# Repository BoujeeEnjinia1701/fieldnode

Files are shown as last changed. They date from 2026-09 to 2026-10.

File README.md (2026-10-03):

# FieldNode

     

**Area:** Shared Components · **TRL:** 3 of 9 (proof of concept on paper) · **Value-engineering target:** about $150 USD · **Difficulty:** 3 of 5

A solar-powered, weatherproof sensor node with a common mounting, power and radio core, so any lab project that needs to measure something outdoors starts from the same tested base instead of a new enclosure and charger each time.

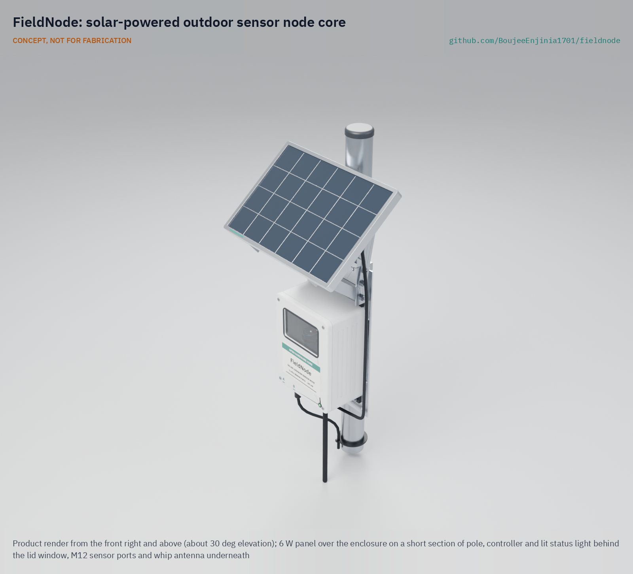
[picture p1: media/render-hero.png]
FieldNode: solar-powered outdoor sensor node core, product render


[Exploded render](media/render-exploded.png) · [Detail render](media/render-detail.png) · [Interactive 3D model](media/viewer.html) · [Concept blueprint (PDF)](media/concept-blueprint.pdf) · [General arrangement (PDF)](cad/drawings/FND-DWG-001.pdf) · [Calculations](docs/04-calcs/01-sizing.md) · [Prototype build plan](docs/05-build-plan.md) · [Review note](docs/REVIEW.md)

## Concept rationale

Outdoor sensing projects in the lab fail for the same few reasons: water gets in, the battery runs flat in a cloudy week, the charger overheats or will not charge in the cold, or the radio link drops. FieldNode solves these once. It pairs a stock IP65 enclosure with a 6 W panel that also hoods the box, a single LiFePO4 cell, an MPPT charger with a cold-charge lockout, and an STM32WL-class LoRaWAN module, with two sealed sensor ports. Each project then designs only its sensor and firmware, and a fix found in one deployment reaches all of them.

Keeping it open and garage-buildable matters because the users who most need monitoring are the least able to buy closed commercial nodes or pay for their clouds. Every part is off the shelf or cut from aluminium bar, angle and sheet with hand tools, the design files are under CERN-OHL-S-2.0, and the node talks to any LoRaWAN server, including the lab's TwinKit gateway and The Things Network.

## Burning platform

Monitoring is thinnest where hazards are greatest. Germany has more stations meeting the WMO Global Basic Observing Network standard than the whole of Africa ([WMO](https://wmo.int/media/news/closing-gaps-observing-network)). Only 108 countries, 55 % of the total, reported multi-hazard early warning systems in 2024, and fewer than half of the least developed countries did ([UNDRR and WMO, 2024](https://www.undrr.org/reports/global-status-MHEWS-2024)). The same report found that countries with limited early warning coverage have disaster mortality nearly six times higher than those with substantial coverage.

For air quality, 37 % of countries do not legally require monitoring at all ([UNEP, 2021](https://www.unep.org/news-and-stories/press-release/one-three-countries-world-lack-any-legally-mandated-standards)). Low-cost nodes can help close these gaps only if they survive in the field; long-running deployments report water ingress, cold-weather charging failures and radio problems as the main causes of lost data ([Barrenetxea et al., SenSys 2008](https://gsfr.github.io/pdf/sensys2008.pdf)).

## Where it could be used

### By industry

| Industry | Use |
| --- | --- |
| Water utilities and water resources | River, drain and well level logging (FloodGauge, WellSense, WaterWatch) |
| Disaster risk and civil protection | Slope movement, flood and heat sensing that feeds local early warning (SlopeWatch, HeatMap Node) |
| Municipal services and smart cities | Air, noise, parking and curb sensing on street poles, counts or levels only (AirStreet, NoiseMap, CurbCount, LoadZone) |
| Civil infrastructure and mining | Bridge vibration, tailings dam and pit wall tilt monitoring (BridgePulse, SlopeWatch) |
| Agriculture | Soil moisture, microclimate and grain store conditions at farms without power |
| Research and education | A documented, repeatable field platform for university and school projects |

### By country or region

| Country or region | Why it matters there |
| --- | --- |
| Sub-Saharan Africa | Weather observation is sparse: Germany alone has more GBON-standard stations than the whole continent ([WMO](https://wmo.int/media/news/closing-gaps-observing-network)). |
| India | Only about 12 % of 4,041 census cities and towns have air quality monitoring stations ([CSE, 2023](https://www.cseindia.org/only-12-per-cent-of-india-s-census-cities-and-towns-have-air-quality-monitoring-stations-11779)). |
| Least developed countries and small island states | Fewer than half of least developed countries report multi-hazard early warning systems; about two thirds of small island developing states do ([UNDRR and WMO, 2024](https://www.undrr.org/reports/global-status-MHEWS-2024)). |
| United States | The USGS runs about 12,165 streamgages ([USGS](https://www.usgs.gov/mission-areas/water-resources/science/usgs-national-streamgaging-network)), yet small streams, farm drains and urban culverts are mostly ungauged; low-cost nodes can fill local gaps. |
| European Union and United Kingdom | Dense official networks exist, but LoRa nodes must respect 1 % duty-cycle sub-bands in EU868 ([TTN, citing ETSI EN 300 220](https://www.thethingsnetwork.org/docs/lorawan/duty-cycle/)), so an open reference that stays within the rules is useful to community sensing groups. |

## What sparked the idea

The idea traces back to one of the first long outdoor wireless sensor deployments, on Great Duck Island, Maine, in 2003. Its 150 battery-powered nodes in sealed enclosures showed where field nodes fail: when the enclosures were opened, 22 % of the weather nodes had visible water droplets inside, and the multi-hop burrow nodes reached a median life of 34 days, under 45 % of their estimate ([Szewczyk et al., SenSys 2004](https://patpannuto.com/papers/szewczyk2004greatduckisland.pdf)). None of those failures came from the sensors; they came from the box, the seal and the power budget. FieldNode starts from that lesson: solve the enclosure, the energy budget and the radio once, check them on paper, and let every outdoor sensing project reuse the answer.

## Problem

Every outdoor sensing project rebuilds the same things: an enclosure that survives sun and rain, a small solar charger, a battery that lasts the night, and a low-power radio. Commercial nodes are closed or costly, and one-off builds fail in the field for the same few reasons.

## Concept

A solar-powered, weatherproof sensor node with a common mounting, power and radio core, so any lab project that needs to measure something outdoors starts from the same tested base instead of a new enclosure and charger each time.

Full design precis: [docs/02-concept.md](docs/02-concept.md)

## Key components

- IP65 polycarbonate enclosure, 150 x 90 x 200 mm, with membrane vent and two cable glands
- 6 W, 9 V class solar panel on a tilt bracket, doubling as a rain hood
- Ventilated white sun shield, fitted at hot-climate sites only
- LiFePO4 cell, 3.2 V 6 Ah, fused, with a 0 to 45 °C charge lockout
- MPPT charge and power board with switched 3.3, 5 and 12 V sensor rails and a serial programming header, reached with the lid open
- STM32WL-class microcontroller with LoRaWAN radio (US915 first variant, 915 MHz whip) and SPI flash for store and forward
- Two sealed M12 sensor ports with a proposed standard pinout (pin 1 switched rail, 2 data A, 3 ground, 4 data B, 5 analog), awaiting sign-off by the adopting projects
- Pole and wall mounting kit for 40 to 60 mm poles

TRL 3 calculations ([FND-CAL-001](docs/04-calcs/01-sizing.md)): in the worst month (2 peak sun hours) the cell stores 7.75 Wh a day against 2.67 Wh drawn at the published 100 mW sensor allowance, and a full cell lasts 5.75 days without sun. The base node costs $139.50 in parts and weighs 2.45 kg. At sites whose design maximum exceeds 30 °C a ventilated white sun shield is fitted ($148.50 and 2.61 kg in all), which keeps the inside at or below about 52 °C in 45 °C sun so the cell can still charge. The panel is 9 V class so the charger keeps its input voltage when hot, and firmware lengthens the reporting interval at slow spreading factors to stay within The Things Network's fair use. Two requirements remain at risk: charging on very cold days and autonomy with a cold or aged cell. See the [requirements](docs/03-requirements.md).

The working bill of materials is in [bom/bom.csv](bom/bom.csv).

## Building the prototype

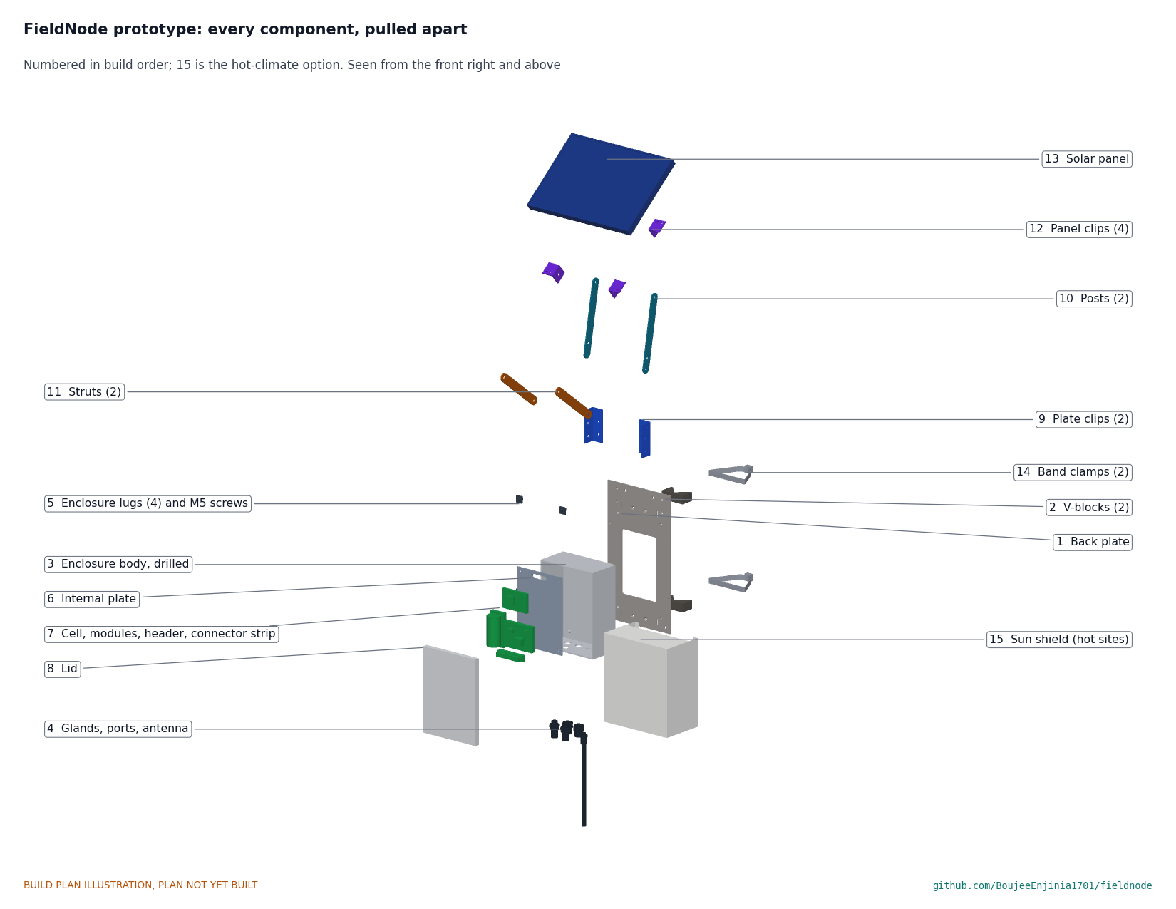
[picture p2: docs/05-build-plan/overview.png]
FieldNode prototype: every component pulled apart and numbered in build order


The [prototype build plan](docs/05-build-plan.md) (FND-BLD-001) shows, in pictures, how to make each of the fifteen components and put them together in twelve steps; nothing has been built yet. The made parts are an aluminium back plate and V-blocks, a bracket of angle clips and flat bars, a printed internal plate and a folded white sun shield; the bought box is drilled, and the electronics are bought modules wired at block level. Writing the plan made the design buildable: the V-blocks, the holes in the bottom of the box, the bracket joints and the shield fixing were redesigned, and fixings, a connector strip and sensor-supply fuses were added (FND-DDR-003, open for Amish's review). Every picture is drawn from the model, and the model checks that each part touches what it should and clears what it should not.

## Safety

> Lithium cells can overheat, vent and burn. Use protected cells or LiFePO4, fuse every pack, charge only within the cell maker's limits (for LiFePO4, typically 0 to 45 °C) and never leave a first build charging unattended.
>
> Mounting is work at height: use a stable ladder with a second person present, keep clear of overhead power lines, and check the pole or wall can carry the wind load on the panel.

## Repository layout

| Folder | Contents |
| --- | --- |
| `docs/` | Problem, concept, requirements, calculations and design decisions |
| `cad/src/` | build123d Python source, the source of truth for all geometry |
| `cad/step/`, `cad/stl/` | Exported models for FreeCAD, other CAD tools and printing |
| `cad/drawings/` | 2D sketches and dimensioned drawings |
| `bom/` | Bill of materials |
| `electronics/` | KiCad schematics and PCB layouts |
| `firmware/` | Microcontroller code |
| `media/` | Renders, perspectives and photos |
| `build-log/` | Dated prototyping notes |

## Documentation

Controlled documents follow the portfolio [documentation standard](.kit/STANDARDS.md). Each carries a document ID (FND-PRC-001 for the precis), a version and a revision history. Branded PDFs are built with `python .kit/render.py` and attached to GitHub Releases when a document is tagged, for example `FND-PRC-001/v1.0`.

## Credits

Designed by Amish Chadha. See [CONTRIBUTORS.md](CONTRIBUTORS.md) for roles. To cite this design, use [CITATION.cff](CITATION.cff) (GitHub shows it as "Cite this repository").

AI assistance (Claude) was used to accelerate concept renders, prototype documentation and first-pass sizing calculations. Design direction and all decisions are Amish Chadha's, recorded in this repository's decision records (`docs/decisions/`).

## Licenses

- **Hardware** (CAD, drawings, BOM, electronics): [CERN-OHL-S v2](LICENSE)
- **Software** (firmware, scripts, notebooks): [MIT](LICENSE-SOFTWARE)

A project of the [Design Molecule](https://designmolecule.com) lab.

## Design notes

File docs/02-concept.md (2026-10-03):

---
doc_id: FND-PRC-001
title: FieldNode design precis
project: FieldNode
doc_type: Design precis
version: "0.8"
status: Draft
date: '2026-10-02'
author: Amish Chadha
license: CERN-OHL-S-2.0
revisions:
- version: "0.1"
  date: '2026-09-25'
  author: Amish Chadha
  change: Initial scaffold
- version: "0.2"
  date: '2026-09-25'
  author: Amish Chadha
  change: Populate to TRL 2 (architecture, components, first-order numbers, safety, open questions)
- version: "0.3"
  date: '2026-09-25'
  author: Amish Chadha
  change: TRL 3 update; design choices adopted per FND-DDR-001 pending Amish's review; numbers checked against FND-CAL-001; parametric model and drawing FND-DWG-001; second gland fitted, ASA internal plate
- version: "0.4"
  date: '2026-09-25'
  author: Amish Chadha
  change: Recommendations accepted by Amish (DDR-002)
- version: "0.5"
  date: '2026-09-30'
  author: Amish Chadha
  change: "Design for construction (FND-DDR-003) applied; mass, cost, bracket, mounting and service figures updated; open for Amish's review"
- version: "0.6"
  date: '2026-10-01'
  author: Amish Chadha
  change: Budget treated as a value-engineering target
- version: "0.7"
  date: '2026-10-02'
  author: Amish Chadha
  change: "Pilot band, pinout and firmware update decisions of 2026-10-02 (FND-DEC-001)"
- version: "0.8"
  date: '2026-10-02'
  author: Amish Chadha
  change: "Approved follow-ups carried out: serial programming header on the power board, 915 MHz whip, US915 airtime and link, cost USD 139.50 (USD 148.50 with the shield)"
---

# FieldNode design precis

## Summary

FieldNode is a pole- or wall-mounted outdoor node built from a stock IP65 enclosure, a 6 W, 9 V class solar panel that doubles as a rain hood, a single 6 Ah LiFePO4 cell, an MPPT charge and power board, and an STM32WL-class LoRaWAN module. Two sealed M12 sensor ports carry power and data to whatever the host project measures, within a published sensor allowance of 100 mW. The TRL 3 calculations (FND-CAL-001 v0.2) confirm the worst-month energy budget: at 2 peak sun hours the cell stores 7.75 Wh a day against 2.67 Wh drawn at 100 mW, which lasts 5.75 days without sun. They also found the design's weak point: in full sun at 45 °C ambient the bare enclosure runs at 59 to 73 °C, above the 60 °C target, and the cell's 45 °C charge lockout then blocks charging for most of a hot, clear day. Amish decided on 2026-09-25 (FND-DDR-002) to fit a ventilated white sun shield, BOM line 14, at sites whose design maximum exceeds 30 °C; with it the inside stays at or below about 52 °C. The base node costs $139.50 in parts and weighs 2.45 kg; the hot-climate node costs $148.50 and weighs 2.61 kg. All design choices below are decided by Amish (FND-DDR-001 and FND-DDR-002); the changes made on 2026-09-30 so that every part can be made and fixed (FND-DDR-003, "Design for construction") are open for his review.

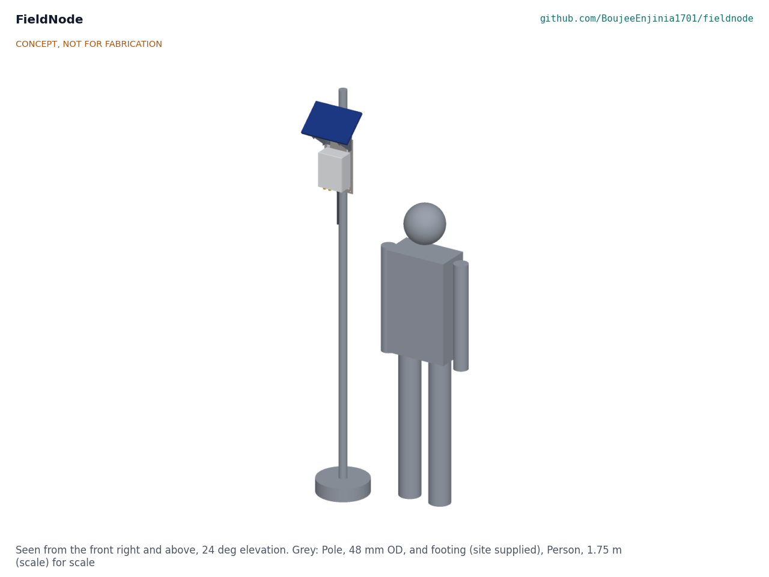
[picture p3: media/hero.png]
FieldNode concept


Figure 1. Node on a 48 mm pole, from the parametric model, with a 1.75 m person for scale. CONCEPT, NOT FOR FABRICATION.

## How it works

1. **Harvest.** The 6 W panel sits above the enclosure at a site-dependent tilt (40° shown), facing the equator. It sheds rain from the lid seam and shades most of the enclosure top, but not its front or sides (FND-CAL-001, section C).
2. **Charge and protect.** An MPPT-style charger on the power board holds the panel near its maximum power point and charges one LiFePO4 cell to 3.6 V. An NTC on the cell blocks charging below 0 °C and above 45 °C, since LiFePO4 cells are typically rated to charge only between 0 and 45 °C ([example cell specification](https://www.batteryspace.com/prod-specs/9055.pdf)). A protection IC and an inline fuse guard against over-discharge and short circuit.
3. **Power the sensors.** The board provides switched 3.3 V, 5 V and 12 V rails; each sensor port takes one of them, selected at build, so sensors draw nothing while the node sleeps.
4. **Measure and send.** The controller wakes on a timer, powers the sensor, reads it, stores the reading in SPI flash and sends a short LoRaWAN uplink to a TwinKit gateway, The Things Network or any LoRaWAN server. Readings are kept and resent when the link returns.
5. **Mount.** A 3 mm aluminium back plate with two V-blocks and two stainless band clamps fits 40 to 60 mm poles; the same plate screws to a wall. The enclosure hangs on the plate by four external lugs, and the panel bracket bolts to angle clips on the plate and on the panel frame.
6. **Shade, at hot sites.** Where the site's design maximum ambient exceeds 30 °C, a white aluminium shield is held to the back plate by four thumb screws and stands 15 mm off the enclosure's front, sides and top. Air enters at the open bottom and leaves through a slot at the back of the top sheet, so the box sits in moving shade.

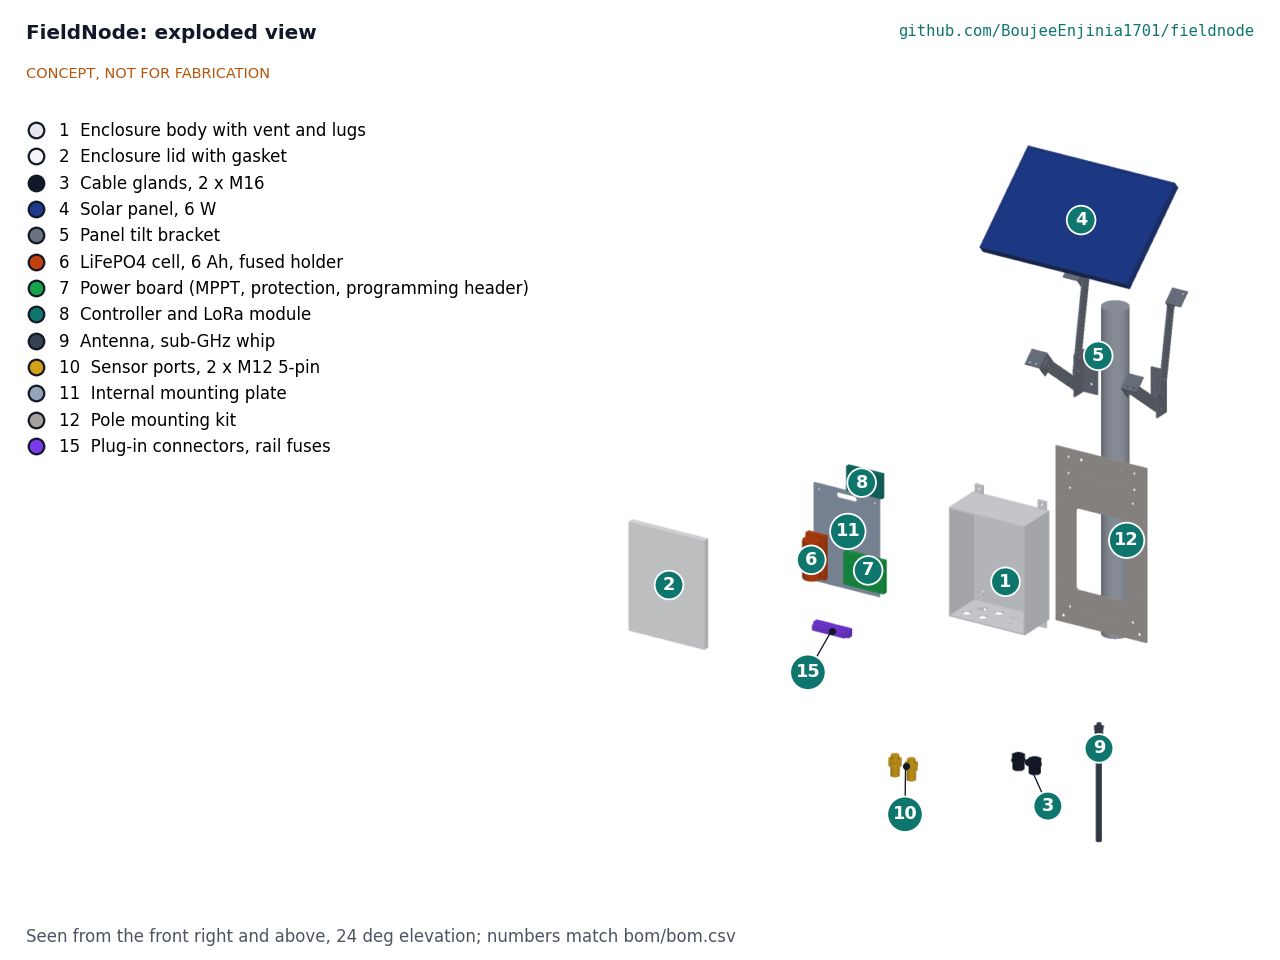
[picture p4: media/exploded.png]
Exploded view


Figure 2. Exploded view of the base node; callout numbers match `bom/bom.csv`. Line 13 (hardware) has no callout and line 14 (the shield option) is not shown.

## Main components

Table 1. Components (numbers match the BOM and Figure 2)

| No. | Component | Choice |
| --- | --- | --- |
| 1 | Enclosure body | Light grey polycarbonate, 150 x 90 x 200 mm (W x D x H), IP65 or better, with an ePTFE membrane vent on the bottom face to stop pumping of moist air |
| 2 | Lid | Supplied with the enclosure; gasketed, captive screws |
| 3 | Cable glands | Two M16: one for the panel lead, one for a sensor with its own cable (blanked when unused) |
| 4 | Solar panel | 6 W monocrystalline, 9 V class (Vmp about 9 V at 25 °C), about 290 x 200 mm |
| 5 | Panel tilt bracket | Two rear posts and two front struts in 20 x 3 mm aluminium flat bar, bolted flat to 30 x 30 x 3 mm angle clips on the back plate and on the panel frame's back lip; tilt set by hole position |
| 6 | Cell | LiFePO4 32700, 3.2 V, 6 Ah, in a holder with inline fuse and NTC |
| 7 | Power board | MPPT charger for 1S LiFePO4, protection, fuel gauge, switched 3.3, 5 and 12 V rails; a six-pin serial programming header facing the lid, wired to the controller, for firmware updates by cable with the lid open |
| 8 | Controller and radio | STM32WL-class module (for example RAK3172 or Wio-E5) on a carrier with SPI flash and status LED |
| 9 | Antenna | 915 MHz whip for the US915 first variant, about 190 mm, on a bottom bulkhead, pointing down |
| 10 | Sensor ports | Two M12 5-pin panel connectors with caps |
| 11 | Internal mounting plate | 3 mm printed ASA; carries cell and boards and lifts out as one unit |
| 12 | Pole mounting kit | Back plate 180 x 320 x 3 mm with a window behind the enclosure, two 60 x 33 x 20 mm V-blocks with a true 90° V, two stainless band clamps 250 mm apart; wall screws |
| 15 | Plug-in connectors and rail fuses | Pluggable terminal strip on the internal plate, so it lifts out as one unit; a resettable fuse on each sensor rail |
| 14 | Sun shield (hot-climate option) | White powder-coated aluminium sheet 0.5 mm, 181 x 106 x 206 mm, 15 mm off the enclosure, open bottom, 30 mm vent slot at the back of the top, lifts off after four thumb screws; fitted only where the design maximum exceeds 30 °C; not shown in the figures |

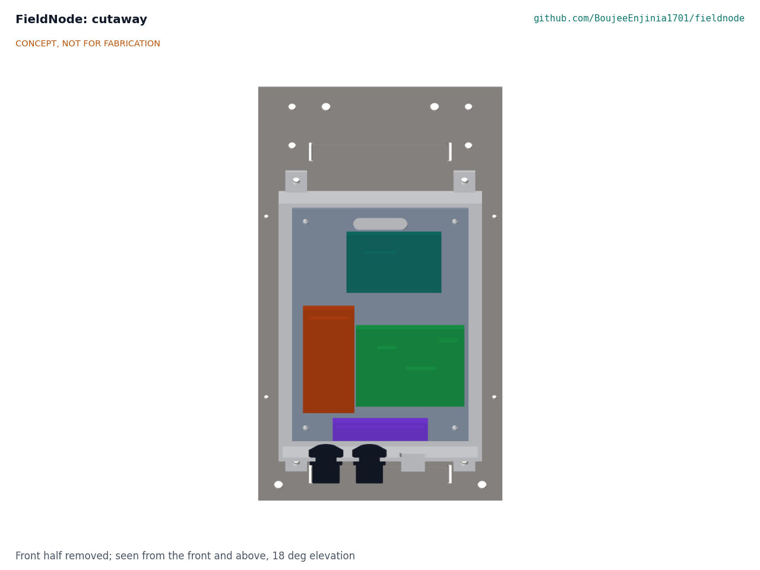
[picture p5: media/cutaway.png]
Cutaway


Figure 3. Cutaway from the front: cell (orange), power board (green) and controller (teal) on the internal plate.

The general arrangement, with the main dimensions and interfaces, is drawing FND-DWG-001 Rev P2 (`cad/drawings/FND-DWG-001.pdf`), generated from the parametric model `cad/src/model.py`. The model also exports the shield option as `cad/step/fieldnode-shield.step`.

## Numbers from the TRL 3 calculations

All values come from FND-CAL-001 v0.2, where the assumptions are stated. They are paper estimates, not measurements.

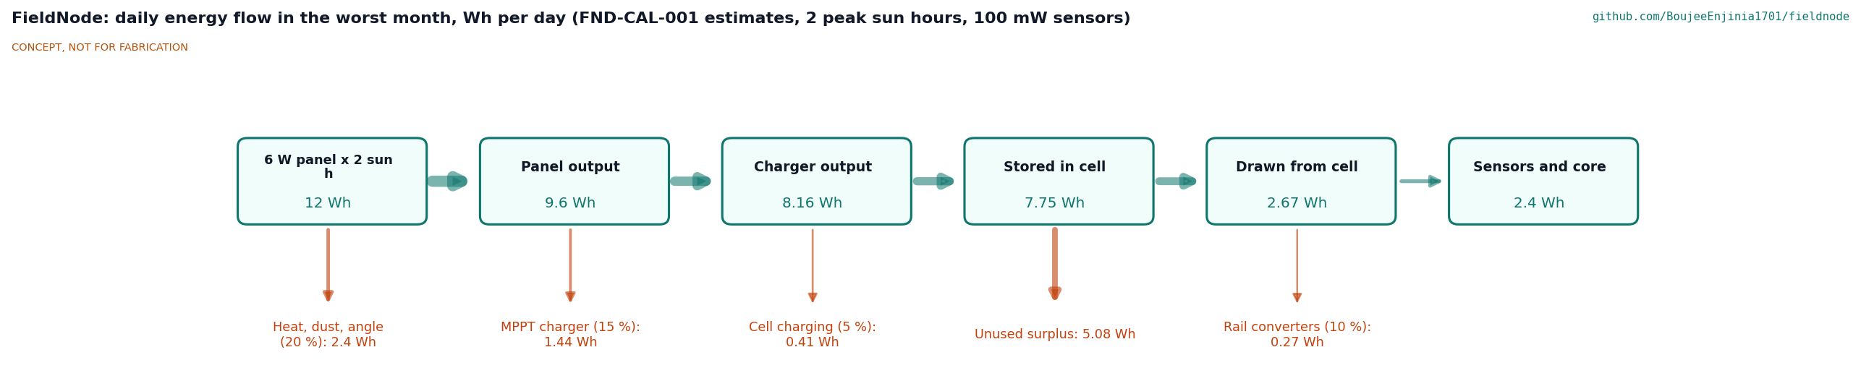
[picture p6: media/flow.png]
Energy flow


Figure 4. Daily energy flow in the worst month at the 100 mW design allowance (FND-CAL-001).

Table 2. Energy budget, worst month (2 peak sun hours)

| Quantity | Value | Assumption |
| --- | --- | --- |
| Panel rating times sun | 12.0 Wh/day | 6 W at 2 peak sun hours on the tilted panel |
| Panel output | 9.60 Wh/day | 20 % loss to heat, dust and angle |
| Charger output | 8.16 Wh/day | 85 % MPPT efficiency at 1S voltages |
| Stored in cell | 7.75 Wh/day | 95 % charge efficiency |
| Core consumption | 4.0 mWh/day | 96 SF9 uplinks and 33 µA sleep |
| Drawn from cell at 100 mW | 2.67 Wh/day | Rails 90 % efficient |
| Drawn from cell at 115 mW | 3.07 Wh/day | As above |
| Usable cell energy | 15.36 Wh | 3.2 V x 6 Ah x 80 % |
| Autonomy with no sun | 5.75 days at 100 mW; 5.00 days at 115 mW | 4.03 days at -20 °C and 4.60 days at end of life, at 100 mW |

**Sensor allowance.** The published allowance is 100 mW (FND-DDR-002), which gives 5.75 days without sun, a 15 % margin on R6. 115.0 mW would give exactly 5 days with no margin. Every sibling load quoted so far fits 100 mW except CurbCount, at about 300 mW.

**Heat and charging.** At 45 °C ambient the enclosure reaches 58.7 °C clean and 66.2 °C dusty on a hot design day, and up to 73.3 °C with the sun in its worst position. The cell is then above its 45 °C charge limit for most of the sunny day, and the node stores only 0.8 Wh on a hot clear day. The ventilated white shield holds the inside to 48.5 to 50.4 °C on the same day (52.2 °C with the sun in its worst position) and lets the node store 10.8 to 13.1 Wh. Without the shield the box stays at 60 °C or less up to about 31.7 °C ambient, so the shield is fitted where the site's design maximum exceeds 30 °C. In the cold, sun on the box lets the cell charge on clear days warmer than about -13 °C.

**Panel voltage.** In full sun on a hot day the 9 V class panel's maximum power voltage falls to about 7.42 V, 2.42 V above the 5 V minimum input of typical charger ICs. A 6 V class panel would fall to about 4.95 V, which is why the 9 V class was chosen. The charger part, chosen at TRL 4, must confirm both its minimum and maximum input.

**Airtime.** Table 3 gives airtime for a 20-byte payload (33 bytes on air) at 125 kHz. The Things Network allows 30 s of uplink airtime per node per day ([TTN fair use](https://www.thethingsnetwork.org/docs/lorawan/duty-cycle/)).

**Firmware airtime rule (FND-DDR-002).** On The Things Network the firmware keeps the 15 min default at SF7 to SF9 and, when adaptive data rate moves the node to SF10 or slower, lengthens the interval to 22 min at SF10, 48 min at SF11 and 87 min at SF12. Airtime then stays at 30 s a day or less at every spreading factor. On a private gateway only the regional duty cycle applies. In the US915 default first variant (FND-DEC-001) the 20-byte uplink cannot use SF10 (11-byte limit and the 400 ms dwell time), so the node stays at SF7 to SF9 and the 15 min default already fits; the rule matters on EU868 and similar bands. The SF9 link margin at 2 km is 18.2 dB at 915 MHz (18.6 dB at 868 MHz). This is a rule for the firmware; setting the region and writing the firmware are TRL 4 work.

Table 3. Airtime per day at a 15 min interval (96 uplinks)

| Spreading factor | Time on air per uplink | Per day | Within 30 s? |
| --- | --- | --- | --- |
| SF7 | 71.9 ms | 6.9 s | Yes |
| SF8 | 133.6 ms | 12.8 s | Yes |
| SF9 | 246.8 ms | 23.7 s | Yes |
| SF10 | 452.6 ms | 43.5 s | No; firmware rule sets 22 min |
| SF11 | 987.1 ms | 94.8 s | No; firmware rule sets 48 min |
| SF12 | 1,810 ms | 173.8 s | No; firmware rule sets 87 min |

**Link.** At +14 dBm with 2 dBi antennas and about -129.5 dBm sensitivity at SF9, the link budget is 145.0 dB. The Hata suburban model gives 126.4 dB of path loss to a 30 m gateway 2 km away, an 18.6 dB margin, and about 3.5 km of range with a 10 dB fade margin. Range depends on gateway height and clutter and needs a field survey.

**Store and forward.** Thirty days of readings take 90 kB of the 16 MB flash. Under The Things Network's fair use a 30-day backlog at SF9 would take about 68 days to resend, so backlogs are best sent through a private gateway.

**Wind.** At 35 m/s the dynamic pressure is 750 Pa: 52.2 N on the panel and 29.3 N on the enclosure (36.3 N on the shield where fitted). Wind from behind gives 14.8 N·m about the lower clamp and pulls the upper clamp with 59 N (63 N with the shield), against about 2,000 N of assumed clamp preload. The bracket's flat bars carry at most about 39 N.

**Mass.** 2.45 kg for the base node: enclosure with lugs 0.43 kg, back plate and V-blocks 0.48 kg, bracket 0.22 kg, internal plate 0.07 kg and bought parts 1.24 kg (panel 0.55 kg). The TRL 2 estimate of 1.7 kg under-counted the back plate. The shield adds 0.16 kg (2.61 kg); R14 applies to the base node.

**Cost.** Value-engineering target: USD 150. Estimated cost of the constructable design: USD 139.50 in parts at quantity 1 for the base node (USD 10.50 under the target; see `bom/bom.csv`); USD 148.50 with the shield (USD 1.50 under the target). The gateway is not included.

## Key design choices

These choices are decided by Amish, 2026-09-25: go with recommendation (FND-DDR-001, D1 to D12, and FND-DDR-002).

1. **LoRaWAN rather than Wi-Fi, cellular or LoRa point-to-point.** Kilometer range at milliwatt average power, open network servers, and a match with the TwinKit gateway's LoRa concentrator. Cellular stays a later variant.
2. **STM32WL-class single-chip module.** Radio and controller in one low-sleep-current part, with LoRaWAN stacks that are open source.
3. **One LiFePO4 cell rather than Li-ion.** LiFePO4 is less prone to thermal runaway and tolerates heat better, at the cost of lower energy density. A single cell keeps the charger simple and avoids balancing. CellGuard covers 4 to 16 cell packs, so FieldNode uses a 1S protection IC on its own power board.
4. **6 W panel as standard, 9 V class**, with 3 W and 10 W variants kept as later options. The 9 V class keeps voltage headroom for the charger when hot.
5. **Panel as rain hood and partial sun shade** over the enclosure. FND-CAL-001 shows it does not shade enough for hot climates on its own, so a ventilated white shield is added at sites whose design maximum exceeds 30 °C (choice 12).
6. **Antenna pointing down** below the enclosure, out of the panel's shadow and away from hands at the lid.
7. **M12 5-pin sensor ports** rather than bare glands, so sensors can be swapped without opening the box; a gland remains for sensors with fixed cables. Pinout: pin 1 switched rail, pin 2 data A, pin 3 ground, pin 4 data B, pin 5 analog, the proposed standard decided by Amish on 2026-10-02 and awaiting sign-off by the adopting projects (FND-DEC-001).
8. **Mounting above head height** (1.75 m to the enclosure base) to reduce tampering while staying reachable from a short ladder.
9. **Default 15 min reporting interval**, adjustable from 1 min to 24 h within airtime limits, with the firmware airtime rule above on The Things Network.
10. **TwinKit gateway as the default network**, with The Things Network as the public fallback.
11. **Stock polycarbonate IP65 enclosure** rather than a printed one.
12. **Sun shield only at hot-climate sites** (design maximum above 30 °C), so the base node stays light and cheap; R14 applies to the base node.
13. **Published sensor allowance 100 mW** rather than 115 mW, for a 15 % autonomy margin.

## Relationship to other lab projects

- **TwinKit** is the default gateway and data platform; FieldNode sends standard LoRaWAN uplinks, so any LoRaWAN server also works. TwinKit's recommended 8-channel LoRaWAN concentrator matches choice 1.
- **CalRig** is where sensors should be checked before and after deployment; SensorScope found offsets over 2 °C in pre-deployment checks ([Barrenetxea et al., 2008](https://gsfr.github.io/pdf/sensys2008.pdf)).
- **CellGuard** is not used, because it targets 4 to 16 cell packs; see choice 3.
- Adopting projects named in their READMEs include AirStreet, BridgePulse, CurbCount, FloodGauge, HeatMap Node, LoadZone, NoiseMap, SlopeWatch and WellSense. Several of them cost the FieldNode core at about $126 and plan against a 115 mW allowance; the published allowance is now 100 mW, and updating those notes is listed as a cross-repo action in `docs/REVIEW.md`.

## Safety

> **Safety:** The node contains a lithium iron phosphate cell of about 19 Wh. Fuse the cell at the holder, use a protection circuit, and never charge below 0 °C or above 45 °C. Do not install or charge a cell that is swollen, damaged or wet. Store and transport spare cells at partial charge. In hot climates the bare enclosure can exceed 60 °C in sun; fit the sun shield wherever the design maximum exceeds 30 °C, and never defeat the charge lockout to gain energy.

> **Safety:** Work at height. Mount from a stable ladder or platform with a second person present, and never on a pole carrying power lines unless the utility authorizes it. Check that the pole and wall anchors can carry the wind load, about 80 N at 2 m, before fitting the panel, and tighten both band clamps to the maker's torque.

> **Safety:** Glass-fronted panels and cut aluminium bar have sharp edges; deburr all cut parts and wear gloves. Keep the antenna and node clear of overhead conductors.

## Open questions

- [ ] Which two lab projects adopt FieldNode first. The band is decided (Amish, 2026-10-02, FND-DEC-001): US915 with a 915 MHz whip is the default first variant, switching to EU868, AS923 or IN865 if the first adopting project's site is outside North America.
- [ ] Sign-off of the proposed standard pinout (pin 1 switched rail, pin 2 data A, pin 3 ground, pin 4 data B, pin 5 analog) by HeatMap Node and the next adopting project (decided by Amish as the proposal, 2026-10-02, FND-DEC-001).
- [x] Firmware update method in the field: by cable inside the box with the lid open, through a six-pin serial header on the power board, facing the lid (the STM32WL-class module has no USB port), with no extra hole in the enclosure; over the air is left for a later private-gateway variant (Amish, 2026-10-02, FND-DEC-001).

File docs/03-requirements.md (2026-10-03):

---
doc_id: FND-REQ-001
title: FieldNode requirements
project: FieldNode
doc_type: Requirements
version: "0.8"
status: Draft
date: '2026-10-02'
author: Amish Chadha
license: CERN-OHL-S-2.0
revisions:
- version: "0.1"
  date: '2026-09-25'
  author: Amish Chadha
  change: Initial scaffold
- version: "0.2"
  date: '2026-09-25'
  author: Amish Chadha
  change: First measurable requirements for TRL 2, with concept status against each
- version: "0.3"
  date: '2026-09-25'
  author: Amish Chadha
  change: TRL 3 status from FND-CAL-001; R11 and R16 restated to match FND-DDR-001 (D5 and the FieldNode core costing)
- version: "0.4"
  date: '2026-09-25'
  author: Amish Chadha
  change: Recommendations accepted by Amish (DDR-002)
- version: "0.5"
  date: '2026-09-30'
  author: Amish Chadha
  change: "Design for construction (FND-DDR-003) applied; mass, cost, bracket, mounting and service figures updated; open for Amish's review"
- version: "0.6"
  date: '2026-10-01'
  author: Amish Chadha
  change: Budget treated as a value-engineering target
- version: "0.7"
  date: '2026-10-02'
  author: Amish Chadha
  change: "R11 status: pinout decided as the proposed standard (FND-DEC-001, 2026-10-02)"
- version: "0.8"
  date: '2026-10-02'
  author: Amish Chadha
  change: "Approved follow-ups carried out (FND-CAL-001 v0.6): R8 and R9 values for US915, R16 cost with the programming header; no status changed"
---

# FieldNode requirements

Fifteen of the eighteen requirements are met on paper or by design, two are at risk, none is missed and one can only be verified by a timed installation (FND-CAL-001 v0.6, Table 4). Amish accepted the TRL 3 recommendations on 2026-09-25 (FND-DDR-002), and three targets are restated to match: R3 now requires the sun shield where the site's design maximum ambient exceeds 30 °C, R9 applies on The Things Network with a firmware rule that lengthens the interval at slow spreading factors, and R14 applies to the base node without the hot-climate shield. R7 is unchanged at 100 mW, which is now the published allowance. R11 and R16 stay as restated in v0.3 to match FND-DDR-001. The status column gives the standing from FND-CAL-001; "Met on paper" means shown by calculation, not by test.

Table 1. Requirements and status at TRL 3

| ID | Requirement | Target | Verification (TRL 3 or later) | Status (FND-CAL-001) |
| --- | --- | --- | --- | --- |
| R1 | Weather protection | Enclosure IP65 or better with membrane vent; all penetrations sealed glands or rated connectors | Enclosure rating; later spray test | Met by design: IP65 box, ePTFE vent, two IP68 glands, capped IP67 ports and bulkhead |
| R2 | Operating temperature | -20 to +45 °C ambient; electronics rated -20 to +70 °C inside the enclosure | Datasheets; thermal calculation | **At risk (cold):** warm end covered (52.2 °C dusty worst case with the shield at 45 °C; 58.3 °C unshielded at 30 °C); no charging on clear days colder than about -13 °C |
| R3 | Interior temperature in sun | 60 °C or less inside the enclosure in full sun, still air, at the site's design maximum ambient up to 45 °C; the ventilated sun shield (BOM line 14) is fitted wherever that maximum exceeds 30 °C | Thermal calculation; later test in sun | Met on paper: with the shield at 45 °C, 48.5 °C clean, 50.4 °C dusty, 52.2 °C worst sun position; unshielded at 30 °C, 58.3 °C worst sun position; shield factor assumed |
| R4 | Safe charging window | Cell charging blocked below 0 °C and above 45 °C by an NTC on the cell | Charger design review | Met by design |
| R5 | Energy neutral in the worst month | Daily harvest exceeds full-load demand at 2 peak sun hours | Energy budget | Met on paper: 7.75 Wh stored against 2.67 Wh drawn in the worst month; 10.8 to 13.1 Wh stored on a hot clear day with the shield; 9 V class panel keeps 2.42 V above the charger minimum input when hot |
| R6 | Autonomy without sun | 5 days or more at full sensor allowance, starting from 80 % charge usable | Energy budget | **At risk (cold or aged cell):** 5.75 days at the published 100 mW, a 15 % margin; 4.03 days at -20 °C and 4.60 days at end of life |
| R7 | Sensor power allowance | 100 mW average or more available to the sensor ports; 100 mW is the published allowance | Energy budget | Met on paper: 100 mW published; 115.0 mW is the ceiling for exactly 5 days |
| R8 | Radio link | LoRaWAN uplink to a gateway 2 km away in suburban terrain at SF9 or faster | Link budget; later field test | Met on paper: 18.2 dB margin at 2 km to a 30 m gateway at 915 MHz, the US915 default first variant (18.6 dB at 868 MHz) |
| R9 | Airtime within fair use | 30 s uplink airtime per day or less on The Things Network; firmware keeps the 15 min default at SF7 to SF9 and lengthens the interval at SF10 and slower (22 min at SF10, 48 min at SF11, 87 min at SF12) | Airtime calculation; later firmware review | Met on paper: 23.7 s at SF9; 30.0 s or less at every spreading factor under the rule; in the US915 default first variant the node uses SF7 to SF9 only (23.7 s at most) |
| R10 | Store and forward | 30 days or more of readings kept on the node when the link is down | Memory calculation | Met on paper: 30 days in 90 kB of 16 MB |
| R11 | Standard sensor interface | Two sealed M12 5-pin ports, each carrying I2C, UART or RS-485, one analog input and one switched rail selectable at 3.3, 5 or 12 V; a gland for fixed-cable sensors | Pinout review with adopting projects | Met on paper; pinout decided as the proposed standard (pin 1 switched rail, 2 data A, 3 ground, 4 data B, 5 analog), awaiting sign-off by the adopting projects (FND-DEC-001, 2026-10-02) |
| R12 | Mounting and install | Fits 40 to 60 mm poles and flat walls; one person installs in 15 min or less with hand tools | Design review; later timed install | Fit met by design (seats 40 to 71 mm); time estimated at 15 min, not verifiable at TRL 3 |
| R13 | Wind | Survives 35 m/s (126 km/h) gusts on the panel without loosening | Load calculation | Met on paper: clamp pull 59 N against 2,000 N; band preload assumed |
| R14 | Mass | 2.5 kg or less for the base node, including panel and mounts; the hot-climate sun shield is excluded | Massing model, then weighing | Met on paper: 2.45 kg, a thin 0.05 kg margin on catalogue masses after the design for construction (FND-DDR-003); 2.61 kg with the shield |
| R15 | Serviceable | Cell replaced in 10 min or less with a screwdriver; no soldering in the field | Design review | Met by design: about 7 min; about 9 min where the shield is fitted, since it lifts off after four thumb screws |
| R16 | Cost | FieldNode core (enclosure, power, radio, panel and mounting) at the $150 value-engineering target or under at quantity 1 (a hypothetical control target); sensors and gateway excluded | Priced BOM | Met on paper, within the value-engineering target: $139.50 base node ($10.50 under); $148.50 with the shield ($1.50 under) |
| R17 | Open and independent | All design files under CERN-OHL-S-2.0 and MIT; works with any LoRaWAN network server, no closed cloud | Design review | Met by design |
| R18 | Privacy pass-through | The core sends only what the sensor firmware passes to it; no images or audio leave the node | Firmware design review | Met by design; each project states its own rule |

## Requirements at risk

- **R2 (cold charging) at risk.** In the cold the cell charges only on clear days warmer than about -13 °C, so an overcast freeze longer than the cold autonomy will stop the node. The warm end is now covered by the shield at hot sites.
- **R6 (autonomy) at risk for a cold or aged cell.** At the published 100 mW a new cell lasts 5.75 days, but 4.03 days at -20 °C and 4.60 days at end of life.

Resolved by FND-DDR-002 on paper: R3 (shield at sites above 30 °C), R5 (shield and 9 V class panel), R9 (firmware interval rule) and R14 (base node). R3 and R5 rest on an assumed shield factor that only a test can confirm; testing is TRL 4 work and on hold.

## Assumptions

- Assumptions for every status above are stated in FND-CAL-001, Table 1. The main ones: worst month 2 peak sun hours on the tilted panel; panel, dust and angle losses 20 %; MPPT charger 85 %; cell charge 95 %; rail converters 90 %; LiFePO4 cell 3.2 V, 6 Ah (about 19 Wh), 80 % usable.
- Uplink payload 20 bytes plus 13 bytes of LoRaWAN overhead, 125 kHz bandwidth, coding rate 4/5, 8-symbol preamble.
- Core consumption from SX1262 datasheet figures ([Semtech SX1261/2 datasheet](https://cdn.sparkfun.com/assets/6/b/5/1/4/SX1262_datasheet.pdf)): 4.0 mWh a day.

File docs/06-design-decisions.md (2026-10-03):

---
doc_id: FND-DEC-001
title: FieldNode design decisions register
project: FieldNode
doc_type: Design decisions register
version: "0.4"
status: Draft
date: '2026-10-02'
author: Amish Chadha
license: CERN-OHL-S-2.0
revisions:
- version: "0.1"
  date: '2026-09-30'
  author: Amish Chadha
  change: Register opened; open decisions moved out of the build plan
- version: "0.2"
  date: '2026-10-01'
  author: Amish Chadha
  change: Budget treated as a value-engineering target
- version: "0.3"
  date: '2026-10-02'
  author: Amish Chadha
  change: "Amish approved the recommendations for open decisions 1 to 3 (FND-DDR-001, O1 to O3); moved to decisions made"
- version: "0.4"
  date: '2026-10-02'
  author: Amish Chadha
  change: "Value engineering updated after the approved follow-ups: USD 139.50 base node, USD 148.50 with the shield (programming header on line 7)"
---

# FieldNode design decisions register

Every design decision still to be made, and every decision made, in one place. Each decision is argued in full in its decision record under `docs/decisions/`; this register is the index Amish works from. The build plan (`docs/05-build-plan.md`) describes the design as it stands and does not list open decisions.

## Open decisions

None. All open decisions were decided on 2026-10-02.

## To confirm when parts are bought

| # | What to confirm | Why it matters | Source |
| --- | --- | --- | --- |
| 1 | The solar panel frame has a flat back lip at least 12 mm wide | The panel clips bolt through it; without it the clip position changes | FND-DDR-003 |
| 2 | The enclosure model, its boss spacing and its lug kit | They set the internal plate holes and the lug positions | FND-DDR-003 |
| 3 | The band clamp torque that gives 1,000 N of preload | The calculation note assumes that preload | FND-CAL-001 |

## Value engineering

Value-engineering target: USD 150 (a hypothetical control target, not a limit). Estimated cost of the constructable design: USD 139.50 (USD 10.50 under the target) for the base node; USD 148.50 with the sun shield (USD 1.50 under the target). Main cost drivers and savings worth trying:

- The largest lines are the power board (USD 22.50, a prototype carrier price including the USD 0.50 serial programming header added for the 2026-10-02 firmware update decision; the board design is TRL 4 work), the enclosure with vent and lug kit (USD 20), the solar panel (USD 14), the controller and LoRa module (USD 14) and the antenna (USD 10).
- Making the design constructable repriced lines 1, 5, 13 and 14 and added line 15, the plug-in connectors and rail fuses (USD 5); the base node rose from USD 126 to USD 139. The programming header (2026-10-02) adds USD 0.50; the 915 MHz whip costs the same as the band-specific whip it names.
- Savings worth trying: the sun shield (USD 9) is an option for hot-climate sites only, so the base node carries none; the power board price should fall once its design is done.

## Decisions made

| Date | Decision | Decided by | Record |
| --- | --- | --- | --- |
| 2026-09-25 | TRL 2 review items D1 to D12 (LoRaWAN, STM32WL-class module, one 6 Ah LiFePO4 cell, 6 W panel, two M12 ports, 15 min interval and others) | Amish: "i accept all your recommendations, go with them across all repos." | FND-DDR-001, FND-DDR-002 |
| 2026-09-25 | Sun shield for hot-climate sites only; base node mass limit 2.5 kg; 9 V class panel; 100 mW sensor allowance; airtime rule at slow spreading factors | Amish: go with recommendation | FND-DDR-002 |
| 2026-09-30 | Design for construction: V-blocks, bottom-face layout, bracket, shield fixing, connector strip, enclosure lugs and other changes that make the node buildable | Amish: "i accept your recommended changes on design that are currently being sent across for my approval" | FND-DDR-003 |
| 2026-09-30 | Thumb screws on the shield for the prototype; 5 mm spacers for wall mounting; accept the 0.05 kg mass margin and weigh at TRL 4; fit the shield on the first prototype | Amish, same instruction | FND-DDR-003, A1 to A4 |
| 2026-10-02 | Pilot region and radio band: US915 (North America) is the default first variant with a 915 MHz whip; the band switches to that of the first adopting project's site if it is outside North America (EU868, AS923 or IN865) | Amish: "i approve your recommendations for all 555 open decisions." | FND-DDR-001, O1 |
| 2026-10-02 | Sensor port pin assignment: the candidate pinout of FND-CAL-001 is the proposed standard (pin 1 switched rail, pin 2 data A, pin 3 ground, pin 4 data B, pin 5 analog), sent to HeatMap Node and the next adopting project for sign-off | Amish: "i approve your recommendations for all 555 open decisions." | FND-DDR-001, O2 |
| 2026-10-02 | Firmware update method in the field: by cable inside the box with the lid open (a USB or serial header on the board, no extra hole in the enclosure); over-the-air updates left for a later private-gateway variant | Amish: "i approve your recommendations for all 555 open decisions." | FND-DDR-001, O3 |

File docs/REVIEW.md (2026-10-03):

# Review note: FieldNode

## Session 2026-09-25: /populate to a strong TRL 2

### What was done

- `docs/01-problem.md` (FND-PRB-001 v0.2): problem with cited evidence, users, operating environment, constraints, out of scope, co-design checklist, open questions.
- `docs/03-requirements.md` (FND-REQ-001 v0.2): 18 measurable requirements (R1 to R18) with targets and a concept status column, plus assumptions.
- `docs/02-concept.md` (FND-PRC-001 v0.2): how it works, 12 numbered components, energy budget, core consumption, airtime table, link budget, wind load, mass, cost, proposed design choices, links to sibling projects, safety, open questions.
- `cad/src/concept_media.py`: massing model of the node on a 48 mm pole (enclosure body and lid, internal plate with cell, power board and controller, gland, M12 ports, antenna, panel, bracket, mounting kit). Pole and a 1.75 m person are context parts in the hero, since the kit's automatic scale figure stands on the lowest part and would float at node height. The scene is shifted so the enclosure is near Z = 0, because the kit's cutaway cutter is centered on Z = 0.
- `media/`: hero, blueprint sheet (PNG, PDF, SVG), exploded view with callouts 1 to 12, cutaway, worst-month energy flow, `model.glb` and `viewer.html`. Temporary `_views` folders removed.
- `bom/bom.csv` (13 lines, indicative prices) and `bom/bom-notes.md`.
- `README.md`: hero and links line; concept rationale, burning platform, industry and region tables and trigger expanded with cited sources; key components and safety updated.
- `docs/pdf/`: branded PDFs of the three controlled documents.

### Key results (estimates, to be checked at TRL 3)

| Quantity | Estimate | Requirement |
| --- | --- | --- |
| Stored energy, worst month (6 W, 2 sun h) | about 7.8 Wh/day | R5 met |
| Full-load draw from cell | about 3.1 Wh/day | |
| Sensor allowance | about 115 mW average (2.75 Wh/day) | R7 met |
| Autonomy with no sun | about 5.0 days | R6 met, no margin |
| Core consumption | about 4 mWh/day | |
| Airtime, 20-byte uplink every 15 min | about 24 s/day at SF9, 43 s/day at SF10 | **R9 not met at SF10 or slower** |
| Link budget at SF9 | about 145 dB | R8 unverified |
| Wind load on panel at 35 m/s | about 52 N, about 16 N·m | R13 unverified |
| Mass | about 1.7 kg | R14 met |
| Parts cost | about $126 | R16 met (budget $150) |

Requirements not met or at risk:

- **R3 (interior 60 °C or less at 45 °C ambient, full sun) not shown.** The panel hood helps, but there is no estimate with margin.
- **R9 (30 s/day airtime) not met at SF10 or slower** at the 15 min default; distant nodes need 30 min or longer intervals.
- **R6 (5 days autonomy)** has no margin.
- **R2, R8 and R13** depend on unverified estimates.

### Proposed, awaiting Amish (status updated 2026-09-25, FND-DDR-002)

1. **Radio.** Options: LoRaWAN (recommended), LoRa point-to-point, or cellular LTE-M/NB-IoT. Recommendation: LoRaWAN now; cellular as a later variant. **Decided by Amish, 2026-09-25: go with recommendation.**
2. **Controller module.** Options: STM32WL-class module such as RAK3172 or Wio-E5 (recommended), ESP32 plus SX1262, or nRF52840 plus SX1262. **Decided by Amish, 2026-09-25: go with recommendation.**
3. **Energy storage.** Options: one 6 Ah LiFePO4 cell with a 1S protection IC on the power board (recommended), 2 to 3 Li-ion 18650 cells, or a small CellGuard pack. CellGuard covers 4 to 16 cells, so it does not fit a 1S node; a note to the CellGuard project may be worth adding. **Decided by Amish, 2026-09-25: go with recommendation.**
4. **Panel size.** 6 W standard (recommended), with 3 W and 10 W variants for low- and high-power payloads as a later option. **Decided by Amish, 2026-09-25: go with recommendation.**
5. **Sensor port standard.** Two M12 5-pin ports carrying I2C, UART or RS-485, one analog input and switched rails (recommended), versus glands only. Pinout to be agreed with the first two adopting projects. **Decided by Amish, 2026-09-25: go with recommendation.**
6. **Default reporting interval** of 15 min. **Decided by Amish, 2026-09-25: go with recommendation.**
7. **Default network.** TwinKit gateway first, with The Things Network as the public fallback (recommended). **Decided by Amish, 2026-09-25: go with recommendation.**
8. **First adopting projects and region** (which set the radio band). No recommendation; still Proposed, awaiting Amish.
9. **Enclosure.** Stock polycarbonate IP65 box (recommended) versus a printed ASA enclosure. **Decided by Amish, 2026-09-25: go with recommendation.**
10. No change is proposed to `budget_usd`, the pitch or the problem in `project.yaml`. **Decided by Amish, 2026-09-25: go with recommendation.**

### Safety concerns

- About 19 Wh LiFePO4 cell left unattended outdoors: fuse, protection IC and NTC-gated charging between 0 and 45 °C; interior heat (R3) directly affects cell life and safety.
- Work at height during installation, and proximity to overhead power lines on street poles.
- Wind load on the panel; a loosened clamp could drop the node.
- Sharp edges on cut aluminium and glass-fronted panels.

### Problems and notes

- The cutaway is a front section. The sensor ports and gland fall in the removed half, so they appear only in the exploded view.
- The kit's `render_all` places the automatic scale figure at the lowest part's Z, and its cutaway cutter is centered at Z = 0. Both were worked around in `concept_media.py`; a kit fix may help other pole-mounted repos.
- The legacy `cad/src/model.py` placeholder is untouched (TRL 3 work).
- Sibling READMEs (AirStreet, BridgePulse, CurbCount, FloodGauge, HeatMap Node, LoadZone, NoiseMap, SlopeWatch, TwinKit, WellSense) all describe FieldNode as a power and radio core with LoRa; this concept matches them.

### Recommended next step

Review this note and the media, then decide items 1 to 5 and 8. If approved, run `/advance-trl3` to check the energy budget, interior temperature, link budget and wind load by calculation and to produce the parametric model and drawing sheet.

## Session 2026-09-25: TRL 3

On 2026-09-25 Amish asked for this batch of repos to go through the usual process with the instruction "you know the drill, nothing gets past TRL 3". He has not reviewed this repo's TRL 2 items one by one, so every item that carried a recommendation is adopted as recommended for TRL 3 under Amish's 2026-09-25 instruction, open for his review. This session ran `/advance-trl3` on that basis and stopped at TRL 3.

### What was done

- `docs/decisions/0001-trl2-review-decisions.md` (FND-DDR-001 v0.1, status proposed): twelve items adopted as recommended for TRL 3, open for Amish's review (D1 to D12), and three left open (O1 to O3).
- `docs/04-calcs/01-sizing.md` (FND-CAL-001 v0.1) and `docs/04-calcs/sizing.py`: core consumption, energy budget and autonomy, airtime, link budget, store and forward, enclosure temperature and charging window on hot and cold design days, panel voltage, wind and mounting, installation and service times, mass and cost, with a status for every requirement. The script imports the model, reads the BOM and `project.yaml`, prints every number the note quotes and writes `docs/04-calcs/results.csv`.
- `cad/src/model.py`: parametric build123d model (enclosure, lid, two glands, two M12 ports, antenna, internal plate, cell, power board, controller, panel, flat-bar bracket, back plate, V-blocks and band clamps on a 48.3 mm pole). Exports `cad/step/` and `cad/stl/` for `fieldnode-assembly`, `fieldnode-core` and `fieldnode-mount`.
- `cad/src/sheets.py` and `cad/drawings/FND-DWG-001.svg`, `.pdf`, `.png`: general arrangement at Rev P1, 1:10, marked "CONCEPT, NOT FOR FABRICATION" and "PRELIMINARY, NOT FOR FABRICATION". FND-DWG-001 was free because the concept blueprint is FND-DWG-010.
- `bom/bom.csv` (13 lines, all priced with a supplier or supplier type, $126.00 against the $150 budget) and `bom/bom-notes.md`. Two changes, total unchanged: both glands are now fitted, because the panel lead needs one; the internal plate is printed ASA.
- `cad/src/concept_media.py` now builds from the model; all of `media/` was re-rendered and every image checked; temporary `_views` folders deleted.
- FND-PRB-001, FND-PRC-001 and FND-REQ-001 revised to v0.3; `README.md` (TRL line, links, key figures) and `project.yaml` (`trl: 3`, `trl_target: 3`, evidence list) updated. PDFs rebuilt in `docs/pdf/`.

### Requirement status (FND-CAL-001, Table 4)

1 not met, 5 at risk, 6 met on paper, 5 met by design, 1 not verifiable at TRL 3.

| ID | Status | Key number |
| --- | --- | --- |
| R3 Interior temperature | **Not met** | 58.7 °C clean, 66.2 °C dusty on a 45 °C design day; 63.3 to 73.3 °C with the sun in its worst position (target 60 °C); 48.5 °C with a shield |
| R2 Operating temperature | At risk | Dusty worst case 73.3 °C against the 70 °C electronics rating; no charging on clear days below about -13 °C |
| R5 Energy neutral | At risk | Worst month 7.75 Wh stored against 2.67 Wh drawn, but a hot clear day stores 0.8 Wh because the cell is above 45 °C; 6 V class panel Vmp 4.95 V when hot |
| R6 Autonomy | At risk | 5.75 days at 100 mW; exactly 5.00 days at 115 mW; 4.03 days at -20 °C; 4.60 days at end of life |
| R9 Airtime | At risk | 23.7 s/day at SF9; not met at SF10 (43.5 s) to SF12 at 15 min |
| R14 Mass | At risk | 2.41 kg against 2.5 kg (TRL 2 said 1.7 kg); 2.56 kg with a shield |
| R12 Install | Not verifiable at TRL 3 | Fit met by design (40 to 71 mm poles); 15 min estimate, at the limit |
| R7, R8, R10, R11, R13, R16 | Met on paper | 115.0 mW ceiling; 18.6 dB link margin at 2 km; 30 days in 90 kB; pin count; clamp pull 59 N against 2,000 N; $126.00 |
| R1, R4, R15, R17, R18 | Met by design | |

Key numbers: core 4.0 mWh/day; 145.0 dB link budget at SF9; 52.2 N on the panel at 35 m/s; bracket buckling factor 32.

### Decisions recorded (FND-DDR-001)

Decided by Amish, 2026-09-25: go with recommendation (FND-DDR-002; recorded at the time of this session as adopted for TRL 3, open for his review): D1 LoRaWAN, cellular later; D2 STM32WL-class module; D3 one 6 Ah LiFePO4 cell with its own 1S protection, CellGuard not used; D4 6 W panel standard; D5 two M12 5-pin ports plus a gland; D6 15 min default interval; D7 TwinKit first, The Things Network as fallback; D8 stock polycarbonate IP65 enclosure; D9 to D11 panel as hood, antenna down, 1.75 m mounting height (precis choices); D12 no change to budget, pitch or problem. As consequences, R11 is restated to one switched rail per port (a 5-pin connector cannot carry three rails, a bus and an analog input) and R16 is restated as the FieldNode core cost, the figure sibling repos cite.

### Still awaiting Amish (status updated 2026-09-25, FND-DDR-002)

1. **O1, first adopting projects and pilot region** (sets the band and antenna). No preference stated.
2. **O2, sensor port pinout**, with the adopting teams. FND-CAL-001 offers a candidate only.
3. **O3, firmware update method in the field.** No recommendation was made.
4. **New, sun shield (R3, R5, R2).** Options: (a) a ventilated white aluminium shield as standard (+$8, +0.15 kg; $134.00 and 2.56 kg, which breaks R14); (b) shield only for hot-climate sites, with R14 applying to the base node; (c) no shield and accept that R3 is not met and hot sites lose charge. Recommendation: (b). **Decided by Amish, 2026-09-25: go with recommendation.** Applied (see below).
5. **New, R14 mass.** If (a) is chosen, relax R14 to 2.75 kg or thin the back plate. Recommendation: keep 2.5 kg for the base node. **Decided by Amish, 2026-09-25: go with recommendation.** Applied.
6. **New, panel voltage class.** Options: 6 V class (current) or 9 V class of the same power, which keeps about 7.4 V when hot. Recommendation: 9 V class, subject to the charger chosen at TRL 4. **Decided by Amish, 2026-09-25: go with recommendation.** Applied.
7. **New, published sensor allowance.** Options: 115 mW (exactly 5 days, no margin) or 100 mW (5.75 days). Recommendation: 100 mW. Sibling notes cite 115 mW; all their quoted loads except CurbCount (about 300 mW) fit 100 mW. Not applied to any other repo. **Decided by Amish, 2026-09-25: go with recommendation.** Applied here; siblings listed as a cross-repo action.
8. **New, firmware airtime rule (R9).** Recommendation: lengthen the interval automatically at SF10 and slower (22 min at SF10, 87 min at SF12) when on The Things Network. **Decided by Amish, 2026-09-25: go with recommendation.** Applied as a requirement; firmware is TRL 4.

Suggestion only, not in the repo: a panel-powered cell heater for sites with long sub-zero spells.

### Cross-repo consistency

- TwinKit recommends an 8-channel LoRaWAN concentrator and FieldNode as its first example twin; consistent with D1 and D7. Its twin example refers to the cell as FieldNode BOM part 4; in this repo the cell is line 6 (the panel is 4). Noted here, TwinKit not edited.
- CellGuard's note that FieldNode needs its own one-cell protector agrees with D3.
- The FieldNode core cost stays $126.00, the figure AirStreet, BridgePulse, FloodGauge, LoadZone, SlopeWatch and WellSense use; NoiseMap ($119) and CurbCount (about $95) quote other figures. The allowance change (item 7) would affect sibling notes that cite 115 mW. No other repo was edited.

### Safety concerns

- Heat: without a shield the enclosure reaches 66 to 73 °C when dusty in 45 °C sun, near or above the electronics rating and well above LiFePO4 comfort. The 45 °C charge lockout must never be defeated to recover energy.
- Cold: the cell must not charge below 0 °C; a node on a long overcast freeze will stop rather than charge unsafely.
- Mounting: clamp preload (assumed 1,000 N) carries every wind margin; installers need a torque figure. The node adds about 80 N of wind load about 2 m up a site pole that this design does not check. Work at height and overhead lines as at TRL 2.
- About 19 Wh LiFePO4 cell left unattended: fuse, protection IC and NTC as specified.

### Gaps and notes

- No citations were flagged as unchecked in the TRL 2 note, so no WebFetch checks were run. The panel voltage coefficient, charger minimum input, cell cold capacity and clamp preload are typical values, not checked against a chosen part.
- Assumptions only tests can settle: the shield factor (0.25, borrowed from WWT-CAL-001), band preload, gateway sensitivity and real path loss.
- The kit's cutaway still cuts at the mean Y of the parts; with the scene shifted down by the enclosure's center height (as at TRL 2) the section shows the cell, boards and controller. The ports and glands fall in the removed half and show only in the exploded view, where callouts 3 and 10 partly cover their small parts.
- Existing material beyond TRL 3: `build-log/README.md` (scaffold) is present, untouched and not extended. No test, build or firmware material exists.

### Recommended next step

TRL 4 is on hold by Amish's instruction; this repo stops at TRL 3. Amish's review is needed on items 4 to 8 above and on O1 to O3. For the record only, TRL 4 would need: a bench build of the power board and core; a lab test report (TST, `environment: lab`) covering enclosure temperature in sun with and without the shield, charge lockout at 0 and 45 °C, sleep current and energy per report, and clamp preload and slip; and build log entries. None of this has been started.

## Session 2026-09-25: recommendations accepted

On 2026-09-25 Amish wrote: "i accept all your recommendations, go with them across all repos." Every item in this note and in FND-DDR-001 that carried a recommendation is now decided by Amish, 2026-09-25: go with recommendation. The decisions and their effects are recorded in `docs/decisions/0002-recommendations-accepted.md` (FND-DDR-002 v0.1).

### Decisions applied and what changed

| Decision | Before | After |
| --- | --- | --- |
| D1 to D12 (FND-DDR-001) | Adopted for TRL 3, open for review | Decided; no design change; `budget_usd` stays $150, pitch and problem unchanged |
| Sun shield, option (b): hot-climate sites only | Not in the design; R3 not met (58.7 to 73.3 °C inside at 45 °C) | BOM line 14 option at qty 0, $8.00, 0.15 kg; modeled (`build_shield()`, `cad/step/fieldnode-shield.step`); fitted where the design maximum exceeds 30 °C (FND-CAL-001 [C2c]); 48.5 to 52.2 °C inside at 45 °C with it; R3 restated, met on paper |
| R14 for the base node | 2.41 kg, at risk; 2.56 kg with a shield | R14 restated to the base node: 2.41 kg, met on paper (0.09 kg margin); hot-climate node 2.55 kg (shield mass now from the model) |
| 9 V class panel | 6 V class, Vmp 4.95 V when hot (0.05 V short of a 5 V charger minimum) | 9 V class, Vmp 7.42 V when hot (2.42 V headroom); same price; R5 met on paper |
| Published sensor allowance 100 mW | 115 mW cited by siblings; exactly 5.00 days | 100 mW published; 5.75 days, 15 % margin; R6 stays at risk for a cold (4.03 days) or aged (4.60 days) cell |
| Firmware airtime rule | R9 at risk: 43.5 s a day at SF10, 173.8 s at SF12 | Rule: 22 min at SF10, 48 min at SF11, 87 min at SF12 on The Things Network; 30.0 s a day or less; R9 restated, met on paper |

Files changed: `bom/bom.csv` (line 4 respecified, line 14 added) and `bom/bom-notes.md`; `cad/src/model.py` (shield parameters, `build_shield()`, `shield_geometry()`, new export) and re-exported STEP and STL; `cad/src/sheets.py` and FND-DWG-001 at Rev P2 (panel class and shield option notes, revision row); `cad/src/concept_media.py` key figures and all of `media/` re-rendered (hero, blueprint and exploded checked; `_views` folders deleted); `docs/04-calcs/sizing.py` and `results.csv`; FND-CAL-001 v0.2, FND-REQ-001 v0.4, FND-PRC-001 v0.4, FND-PRB-001 v0.4, FND-DDR-001 v0.2; `README.md` (key figures, components, and a rewritten "What sparked the idea" citing the 2003 Great Duck Island deployment); `project.yaml` evidence list. All PDFs rebuilt.

### Requirement status (FND-CAL-001 v0.2, Table 4)

None not met, 2 at risk, 1 not verifiable at TRL 3, 10 met on paper, 5 met by design.

| ID | Status | Key number |
| --- | --- | --- |
| R2 Operating temperature | At risk (cold) | No charging on clear days below about -13 °C; warm end covered (52.2 °C dusty worst case with the shield) |
| R6 Autonomy | At risk | 5.75 days at 100 mW; 4.03 days at -20 °C; 4.60 days at end of life |
| R12 Install | Not verifiable at TRL 3 | 15 min estimate, at the limit |
| R3, R5, R7, R8, R9, R10, R11, R13, R14, R16 | Met on paper | R3 and R5 rest on the assumed shield factor of 0.25 |
| R1, R4, R15, R17, R18 | Met by design | |

### Still awaiting Amish

1. **O1, first adopting projects and pilot region** (band and antenna). No recommendation.
2. **O2, sensor port pinout**, with the adopting teams. Candidate only, no recommendation.
3. **O3, firmware update method in the field.** No recommendation.

The cell heater for long sub-zero spells remains a suggestion only, not in the repo.

### Cross-repo actions (other repos not edited)

- **Sibling notes that cite a 115 mW allowance** (the adopting projects listed in FND-PRC-001): update to the published 100 mW allowance.
- **CurbCount** (about 300 mW) exceeds the allowance; it needs its own storage and panel sizing or the 10 W panel variant.
- **Hot-climate sibling pilots** (for example HeatMap Node or any site with a design maximum above 30 °C): add the $8.00, 0.15 kg shield to their FieldNode cost and mass ($134.00, 2.55 kg).
- **Sibling notes describing the panel** as 6 V class: now 9 V class.
- **TwinKit**: its twin example calls the cell FieldNode BOM part 4; the cell is line 6 (the panel is line 4).
- **NoiseMap ($119) and CurbCount (about $95)**: align their quoted FieldNode core cost with $126.00.
- **Kit**: the cutaway cutter and scale figure placement for pole-mounted repos (noted at TRL 2).

### TRL 4

TRL 4 remains on hold by Amish's instruction. `trl` and `trl_target` stay at 3. The charger part choice, firmware (including the airtime rule), a sun test of the shield factor, the power board and any purchasing have not been started.

## Session 2026-09-26: product appearance model and photoreal renders

Amish chose this repo for the first batch of product renders on 2026-09-26. This session added an appearance model for photoreal product renders; the massing model, BOM, calculations and drawing are unchanged.

### What was done

- `cad/src/product_model.py`: `product_parts()` (54 parts: 33 shell, 15 internal, 6 context), `TITLE` and `RENDER_VIEWS` (hero, exploded and a detail view without the pole). It imports `PARAMS`, `derived()`, `build_parts()` and `on_panel()` from `cad/src/model.py` and keeps every main dimension and interface: enclosure envelope and parting line, port, gland and antenna positions, internal plate and the envelopes on it, panel size, tilt and position, bracket members, back plate, V-blocks and clamp heights.
- Appearance detail added:
  - Enclosure base with filleted corners, side ribs, lid screw bosses and holes for the penetrations; lid with a parting line, the dark EPDM gasket showing, four captive stainless screws, a label with an accent band, port markings A and B and a lit green status light pipe.
  - M12 sockets with pin inserts (port A open, port B with a knurled, tethered sealing cap); M16 glands with domed nuts; the ePTFE vent; the whip antenna on a hex bulkhead.
  - Panel with an aluminium frame, cell grid, junction box and badge; bracket angle clips and M6 bolts; back plate with keyhole and band slots; true 90 deg V-blocks; band clamps with worm housings.
  - Inside: ASA plate with a lift-out slot, the LiFePO4 cell in its strapped, fused holder, power board and controller carrier with components, LoRa module shield can, antenna pigtail and a desiccant pack.
  - Context: a short section of the 48.3 mm pole with a cap, the panel lead from gland 1 to the junction box, and a sensor cable plugged into port A and tied to the pole.
- `README.md`: hero image now points to `media/render-hero.png`, with a link to `media/render-exploded.png`. The render files are produced separately.

### Differences from model.py, proposed, awaiting Amish

1. **Clear window in the lid** (96 x 58 mm, over the upper lid). BOM line 2 describes a plain gasketed lid. The window shows the cell and wiring in the renders and lets a field visit read the status without opening the box. Options: (a) plain grey lid, as the BOM; (b) grey lid with a clear UV-stabilized polycarbonate window, which several enclosure makers offer as a standard variant. **Recommendation: (b)** for the renders only until the enclosure is chosen at TRL 4; check the cost and UV rating then. Proposed, awaiting Amish.
2. **ePTFE vent position.** In `model.py` the vent sits at (58, -63) mm, which overlaps the antenna bulkhead at (58, -76) mm (13 mm apart for two 18 mm parts). The appearance model moves the vent to (30, -63) mm, about 5 mm clear of the nearer gland flange and 13 mm clear of the bulkhead. **Recommendation:** adopt the new position in `PARAMS` (a `vent_xy` entry) and on FND-DWG-001 at the next revision. Proposed, awaiting Amish.
3. **Status light pipe on the lid.** The BOM puts the status LED on the controller carrier (line 8); the appearance model adds a small light pipe through the lid so the LED shows from outside. **Recommendation:** keep it if option 1(a) is chosen; with the window it is optional. Proposed, awaiting Amish.
4. **V-blocks drawn with a true 90 deg V** instead of the cylindrical seat used for massing in `model.py`; the depth and clamp heights are unchanged. No decision needed; noted for the drawing.

### Scope

This is an appearance model only: no tolerances, no PCB layouts and no fabrication detail. `trl` and `trl_target` stay at 3, and TRL 4 remains on hold.

## Session 2026-09-27: kit 1.5.0 and image quality

- Kit 1.5.0 synced: STANDARDS v1.5 (sections 12 to 15: product renders, storefront images and image quality, public release, authorship and signing), `.kit/cards.py`, `.kit/image_qc.py`, `.kit/release_gate.py`, issue templates, and the `/render-product` and `/release` commands. `CLAUDE.md` now matches `.kit/CLAUDE.md`.
- Every `media/render-*.png` recaptioned from its original render with the new layout: the title, concept label and repository sit in a band above the render and the view note in a band below it, each line wrapped to the image width, so no text overlaps other text or the render or runs off the image. `media/card.png` and `media/social-preview.png` regenerated with the same rules.
- `python .kit/image_qc.py` and `python .kit/release_gate.py` pass. trl stays 3.

## Session 2026-09-30: design for construction and illustrated build plan (BLD-001)

Run under `/build-plan` steps 1 to 4 with Amish's instruction of 2026-09-30 to replace the text-only plan: "Design concept and constructability are different states", speak plainly, draw every component and how it fits, and "fix the design assumptions to match and be physically feasible". This section replaces the earlier 2026-09-30 build plan section. Commit and push were skipped by instruction. TRL cap respected: no PCB layout, firmware, purchasing list, test plan or build log; the power board is bought modules wired at block level.

### What was done

- `cad/src/model.py`: rebuilt as components with every fixing, plus 97 build123d constructability checks (`python cad/src/model.py --check`: overlap volume and gap for every pair that must touch or must clear). All 97 pass. STEP and STL regenerated in `cad/step/` and `cad/stl/` (the shield file now includes its thumb screws).
- `docs/decisions/0003-design-for-construction.md` (FND-DDR-003): every change and its reason, "made under Amish's 2026-09-30 instruction to make the design physically buildable; open for his review".
- `docs/05-build-plan.md` (FND-BLD-001 v0.2): rewritten from `.kit/templates/build-plan.md` in plain English, components in build order, each with a making sketch, numbered making steps, a joint close-up and a check; twelve assembly steps each with a picture; first checks; safety stops; tools; open questions. The old text-only v0.1 is withdrawn (its research on modules, wiring and safety holds is reused).
- `cad/src/build_plan_media.py` (new) with `.kit/build_views.py`: overview, nine making sketches FND-DWG-101 to 109, two drilling layouts, eight joint close-ups, twelve step pictures and the block wiring diagram. Every picture was looked at and reworked where it was cluttered or unclear.
- `docs/04-calcs/sizing.py` re-run: mass from the new components, V-block geometry [D6b], cell swap with the shield [E2b]. FND-CAL-001 v0.3, FND-PRC-001 v0.5 and FND-REQ-001 v0.5 carry the new mass, cost, bracket and service figures. `bom/bom.csv`: lines 1, 5, 12, 13 and 14 respecified, line 15 added.
- Drawing FND-DWG-001 Rev P3 (`cad/src/sheets.py`): new penetration leaders and notes; its annotation offsets fixed (they no longer matched the kit 1.7 view layout, so dimensions sat about 11 mm off the views).
- Concept media regenerated (`cad/src/concept_media.py`): hero, blueprint, cutaway, exploded (now with callout 15), flow, model.glb and viewer.
- `project.yaml`: `design_state: constructable`; FND-DDR-003, the overview picture and `build_plan_media.py` added to `trl_evidence`. README: new "Building the prototype" section with the overview picture.
- Kit fixes, reported for the kit source: `.kit/build_views.py` (picture band kept clear of the title and subtitle; leader lines end on the part itself; joints drop parts a window leaves empty; `component_sheet` takes a laid-flat shape for the views and an inset camera); `.kit/drawing.py` (front and right view sublabels no longer overlap when the right view is narrow).

### Design changes made for construction (FND-DDR-003)

1. **V-blocks (P1):** 60 x 33 x 20 mm with a true 90° V, 50.3 mm wide, point 7.8 mm from the plate; the 48.3 mm pole touches both faces 24.9 mm from the plate; poles 40 to 71 mm seat. Two M4 countersunk screws each. The pole stays where the concept put it.
2. **Penetrations (P2, P3):** two rows 27 and 55 mm from the back face. Back row: glands at 40 and 8 mm left, vent 24 mm right. Front row: ports at 54 and 22 mm left, antenna 30 mm right. Flanges at least 8.0 mm apart (was 2 mm); vent and antenna 10.6 mm apart (were overlapping).
3. **Bracket (P4):** per side, a 30 x 30 x 3 angle plate clip (two M5 to the plate), a 20 x 3 flat-bar post on two M6 bolts (rigid), a 20 x 3 strut on one M6 bolt each end, and two 30 x 30 x 3 angle panel clips bolted through the panel frame's back lip (two M4 each). Every joint is face to face. The concept's pinned post and strut formed a linkage that could swing; the two-bolt post foot makes a rigid triangle.
4. **Shield (P5):** 12 mm flanges folded in at the back of each side, four M4 knurled thumb screws into tapped holes in the plate; slides off forward. Cell swap on a hot-climate node about 9 min (was 7 min); R15 (10 min) still met.
5. **Fuses and connectors (P6):** BOM line 15, a plug-in terminal strip on the internal plate (modelled) and a 0.5 A resettable fuse on each sensor supply.
6. **Enclosure fixing (P7):** four bought external lugs, one M5 button-head screw each through the plate.
7. **Internal plate fixing (P8):** on the enclosure's four moulded bosses, 6 mm off the back wall, four M4 screws.
8. **Band path (P9):** each band round the pole, through two slots in the plate 51 mm each side of centre and across the plate front (below the box and above it).
9. **Mass:** a 100 x 150 mm window in the back plate behind the box and 20 mm bar (was 25 mm) offset the added parts.
10. **Found while drawing:** the upper plate clip hole sat 5 mm below the plate edge; moved so it is 15 mm clear.

### Key results

- Constructability checks: 97 of 97 pass.
- Mass: base node **2.45 kg** (was 2.41 kg), **0.05 kg** under R14; hot-climate node 2.61 kg. R14 is met on paper, but the margin is thin.
- Cost: base node $139.00, hot-climate node $148.00, both within the unchanged $150 value-engineering target (`budget_usd`).
- Thermal, energy, radio and wind results unchanged (enclosure, panel and shield keep their size and place); clamp pull 59 N (63 N with the shield) against 2,000 N; bracket buckling factor 30.
- Requirement status unchanged: none not met; R2 and R6 at risk; R12 install time not verifiable at TRL 3.

### Proposed, awaiting Amish

1. **A1, shield fixing:** thumb screws (tool free) lower tamper resistance at a node mounted at 1.75 m partly against tampering. Options: (a) thumb screws; (b) M4 pan-head screws. Recommendation: (a) for the prototype. **Decided by Amish, 2026-09-30: go with recommendation.**
2. **A2, wall mounting:** the plate's back now carries screw heads and the V-blocks. Options: (a) remove the V-blocks and use 5 mm spacers on the wall screws; (b) a separate wall plate. Recommendation: (a). **Decided by Amish, 2026-09-30: go with recommendation.**
3. **A3, mass margin 0.05 kg:** (a) accept and weigh at TRL 4; (b) remove more mass now. Recommendation: (a). **Decided by Amish, 2026-09-30: go with recommendation.**
4. **A4, shield on the first prototype** (carried over): (a) yes, $148.00 within the value-engineering target; (b) base node first. Recommendation: (a). **Decided by Amish, 2026-09-30: go with recommendation.**
5. Still open: O1 pilot region and band, O2 port pin assignment, O3 firmware update method; the enclosure part (boss spacing, lug kit); a panel with a back lip at least 12 mm wide; the band torque that gives 1,000 N preload.

### Still to regenerate

- `docs/pdf/` PDFs of FND-CAL-001, FND-PRC-001 and FND-REQ-001 are the older versions until `python .kit/render.py` is run.
- Cross-repo: sibling READMEs that cost the FieldNode core at about $126 should read $139.

### Safety concerns

- First charge of the LiFePO4 cell: the plan holds charging until the 3.6 V charge voltage and both temperature stops are shown with substitute resistors, then requires an attended first charge on a non-combustible surface.
- The charger's temperature window must be 0 to 45 °C and the protection board must use LiFePO4 limits; both are checked on the datasheet before buying.
- The new rail fuses limit a shorted sensor cable; the 5 A cell fuse stays.
- Sharp edges on cut bar, angle and 0.5 mm sheet; ASA print fumes; work at height stays outside the plan.

### Recommended next step

Amish reviews FND-DDR-003 and the illustrated plan, decides A1 to A4, and says whether this plan format should be used across the portfolio. The photoreal renders and `product_model.py` can then be brought up to the constructable design on his Mac. Building to the plan is TRL 4 work and stays on hold.

### Decisions, 2026-09-30

Amish, 2026-09-30: "i accept your recommended changes on design that are currently being sent across for my approval". FND-DDR-003 (design for construction) is accepted as v0.2, and A1 to A4 are decided as recommended: thumb screws on the shield for the prototype, 5 mm spacers for wall mounting with the V-blocks removed, accept the 0.05 kg mass margin and weigh at TRL 4, and fit the shield on the first prototype.

## 2026-10-02: open decisions decided

Amish, 2026-10-02: "i approve your recommendations for all 555 open decisions." The recommendations written for this repo's open decisions are recorded as decided.

### Decisions recorded

3 decisions, moved from "Open decisions" to "Decisions made" in the register (FND-DEC-001 v0.3):

1. Pilot region and radio band (FND-DDR-001, O1): US915 (North America) is the default first variant with a 915 MHz whip; the band switches to that of the first adopting project's site if it is outside North America (EU868, AS923 or IN865).
2. Sensor port pin assignment (FND-DDR-001, O2): pin 1 switched rail, pin 2 data A, pin 3 ground, pin 4 data B, pin 5 analog, as the proposed standard, sent to HeatMap Node and the next adopting project for sign-off.
3. Firmware update method in the field (FND-DDR-001, O3): by cable inside the box with the lid open, through a USB or serial header on the board, with no extra hole in the enclosure; over-the-air updates are left for a later private-gateway variant.

### Documents changed

- `docs/06-design-decisions.md`: FND-DEC-001 v0.3
- `docs/decisions/0001-trl2-review-decisions.md`: FND-DDR-001 v0.3 (O1 to O3 marked decided)
- `docs/decisions/0002-recommendations-accepted.md`: FND-DDR-002 v0.2 (O1 to O3 marked decided)
- `docs/01-problem.md`: FND-PRB-001 v0.5 (co-design partner and open questions)
- `docs/02-concept.md`: FND-PRC-001 v0.7 (pinout, band and firmware update)
- `docs/03-requirements.md`: FND-REQ-001 v0.7 (R11 status)
- `docs/04-calcs/01-sizing.md`: FND-CAL-001 v0.5 (R11 status in the requirement table; no figure changed)
- `docs/05-build-plan.md`: FND-BLD-001 v0.4 (port wiring and antenna text)
- `README.md` and `bom/bom-notes.md` (not controlled): pinout, antenna band and update method

### Follow-up actions to carry approved decisions into the design

1. Decision 1: BOM line 9, respecify the antenna as a 915 MHz whip for the US915 first variant (description only; price unchanged) (BOM).
2. Decision 1: set the LoRaWAN region to US915 in the firmware configuration when the firmware is written at TRL 4 (docs).
3. Decision 2: label the pin numbers and signals of ports A and B on the wiring picture of the build plan and on FND-DWG-001 (build plan pictures, drawings).
4. Decision 2: send the proposed pinout to HeatMap Node and the next adopting project and record their sign-off; this also closes HeatMap Node's open item 6 (docs).
5. Decision 3: add a USB or serial programming header to the power board and controller layout in the model, reachable with the lid open, and to the BOM notes of line 7 (model, BOM).

### Points found in the review

- Pole range is stated two ways: FND-DDR-003 P1 says poles of 40 to 71 mm seat on both V faces, while the concept, requirement R12 and the build plan say 40 to 60 mm. The band clamp length probably sets the 60 mm limit; worth one line saying so.
- HeatMap Node's open item 6 depends on item 2 here; deciding it closes both.

## 2026-10-02: approved follow-ups carried out

Amish, 2026-10-02: "497 follow-up actions that need CAD, drawing, picture, BOM or calculation work ... APPROVED CHANGES, COMPLETE THESE", and "Photoreal renders are out of date in most repos ... COMPLETE THESE". The five follow-ups listed above under "Follow-up actions to carry approved decisions into the design" are carried out here.

### Approved follow-ups carried out

1. **Done. BOM line 9, antenna respecified as a 915 MHz whip** for the US915 first variant, price unchanged (`bom/bom.csv`, `bom/bom-notes.md`). The GA leader now reads "915 MHz whip (9)".
2. **Done as far as TRL 3 allows. US915 region in the firmware.** There is no firmware yet (TRL 4 work), so the setting is recorded where the firmware will be written from: the precis (FND-PRC-001 v0.8), first checks of the build plan ("Firmware load by cable": load with the region set to US915; the node joins a US915 network) and safety stop S6. The calculation note now checks US915 (FND-CAL-001 v0.6, B6): the 20-byte uplink cannot use SF10 (11-byte limit and the 400 ms dwell time), so the node uses SF7 to SF9 only and the 15 min interval fits fair use at every usable rate; the SF9 margin at 2 km is 18.2 dB at 915 MHz (18.6 dB at 868 MHz).
3. **Done. Port A and B pin numbers and signals labelled** on the build plan wiring picture (`docs/05-build-plan/wiring.png`, a pinout box: 1 switched rail, 2 data A, 3 ground, 4 data B, 5 analog) and on FND-DWG-001 Rev P4 (notes and port leader). Pin positions on the socket face are left to the socket maker's datasheet (IEC 61076-2-101, A-coded) rather than drawn from memory.
4. **Part done; the rest is cross-repo.** The proposed pinout is now in the README, precis, BOM notes, wiring picture and GA, ready to send. Sending it to HeatMap Node and the next adopting project and recording their sign-off happen outside this repo (see Cross-repo actions); R11 stays "Met on paper, awaiting sign-off".
5. **Done. Serial programming header.** `cad/src/model.py` adds a 1 x 6, 2.54 mm serial header (ground, 3.3 V, TX, RX, boot, reset) on the front face of the power board, wired to the controller, pins toward the lid, 92 mm above the box floor and 50 mm right of centre; its pin tips are 47.5 mm in from the box's open front. A serial header rather than USB because the STM32WL-class module has no USB port. Four new constructability checks: header on the power board (touch), clear of the closed lid (49.9 mm, at least 10 required), clear of the controller and cell (34.3 mm, at least 3), and a 22 x 40 x 14 mm plug and cable space in front of the pins clear of every part with the lid open (9.0 mm, at least 1). Checks: **101 of 101 pass** (97 before). STEP and STL regenerated. BOM line 7 now names the header; price USD 22.00 to USD 22.50 (USD 0.50 header, distributor price class at quantity 1).

### Documents changed and new versions

- `cad/src/model.py` (header, four checks), `cad/step/*.step`, `cad/stl/*.stl`
- `bom/bom.csv` (lines 7, 9, 10 and the line 14 note), `bom/bom-notes.md` (stale USD 126 and USD 134 figures corrected)
- `docs/04-calcs/sizing.py` and `results.csv`; `docs/04-calcs/01-sizing.md`: FND-CAL-001 v0.6
- `docs/03-requirements.md`: FND-REQ-001 v0.8; `docs/02-concept.md`: FND-PRC-001 v0.8; `docs/06-design-decisions.md`: FND-DEC-001 v0.4 (Value engineering); `docs/05-build-plan.md`: FND-BLD-001 v0.5; `README.md`
- `cad/drawings/FND-DWG-001` Rev P4 (pinout, header, 915 MHz whip); FND-DWG-106 P2 (lip note no longer points to an open question) and FND-DWG-107 P2 (header on the layout); FND-DWG-101 to 105, 108 and 109 regenerated, unchanged at P1
- Build plan pictures regenerated: `overview.png`, `step-01.png` to `step-12.png` (step 4 shows the header), `wiring.png`; joints and drilling layouts unchanged (the header is in none of them)
- Concept media regenerated: `media/hero.png`, `concept-blueprint.*` (key figures USD 139.50, US915), `exploded.png`, `cutaway.png`, `flow.png`, `model.glb`
- `cad/src/product_model.py`: brought up to the constructable design (see below)
- `docs/pdf/` regenerated by `.kit/render.py`

### Key results

- Cost: Value-engineering target: USD 150. Estimated cost of the constructable design: USD 139.50 (USD 10.50 under the target) for the base node; USD 148.50 with the sun shield (USD 1.50 under the target). `budget_usd` unchanged.
- Mass: base node 2.45 kg (header about 2 g), 0.05 kg under R14; hot-climate node 2.61 kg.
- Requirement status: **no status changed.** R8 and R9 values now quote US915 (18.2 dB margin; SF7 to SF9 only, 23.7 s a day at most); R11 value now lists the pins; R16 value USD 139.50 and USD 148.50. Counts unchanged: 10 met on paper, 5 met by design, 2 at risk (R2, R6), 1 not verifiable at TRL 3 (R12), none not met.

### Appearance model and render scenes

`cad/src/product_model.py` no longer reads the removed PARAMS keys and runs again. The mount, bracket (plate clips, posts, struts, panel clips and bolts), enclosure lugs, V-blocks, band clamps, internal plate, connector strip and programming header are now the `model.py` solids; ports, glands, vent and antenna sit in the two-row layout; the whip is labelled 915 MHz; the panel lead runs outboard of the bracket. RENDER_VIEWS kept (hero, exploded, detail). Scenes exported to `/home/claude/renders/fieldnode/` (one .npz and .json per view and `fieldnode__jobs.json`). Photoreal renders, `card.png` and `social-preview.png` are not regenerated here; they are made on Amish's Mac next, so `media/render-*.png` still show the concept until then.

Appearance deviations from `model.py`, **proposed, awaiting Amish** (carried over): a clear window in the lid over the controller with a lit status light pipe, a lid label and A and B port markings, rounded box corners and side ribs, and a short black riser under the programming header so it reads as sitting on the board (the model's power board envelope is a box, the appearance board is a thin PCB). Recommendation: keep them for the renders only.

### Cross-repo actions (not edited here)

- **HeatMap Node** and the next adopting project: send the proposed FieldNode pinout (pin 1 switched rail, 2 data A, 3 ground, 4 data B, 5 analog; M12 5-pin A-coded) and record their sign-off; this closes HeatMap Node's open item 6. Record the sign-off back in FND-DEC-001 and R11.
- **Sibling repos that cost the FieldNode core** (about USD 126 or USD 139): update to USD 139.50 (USD 148.50 with the shield).
- **Sibling repos that assume EU868 or a sub-GHz whip of either band:** the default first variant is now US915 with a 915 MHz whip; their airtime figures should allow SF7 to SF9 only.

### Not done, with reason

- Writing firmware with the US915 region set: TRL 4 work, on hold under the TRL 3 cap.
- Pinout sign-off by the adopting projects: needs those projects; listed under Cross-repo actions.
- Photoreal renders, `card.png`, `social-preview.png`: made on Amish's Mac from the exported scenes, per the instruction.

## Session 2026-10-02: Photoreal renders redone on the constructable design

Amish, 2026-10-02: "Photoreal renders are out of date in most repos ... COMPLETE THESE". Rendered with Blender Cycles on Amish's Mac (batch F1) from the scenes exported from `cad/src/product_model.py`, captioned with `.kit/photo_caption.py`; `media/card.png` and `media/social-preview.png` regenerated with `.kit/cards.py`. Each raw render was looked at once. No commit or push; `trl` unchanged.

- Views: `media/render-hero.png`, `media/render-exploded.png`, `media/render-detail.png`.
- Re-render: detail, once. At 8 degrees the whole unit stood on the tip of its whip antenna with the studio horizon behind, and the ports were too small to read. Re-rendered at 12 degrees with `--focus` on the enclosure, lid, ports, glands, vent and antenna base, so the frame closes in on the enclosure. `RENDER_VIEWS` now has `el` 12 and a matching note; `.kit/export_views.py` does not carry `--focus`, so a re-render of this view needs it passed by hand.
- Exploded note: "pole kit behind" now reads "pole mounting kit (back plate, V-blocks and band clamps) behind", since no pole is in that view.
- Faint thin streaks remain on the lid label and back plate in the close detail view; they come from `.kit/photoreal.py` merging vertices closer than 0.05 mm on small features. Kit action (not edited here): lower that merge distance or skip it for parts with fine detail.
- Appearance deviations already logged (2026-10-02, Proposed, awaiting Amish): clear lid window with a lit status light pipe, lid label and A and B port markings, rounded box corners and side ribs, riser under the programming header. Unchanged.
- `python3 .kit/image_qc.py`: 5 images, 0 problems. `python3 .kit/render.py --check`: no FAIL, no storefront warning.
- The two render items of the "Stale, to regenerate on Amish's Mac" note (2026-09-30) are removed; its PDF and cross-repo items stay, under "Still to regenerate".

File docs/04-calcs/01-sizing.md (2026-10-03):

---
doc_id: FND-CAL-001
title: FieldNode sizing calculations
project: FieldNode
doc_type: Calculation
version: "0.6"
status: Draft
date: '2026-10-02'
author: Amish Chadha
license: CERN-OHL-S-2.0
revisions:
- version: "0.1"
  date: '2026-09-25'
  author: Amish Chadha
  change: First issue for TRL 3 (core consumption, energy budget and autonomy, airtime, link budget, store and forward, enclosure temperature and charging window, panel voltage, wind and mounting, installation and service, mass, cost)
- version: "0.2"
  date: '2026-09-25'
  author: Amish Chadha
  change: Recommendations accepted by Amish (DDR-002)
- version: "0.3"
  date: '2026-09-30'
  author: Amish Chadha
  change: Design for construction (FND-DDR-003) applied; bracket, V-block, mass, cost and cell swap with the shield updated; open for Amish's review
- version: "0.4"
  date: '2026-10-01'
  author: Amish Chadha
  change: Budget treated as a value-engineering target
- version: "0.5"
  date: '2026-10-02'
  author: Amish Chadha
  change: "Requirement table: R11 pinout status after the 2026-10-02 decision (FND-DEC-001); no figure changed"
- version: "0.6"
  date: '2026-10-02'
  author: Amish Chadha
  change: "Approved follow-ups carried out: US915 airtime, dwell time and link at 915 MHz (B6); programming header added to the mass and cost (line 7, USD 22.50); base node USD 139.50, USD 148.50 with the shield; no requirement status changed"
---

# FieldNode sizing calculations

With the decisions of FND-DDR-002 applied, FieldNode meets fifteen of its eighteen requirements on paper (ten by calculation, five by design), has two at risk, misses none and leaves one that only a timed installation can settle. Version 0.1 found one miss, heat: in full sun at 45 °C ambient the base enclosure reaches 58.7 °C clean and 66.2 °C dusty on a hot design day, and up to 73.3 °C with the sun in its worst position, against the 60 °C of R3, and the cell is then too hot to charge for most of the day. Amish decided on 2026-09-25 to fit a ventilated white sun shield at hot-climate sites only. This note shows that the shield is needed where the site's design maximum exceeds 30 °C; with it the inside peaks at 48.5 to 52.2 °C at 45 °C ambient and the node stores 10.8 to 13.1 Wh on a hot clear day. The shield is BOM line 14, an option at $9.00 and 0.16 kg; the hot-climate node costs $148.50 and weighs 2.61 kg, and R14 now applies to the base node (2.45 kg after the design for construction of FND-DDR-003). The panel is now 9 V class, which keeps 2.42 V of headroom above a typical charger's 5 V minimum input when hot, where the 6 V class panel had none. The published sensor allowance is 100 mW, which gives 5.75 days of autonomy, a 15 % margin; a cold or aged cell still falls short of 5 days (R6 at risk), and the cell will not charge on clear days colder than about -13 °C (R2 at risk). A firmware rule lengthens the reporting interval at SF10 and slower, so airtime stays within 30 s a day on The Things Network; in the US915 default first variant (FND-DEC-001) the node uses SF7 to SF9 only, where the 15 min interval already fits. Every number in this note is printed by `docs/04-calcs/sizing.py`; the tag in brackets, for example [A3], is the line of that script's output that carries it.

> **Safety:** These are first-principles estimates for a paper proof of concept. They do not show that the lithium iron phosphate cell, the charger or the pole mounting is safe. Cell temperature, charge lockout and clamp preload must be checked on hardware before any node is left unattended. See FND-PRC-001, Safety.

## Scope and method

The note checks every requirement in FND-REQ-001 v0.4 against the design in FND-PRC-001 v0.4 and the parametric model `cad/src/model.py`. The script imports the model's `PARAMS` and `derived()` and builds the model once for part volumes, so the enclosure, panel position, bracket, back plate and V-blocks used here are the ones in the STEP files and in drawing FND-DWG-001. It also reads `bom/bom.csv` and `budget_usd` in `project.yaml`. Run it from the repo root with `python docs/04-calcs/sizing.py`; it also writes `docs/04-calcs/results.csv`.

The design case is a node on a 48.3 mm pole with the enclosure base 1.75 m above ground, facing the equator, reporting a 20-byte LoRaWAN uplink every 15 min (DDR-001, D6) to a gateway 2 km away in suburban terrain.

## Assumptions

*Table 1. Main assumptions.*

| Area | Assumption | Basis |
| --- | --- | --- |
| Energy chain | 6 W panel; 2 peak sun hours on the tilted panel in the worst month; 20 % panel loss (heat, dust, angle); charger 85 %; cell charge 95 %; rail converters 90 % | As FND-PRC-001 v0.2; screening values |
| Cell | LiFePO4 3.2 V, 6 Ah; 80 % usable; 70 % of capacity at -20 °C; 80 % at end of life; charging allowed 0 to 45 °C | Typical cell data (see FND-PRC-001) |
| Core | SX1262 at +14 dBm 45 mA, receive 4.6 mA; two 0.1 s receive windows; controller awake 0.5 s at 8 mA per report; 33 µA whole-node sleep and quiescent current at 3.3 V | Semtech SX1261/2 datasheet figures; the rest assumed |
| Radio | 20-byte payload plus 13 bytes of LoRaWAN overhead; 125 kHz; coding rate 4/5; 8-symbol preamble; explicit header; CRC on | LoRaWAN defaults |
| Link | +14 dBm; 2 dBi antennas; 0.5 dB node and 2 dB gateway feeder loss; 6 dB receiver noise figure; Okumura-Hata suburban model at 915 MHz for the US915 default first variant (FND-DEC-001) and at 868 MHz for EU868; 10 dB fade margin | Screening values; gateway sensitivity assumed equal to the node's |
| US915 | Uplink data rates DR0 to DR3 (SF10 to SF7 at 125 kHz) with largest application payloads 11, 53, 125 and 242 bytes; 400 ms dwell-time limit per uplink; no duty cycle | LoRaWAN Regional Parameters (RP002), US902-928 |
| Storage | 32 bytes per stored reading; 16 MB SPI flash; 24 bytes per reading when several are batched into one uplink | Assumed record format |
| Heat | Combined convection and radiation 10 W/m²K (still air); absorptance 0.45 clean light grey, 0.70 dusty; clear-sky direct beam from the Meinel air-mass model, diffuse 10 % of direct, ground albedo 0.2; back face against the mounting plate; panel shading traced from the model geometry; the ventilated white shield (BOM line 14, 0.5 mm aluminium standing 15 mm off the box) passes a quarter of the solar gain | Handbook ranges; the shield factor matches WWT-CAL-001 and is not measured |
| Design days | Hot: latitude 28.6° N, late May, clear, 30 to 45 °C. Cold: latitude 50° N, late January, clear, -20 to -10 °C | Chosen to bracket R2 |
| Panel voltage | 9 V class panel (FND-DDR-002), Vmp 9.0 V at 25 °C; the 6 V class panel of v0.1 kept for comparison; -0.35 %/K; panel 30 K above ambient in full sun; charger minimum input about 5.0 V | Typical crystalline silicon and bq24650 or LT3652 class figures; to confirm per part at TRL 4 |
| Wind | 35 m/s gust; air 1.225 kg/m³; drag coefficient 1.2 on the panel (normal to it) and 1.3 on the enclosure | Screening values, not a code check |
| Mounting | Band clamp preload 1,000 N; each clamp presses the V-block with twice its preload; friction 0.2; 6063-T5 class flat bar, E = 69 GPa | Preload assumed, to be measured |
| Mass | Made parts from model volumes (polycarbonate 1.2, aluminium 2.7, ASA 1.07 g/cm³), shield included from its model volume plus 0.02 kg of fixings; bought parts from typical catalogue masses (panel 0.55 kg, cell 0.15 kg); the 9 V class panel assumed the same mass as the 6 V class | Estimates |

## A. Core consumption and energy budget (R5, R6, R7)

- **Core.** Each report costs 16.0 mA·s at SF9, so 96 reports use 0.43 mAh a day and sleep adds 0.79 mAh: the core needs 4.0 mWh a day [A1]. The TRL 2 figure stands.
- **Worst month.** The panel sees 12.0 Wh, delivers 9.60 Wh, the charger passes 8.16 Wh and the cell stores 7.75 Wh a day [A2].
- **Allowance and autonomy.** The cell holds 15.36 Wh usable. A sensor allowance of 115.0 mW is the largest that gives exactly 5.0 days without sun [A3]; at that load the node draws 3.07 Wh a day and the margin on R6 is zero. At -20 °C the same cell lasts 3.50 days and at end of life 4.00 days [A4].
- **At 100 mW,** the published allowance (FND-DDR-002) and the R7 target, the node draws 2.67 Wh a day, stores 2.9 times that in the worst month, and lasts 5.75 days, a 15 % margin on R6, or 4.03 days at -20 °C and 4.60 days at end of life. After five sunless days it refills in 2.6 worst-month days [A5].
- **Energy neutrality.** The worst month supports sensor loads up to 291 mW before the cell runs down day by day [A6]; autonomy, not harvest, limits the allowance.
- **Sibling loads.** AirStreet (45 mW), NoiseMap (21 mW), FloodGauge (7 mW), WellSense, HeatMap Node and SlopeWatch (about 1 mW or less) all fit within the published 100 mW. CurbCount's 300 mW does not [A7]; this is a cross-repo action in `docs/REVIEW.md`.

## B. Airtime, link and store and forward (R8, R9, R10)

*Table 2. Time on air for a 20-byte uplink (33 bytes on air) at 125 kHz [B1].*

| Spreading factor | Per uplink | Per day at 15 min | Shortest interval within 30 s/day | EU868 1 % off-time |
| --- | --- | --- | --- | --- |
| SF7 | 71.9 ms | 6.9 s | 4 min | 7 s |
| SF8 | 133.6 ms | 12.8 s | 7 min | 13 s |
| SF9 | 246.8 ms | 23.7 s | 12 min | 25 s |
| SF10 | 452.6 ms | 43.5 s | 22 min | 45 s |
| SF11 | 987.1 ms | 94.8 s | 48 min | 99 s |
| SF12 | 1,810.4 ms | 173.8 s | 87 min | 181 s |

- **R9 is met on paper by a firmware rule.** The 15 min default fits The Things Network's 30 s a day at SF7 to SF9, which covers the R8 design case, but not at SF10 or slower. Under the rule decided in FND-DDR-002, firmware on The Things Network lengthens the interval to the shortest value in Table 2 when adaptive data rate moves a node to SF10 or slower: 22 min at SF10, 48 min at SF11 and 87 min at SF12, which keeps airtime at 30.0 s a day or less [B1b]. On a private TwinKit gateway only the regional duty cycle applies, and the 15 min interval fits it at every spreading factor. The rule is a firmware requirement; the firmware itself is TRL 4 work.
- **Power limit.** At +14 dBm with a 2 dBi antenna the node radiates 15.5 dBm EIRP, 13.35 dBm ERP, inside the 14 dBm ERP limit of EU868; the whip's middle sits 1.64 m above ground [B2].
- **R8 is met on paper.** At SF9 the link budget is 145.0 dB. The Hata suburban path loss at 2 km to a 30 m gateway is 126.4 dB, a margin of 18.6 dB; with a 10 dB fade margin the range is 3.5 km. A 15 m gateway, below Hata's range of validity, gives about 2.5 km. At SF7 the margin is 13.6 dB and the range with fade margin 2.5 km [B3]. Clutter, foliage and gateway height dominate these figures; only a field survey settles them.
- **R10 is met on paper.** A day of readings takes 3,072 bytes; 30 days take 90 kB of the 16 MB flash, which would hold 5,461 days [B4].
- **US915, the default first variant.** Amish chose US915 (North America) for the first variant on 2026-10-02 (FND-DEC-001). There the slowest rate, SF10, carries at most 11 bytes and its 452.6 ms uplink exceeds the 400 ms dwell limit, so the 20-byte uplink can only use SF9, SF8 or SF7 [B6]. The 15 min interval therefore fits The Things Network's 30 s a day at every usable rate, 23.7 s a day at most, and the firmware rule of FND-DDR-002 is needed only on EU868 and similar bands. At 915 MHz the Hata loss at 2 km is 126.9 dB, so the SF9 margin is 18.2 dB and the range with a 10 dB fade margin 3.4 km; R8 is still met on paper. A backlog uplink at SF9 holds two readings rather than four [B6b]. Setting the region in the firmware is TRL 4 work.
- **Forwarding the backlog.** After a 30-day outage the node holds 2,880 readings. At SF9, batching four per uplink, resending them takes 428 s of airtime: 68 days at the 6.3 s a day left under fair use, but half a day under the EU868 duty cycle alone. At SF7 it takes 5 days under fair use [B5]. The store is ample; on The Things Network the backlog is slow to drain, so old readings should be sent when a private gateway is in range or thinned.

## C. Enclosure temperature and the charging window (R2, R3, R4, R5)

- **Loss coefficient.** The enclosure's exposed faces (all but the back, which sits on the mounting plate) total 0.0930 m² and lose 0.930 W/K. About 852 J/K of enclosure, cell, boards and plate gives a 15 min time constant, so the inside follows the sun within the hour [C1].
- **What the panel hood does.** The panel's front edge overhangs the lid by 56.6 mm and sits 120.7 mm above the enclosure top [C1b]. With the sun 60° high in front it shades 86 % of the top but none of the front face [C2b]. The hood protects the lid seam from rain; it does little for heat when the sun is low or to the side.
- **Worst sun position.** At 45 °C ambient, the worst clear-sky sun position is 35° high and 30° off the front normal: 16.9 W absorbed and 63.3 °C inside when clean, 26.3 W and 73.3 °C when dusty [C2]. This is an upper bound, since the sun is not always in that position at the day's peak ambient. With the shield the same position gives 49.6 °C clean and 52.2 °C dusty [C2c].
- **Where the shield is needed.** Without the shield the dusty box stays at 60 °C or less in the worst sun position up to 31.7 °C ambient, so the shield is fitted where the site's design maximum ambient exceeds 30 °C [C2c]. At that limit, on a clear 15 to 30 °C day, the base node peaks at 44.2 °C clean and 51.2 °C dusty and still stores 19.0 to 25.5 Wh against 2.67 Wh drawn [C3c].

*Table 3. Hot design day, 30 to 45 °C, latitude 28.6° N, clear [C3].*

| Case | Peak inside | Sun hours with charging allowed | Energy stored in the day |
| --- | --- | --- | --- |
| Clean, no shield | 58.7 °C | 2.1 of 13.3 h | 0.8 Wh |
| Dusty, no shield | 66.2 °C | 1.4 of 13.3 h | 0.3 Wh |
| Clean, with shield (hot-climate option) | 48.5 °C | 7.4 of 13.3 h | 13.1 Wh |
| Dusty, with shield (hot-climate option) | 50.4 °C | 6.5 of 13.3 h | 10.8 Wh |

- **R3 is met on paper with the shield at hot-climate sites.** Without the shield the clean enclosure scrapes under 60 °C on the 45 °C design day but not with dust or with the sun in its worst position, which is why R3 now requires the shield where the design maximum exceeds 30 °C (FND-REQ-001 v0.4). The result rests on the assumed shield factor of 0.25, which only a test can confirm.
- **Hot weather stops charging.** Because the 45 °C charge lockout (R4) acts on a cell that sits above 45 °C from mid-morning, a clean node stores 0.8 Wh on a hot clear day against 2.67 Wh drawn. A run of such days loses 1.84 Wh a day, so a full cell lasts 8.3 days (6.4 days dusty). With the shield the day ends 10.4 Wh in credit (8.1 Wh dusty) [C3b]. The lockout is correct and must stay; the fix, now decided, is to keep the cell cooler with the shield at hot sites.
- **Cold weather.** On a clear day at 50° N with -20 to -10 °C ambient, sun on the box lifts the inside to 3.3 °C, which allows 4.2 h of charging and 8.7 Wh stored [C4]. The peak rise is 13.3 K, so on clear days whose maximum is below about -13 °C the cell never reaches 0 °C and cannot charge [C5]. Overcast cold spells longer than the cold autonomy of about 4 days (section A) will stop the node.
- **Panel voltage.** In full sun on the hot day the panel runs at about 75 °C. The 9 V class panel decided in FND-DDR-002 then gives a Vmp of 7.42 V, 2.42 V above a typical 5.0 V charger minimum input; the 6 V class panel of v0.1 fell to 4.95 V, 0.05 V short [C6]. The part choice for the power board (TRL 4 work, on hold) must confirm the minimum input and the charger's maximum input.
- **R2 is at risk at the cold end.** With the shield at hot sites the warm end is covered (52.2 °C dusty worst case at 45 °C, and 58.3 °C for an unshielded node at 30 °C, both under the 70 °C electronics rating), but the cell charges only on clear days warmer than about -13 °C.

## D. Wind and mounting (R12, R13)

- **Loads.** A 35 m/s gust gives a dynamic pressure of 750 Pa: 52.2 N normal to the panel, 29.3 N on the enclosure front-on and 17.6 N side-on [D1].
- **Overturning.** With wind from behind, the panel lifts and pushes forward; together with the node's weight this gives 14.8 N·m about the lower clamp and pulls the upper clamp off the pole with 59 N. Wind from the front presses the node onto the pole [D2]. Against the 2,000 N that a 1,000 N band preload holds, the factor is 33.8 [D3]. With the shield fitted the enclosure presents 36.3 N front-on and the worst clamp pull rises to 63 N, a factor of 31.7 [D3b].
- **Slip.** Weight and wind push the node down the pole with 64 N against 800 N of friction (factor 12); side wind twists it with 1.58 N·m against 19.3 N·m (factor 12) [D4]. These factors depend on the assumed preload, which a torque check at installation must confirm.
- **Bracket.** Since FND-DDR-003 each side has a post, 161 mm between its lower foot bolt and its head bolt at 80°, and a strut, 129 mm between bolts at 38°, bolted flat to angle clips on the back plate and on the panel frame's back lip. Each member carries at most about 39 N, and a 20 x 3 mm flat bar of that length buckles out of plane at 1,180 N, a factor of 30 [D5]. The post is held by two bolts at its foot, so the side frame is a rigid triangle, not a linkage.
- **Pole range.** Each V-block is 60 x 33 x 20 mm with a true 90° V 50.3 mm wide at its face; the 48.3 mm design pole touches both V faces 24.9 mm from the plate [D6b]. On a 40 mm pole the V contacts sit 14.1 mm either side of the center and on a 60 mm pole 21.2 mm, both inside the V, which seats poles up to 71 mm. Each band needs about 229 to 280 mm of length around the pole, block and plate [D6], [D6b].
- **R13 is met on paper**, subject to the preload assumption. The pole, its footing and any wall anchors are site supplied and outside this note; the node adds about 81 N of wind load about 2 m up the pole, which the site owner should check.

## E. Installation and service (R12, R15)

- **Installation.** Fitting the bracket and panel on the ground, lifting the node, tightening two clamps, aiming the panel, plugging in the sensor and confirming an uplink take an estimated 15 min with a helper [E1], exactly the R12 limit. Only a timed installation can verify it.
- **Cell swap.** Opening the lid, swapping the cell in its fused holder, renewing the desiccant and confirming an uplink take an estimated 7 min with a screwdriver and no soldering [E2]. Where the sun shield is fitted it covers the lid; it lifts off after four thumb screws, which adds about 2 min, 9 min in all [E2b]. R15 is met by design for both.

## F. Mass and cost (R14, R16)

- **Mass.** The enclosure body, lid and lugs weigh 0.43 kg, the printed ASA internal plate 0.07 kg, the bracket 0.22 kg and the back plate with V-blocks 0.48 kg; bought parts add 1.24 kg, including about 2 g for the programming header: 2.45 kg in all for the base node [F1]. The TRL 2 figure of about 1.7 kg left out most of the back plate. The design for construction (FND-DDR-003) added clips, bolts, a connector strip and fuses, and took mass out with a window in the back plate behind the enclosure and a 20 mm bar. R14, stated for the base node, is met on paper with 0.05 kg of margin; the margin is thin and rests on catalogue masses. The shield, 181 x 106 x 206 mm of 0.5 mm aluminium with its fixing flanges, weighs 0.16 kg with its thumb screws, so a hot-climate node weighs 2.61 kg [F1b].
- **Cost.** The BOM has 15 lines, all priced; line 14, the shield, is an option at quantity 0 in the base node, and line 15, the plug-in connectors and rail fuses, was added by FND-DDR-003. Line 7 now includes the serial programming header (USD 0.50) chosen on 2026-10-02 for firmware updates by cable (FND-DEC-001). Value-engineering target: USD 150 (`budget_usd`, a hypothetical control target). Estimated cost of the constructable design: USD 139.50 for the base node (USD 10.50 under the target) [F2]. A hot-climate node with the shield costs USD 148.50 (USD 1.50 under the target) and weighs 2.61 kg [F3]. R16 is met on paper for both, within the value-engineering target.
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

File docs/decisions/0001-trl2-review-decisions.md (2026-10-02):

---
doc_id: FND-DDR-001
title: FieldNode TRL 2 review decisions
project: FieldNode
doc_type: Design decision record
version: "0.3"
status: Draft
date: '2026-10-02'
author: Amish Chadha
license: CERN-OHL-S-2.0
revisions:
- version: "0.1"
  date: '2026-09-25'
  author: Amish Chadha
  change: Record the TRL 2 review recommendations adopted for TRL 3 work under Amish's 2026-09-25 instruction, and the items that remain open
- version: "0.2"
  date: '2026-09-25'
  author: Amish Chadha
  change: Recommendations accepted by Amish (DDR-002)
- version: "0.3"
  date: '2026-10-02'
  author: Amish Chadha
  change: "O1 to O3 decided by Amish as recommended (FND-DEC-001)"
---

# 0001: TRL 2 review decisions

- **Date:** 2026-09-25
- **Status:** accepted for D1 to D12. Decided by Amish, 2026-09-25: go with recommendation (see FND-DDR-002). Items O1 to O3 had no recommendation at TRL 2; recommendations were written for them later, and Amish approved them on 2026-10-02: "i approve your recommendations for all 555 open decisions." (FND-DEC-001).

## Context

The TRL 2 review note (`docs/REVIEW.md`, session 2026-09-25, /populate) listed ten items as "Proposed, awaiting Amish", and the design precis FND-PRC-001 v0.2 listed eight key design choices, all marked proposed. On 2026-09-25 Amish asked for this batch of Design Molecule repos to be taken through the usual process with the instruction "you know the drill, nothing gets past TRL 3". He has not reviewed this repo's items one by one. Every item that carried a recommendation is therefore adopted as recommended for TRL 3 work, open for his review. Items without a recommendation stay open. Later on 2026-09-25 Amish wrote "i accept all your recommendations, go with them across all repos", so D1 to D12 are now decided (FND-DDR-002).

## Options considered

The options for each item are those listed in `docs/REVIEW.md` (session 2026-09-25, /populate) and in FND-PRC-001 v0.2, Key design choices.

## Decision

*Table 1. Items decided.*
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

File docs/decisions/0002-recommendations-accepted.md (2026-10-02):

---
doc_id: FND-DDR-002
title: FieldNode recommendations accepted
project: FieldNode
doc_type: Design decision record
version: "0.2"
status: Draft
date: '2026-10-02'
author: Amish Chadha
license: CERN-OHL-S-2.0
revisions:
- version: "0.1"
  date: '2026-09-25'
  author: Amish Chadha
  change: Record Amish's acceptance of all recommendations and what changed in the repo
- version: "0.2"
  date: '2026-10-02'
  author: Amish Chadha
  change: "O1 to O3 decided by Amish as recommended (FND-DEC-001)"
---

# 0002: Recommendations accepted

- **Date:** 2026-09-25
- **Status:** accepted. Every item below marked "Decided" is decided by Amish, 2026-09-25: go with recommendation. Items without a recommendation (O1 to O3) were decided by Amish on 2026-10-02, as later recommended: "i approve your recommendations for all 555 open decisions." (FND-DEC-001).

## Context

After the TRL 3 session, FieldNode had twelve items adopted for TRL 3 work pending Amish's review (FND-DDR-001, D1 to D12) and five new items in `docs/REVIEW.md` (session 2026-09-25, TRL 3, items 4 to 8), each with a recommendation. On 2026-09-25 Amish wrote: "i accept all your recommendations, go with them across all repos." Where a recommendation offered several options, the recommended option is the decision. Items that carried no recommendation are not decided by this record.
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

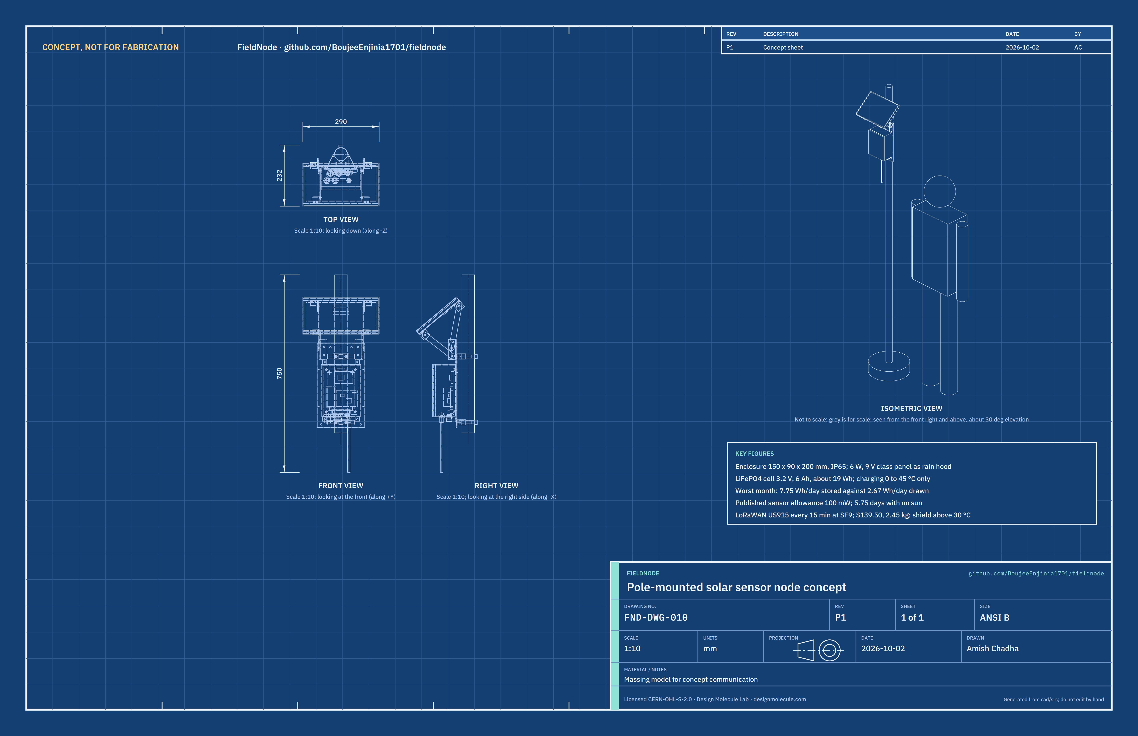
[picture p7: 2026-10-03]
media/concept-blueprint.png

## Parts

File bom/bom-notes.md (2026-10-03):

# BOM notes

- Costs are indicative USD prices at quantity 1 for a concept estimate, not quotes. Every line is priced. Value-engineering target: USD 150 (`budget_usd`, a hypothetical control target). Estimated cost of the constructable design: USD 139.50 for the base node (USD 10.50 under the target); USD 148.50 with the sun shield, line 14 (USD 1.50 under the target) (FND-CAL-001, section F).
- This is the cost of the FieldNode core (enclosure, power, radio, panel and mounting). Sibling projects that use FieldNode cite this figure when they cost their own parts separately. Sensors and the gateway are not included (see TwinKit).
- Line numbers 1 to 12 and 15 match the callouts in `media/exploded.png` and the part keys in `cad/src/model.py`. Line 13 has no callout. Line 14 is modeled by `build_shield()` in `cad/src/model.py` and exported as `cad/step/fieldnode-shield.step`; it is not shown in the media.
- TRL 3 changes: line 3 now has both glands fitted (one carries the panel lead), with the blanking plug moved to line 13; line 11 is printed ASA rather than aluminium, which saves about 0.11 kg.
- Design for construction (FND-DDR-003, 2026-09-30) repriced lines 1, 5, 13 and 14 and added line 15, the plug-in connectors and rail fuses.
- The power board (line 7) is priced as a prototype carrier; its design is TRL 4 work and has not been started. It now carries the serial programming header (1 x 6 pins at 2.54 mm: ground, 3.3 V, TX, RX, boot, reset), wired to the controller and facing the lid, so firmware is updated by cable inside the box with the lid open and no extra hole in the enclosure (FND-DEC-001, 2026-10-02). The header adds USD 0.50 (distributor price class at quantity 1), so line 7 is now USD 22.50. The STM32WL-class module has no USB port, so a serial header is the simpler choice; the 3.3 V USB-to-serial cable is a tool, not a part of the node.
- The antenna (line 9) is a 915 MHz whip for the US915 default first variant (Amish, 2026-10-02, FND-DEC-001), at the same price; it changes to the band of the first adopting project's site if that is outside North America.
- The sensor ports (line 10) are wired to the proposed standard pinout: pin 1 switched rail, pin 2 data A, pin 3 ground, pin 4 data B, pin 5 analog (FND-DEC-001).
- Changes from Amish's 2026-09-25 decisions (FND-DDR-002): line 4 is now a 9 V class panel of the same power, at the same indicative price; line 14, a ventilated white aluminium sun shield (USD 9.00, 0.16 kg with its thumb screws), is an option for sites whose design maximum exceeds 30 °C.

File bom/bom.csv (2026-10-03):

item | qty | spec | supplier | unit_cost_usd | make_buy | notes
1 Enclosure body with membrane vent and lugs | 1 | Light grey polycarbonate, 150 x 90 x 200 mm outside (W x D x H), IP65 or better, UV stabilized; four moulded bosses on the inside of the back wall for a mounting plate; the maker's kit of four external wall-mounting lugs; M12 ePTFE pressure-equalizing vent on the bottom face | Electrical enclosure maker (for example Fibox, Hammond or Bud class) via an electronics or electrical distributor; vent from an industrial vent maker | 20.00 | buy | Indicative price including vent and lug kit; size per cad/src/model.py; bottom face drilled for 6 penetrations in two rows (FND-DDR-003)
2 Enclosure lid with gasket | 1 | Gasketed lid with captive stainless screws | Supplied with item 1 | 0.00 | buy | Included in item 1
3 Cable glands | 2 | M16 x 1.5 nylon gland, IP68, 4 to 8 mm cable; one for the panel lead, one for a fixed-cable sensor (blanking plug in item 13 when unused) | Electrical distributor | 1.50 | buy | Indicative price; TRL 2 had one gland blanked but the panel lead needs its own (FND-CAL-001)
4 Solar panel | 1 | 6 W monocrystalline, 9 V class (Vmp about 9 V at 25 C), about 290 x 200 x 17 mm, with 1 m lead | Solar or electronics distributor | 14.00 | buy | Indicative price; 9 V class per FND-DDR-002 (keeps about 7.4 V when hot); charger minimum input to confirm at TRL 4
5 Panel tilt bracket | 1 | Two sides, each: one plate clip (aluminium angle 30 x 30 x 3 mm, 77 mm long), one post (flat bar 20 x 3 mm, 181 mm), one strut (flat bar 20 x 3 mm, 149 mm) and two panel clips (angle 30 x 30 x 3 mm, 30 mm long) on the panel frame's back lip; M6 bolts at the post foot (2), post head, strut foot and strut head; tilt set by hole position | Local make from metal stockist bar | 9.00 | make | Indicative material cost; 6063 class aluminium; redesigned for construction (FND-DDR-003)
6 LiFePO4 cell with fused holder | 1 | 32700 LiFePO4, 3.2 V, 6 Ah (about 19 Wh), charge 0 to 45 C; holder with inline 5 A fuse, 10 k NTC and plug-in lead | Battery distributor (cell from a maker that publishes a datasheet) | 9.00 | buy | Indicative price
7 Power board | 1 | 1S LiFePO4 MPPT-style charger (bq24650 or LT3652 class) set to 3.6 V with NTC lockout; protection IC; fuel gauge; switched 3.3 V, 5 V and 12 V rails; serial programming header (1 x 6 straight pins at 2.54 mm: ground, 3.3 V, TX, RX, boot, reset) on the front face, wired to the controller and facing the lid so a 3.3 V USB-to-serial cable plugs in with the lid open | Custom carrier; ICs and header from an electronics distributor (DigiKey or Mouser class) | 22.50 | make | Indicative prototype cost: USD 22.00 carrier as before plus USD 0.50 for the pin header (distributor price class at quantity 1); header added by FND-DEC-001 (2026-10-02, firmware update by cable); board design is TRL 4 work and not started
8 Controller and LoRa module | 1 | STM32WL-class LoRaWAN module (RAK3172 or Wio-E5) on a carrier with 16 MB SPI flash and status LED | RAKwireless or Seeed Studio via their stores or an electronics distributor | 14.00 | buy | Indicative price including carrier
9 Antenna | 1 | 915 MHz whip for the US915 first variant, about 2 dBi, about 190 mm, with bulkhead and pigtail | Electronics distributor | 10.00 | buy | Indicative price (unchanged); US915 default first variant (FND-DEC-001; DDR-001 O1); a whip for EU868 or another band replaces it only if the first adopting site is outside North America
10 Sensor ports | 2 | M12 5-pin A-coded panel-mount socket, IP67, with sealing cap | Industrial connector distributor | 6.00 | buy | Indicative price; wired to the proposed standard pinout (FND-DEC-001; DDR-001 O2)
11 Internal mounting plate | 1 | 3 mm printed ASA plate, 130 x 180 mm, lifts out with cell and boards | Local make (3D printed) | 4.00 | make | Indicative material and print cost; ASA chosen over aluminium for mass (FND-CAL-001 section F)
12 Pole mounting kit | 1 | Aluminium back plate 180 x 320 x 3 mm with a 100 x 150 mm window behind the enclosure, band slots and fixing holes; two aluminium V-blocks 60 x 33 x 20 mm with a 90 deg V, each on two M4 countersunk screws; two 12 mm stainless worm-drive band clamps for 40 to 60 mm poles (about 230 to 280 mm band); wall screws and plugs | Hardware shop plus local make | 8.00 | make | Indicative price; V-blocks cut from 60 x 40 mm aluminium flat bar (FND-DDR-003)
13 Hardware and consumables | 1 | Stainless fixings: 10 x M6 x 16 hex bolts with nyloc nuts (bracket), 8 x M5 x 12 button-head screws with nyloc nuts (lugs and plate clips), 8 x M4 x 12 pan-head screws with nuts (panel clips), 4 x M4 x 12 countersunk screws (V-blocks), 4 x M4 x 10 screws (internal plate); nylon standoffs, hook-up wire, ferrules, M16 blanking plug, desiccant pack, cable ties | Hardware shop | 9.00 | buy | Indicative price; no exploded-view callout
14 Sun shield (hot-climate option) | 0 | White powder-coated aluminium sheet 0.5 mm, one folded blank: front, two sides and top standing 15 mm off the enclosure, open bottom, 30 mm vent slot at the back of the top, 12 mm fixing flanges folded in at the back of each side; four M4 knurled thumb screws into tapped holes in the back plate, so it lifts off without tools | Local make from sheet stockist | 9.00 | make | Option, qty 0 in the base node; fit 1 where the site design maximum exceeds 30 C (FND-DDR-002, FND-CAL-001 section C); hot-climate node $148.50
15 Plug-in connectors and rail fuses | 1 | Pluggable terminal block strip (5.08 mm pitch, plug and header, about 12 ways) at the lower edge of the internal plate for the panel lead, both sensor ports and the fixed-cable gland, so the plate lifts out as one unit; two resettable fuses (PTC, about 0.5 A hold), one on each switched sensor rail | Electronics distributor | 5.00 | buy | Indicative price; added for construction (FND-DDR-003)

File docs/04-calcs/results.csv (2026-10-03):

id | value | target | status
R1 | IP65 enclosure, ePTFE vent; 2 glands, 2 capped M12 ports, antenna bulkhead, all IP67 class | IP65, sealed penetrations | Met by design (sealing of fitted glands not verifiable at TRL 3)
R2 | Electronics -20 to +70 C; worst sun position 52.2 C dusty with the shield at 45 C, 58.3 C dusty without it at 30 C; no charging on clear days below about -13 C | -20 to +45 C ambient; -20 to +70 C inside | At risk (cold charging)
R3 | With the shield at 45 C: hot-day peak 48.5 C clean, 50.4 C dusty, worst sun position 52.2 C; without it at 30 C: worst sun position 58.3 C dusty (at 45 C: 58.7 to 73.3 C) | 60 C or less; shield fitted where the design maximum exceeds 30 C | Met on paper (shield factor assumed)
R4 | NTC on the cell gates the charger at 0 and 45 C | Charging blocked below 0 C and above 45 C | Met by design
R5 | Worst month: stored 7.75 Wh/day against 2.67 Wh/day drawn (2.9 times); hot clear day with the shield 13.1 Wh clean, 10.8 Wh dusty stored; 9 V class Vmp headroom 2.42 V when hot | Harvest exceeds demand at 2 peak sun hours | Met on paper
R6 | 5.75 d at the published 100 mW (15 % margin); 4.03 d at -20 C; 4.60 d at end of life | 5 days or more at full allowance | At risk (cold or aged cell)
R7 | Published allowance 100 mW; 115.0 mW would give exactly 5 days | 100 mW or more | Met on paper
R8 | SF9 budget 145.0 dB; Hata suburban loss at 2 km (30 m gateway) 126.9 dB at 915 MHz (US915 default), margin 18.2 dB; 126.4 dB at 868 MHz, margin 18.6 dB | 2 km suburban at SF9 or faster | Met on paper
R9 | 23.7 s/day at SF9 at 15 min; US915 (default) uses SF7 to SF9 only, largest 23.7 s/day; EU868 firmware rule lengthens the interval to 22 min at SF10 and 87 min at SF12; largest 30.0 s/day | 30 s/day or less on The Things Network | Met on paper (firmware rule)
R10 | 30 days = 90 kB of 16 MB flash; backlog upload limited by fair use | 30 days or more kept on the node | Met on paper
R11 | Two M12 5-pin ports: pin 1 switched rail (3.3, 5 or 12 V), pin 2 data A, pin 3 ground, pin 4 data B, pin 5 analog | Two sealed ports, I2C, UART or RS-485, analog, switched rails | Met on paper (pinout decided as the proposed standard, awaiting sign-off by the adopting projects)
R12 | V-block seats 40 to 60 mm poles; install estimate 15 min | 40 to 60 mm poles and walls; 15 min or less | Not verifiable at TRL 3 (install time); fit met by design
R13 | Clamp pull 59 N (63 N with the shield) against 2000 N; slip factor 12; bracket factor 30 | 35 m/s gusts without loosening | Met on paper (band preload assumed)
R14 | Base node 2.45 kg (0.05 kg margin); 2.61 kg with the hot-climate shield, which R14 excludes | 2.5 kg or less, base node | Met on paper
R15 | Cell swap estimate 7 min (9 min with the shield, which lifts off after four thumb screws), screwdriver, plug-in cell lead | 10 min or less, no soldering | Met by design
R16 | $139.50 base node; $148.50 with the shield | $150 or less (FieldNode core, gateway excluded) | Met on paper
R17 | CERN-OHL-S-2.0 and MIT; standard LoRaWAN | Open files, any network server | Met by design
R18 | Core forwards only what the sensor firmware passes | No images or audio leave the node | Met by design

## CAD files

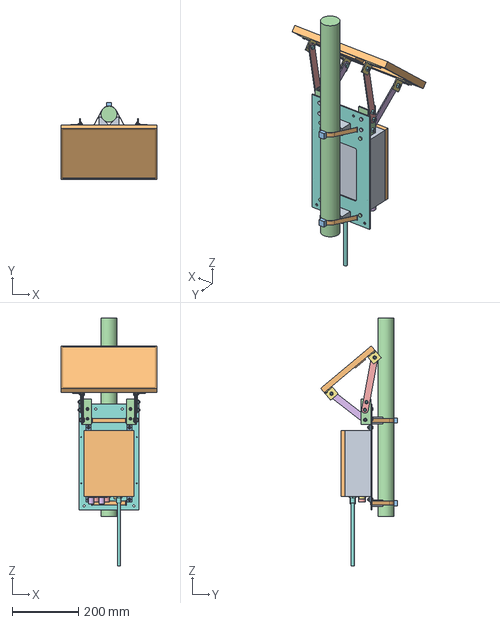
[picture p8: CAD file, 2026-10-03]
cad/step/fieldnode-assembly.step
290.0 x 232.0 x 750.0 mm

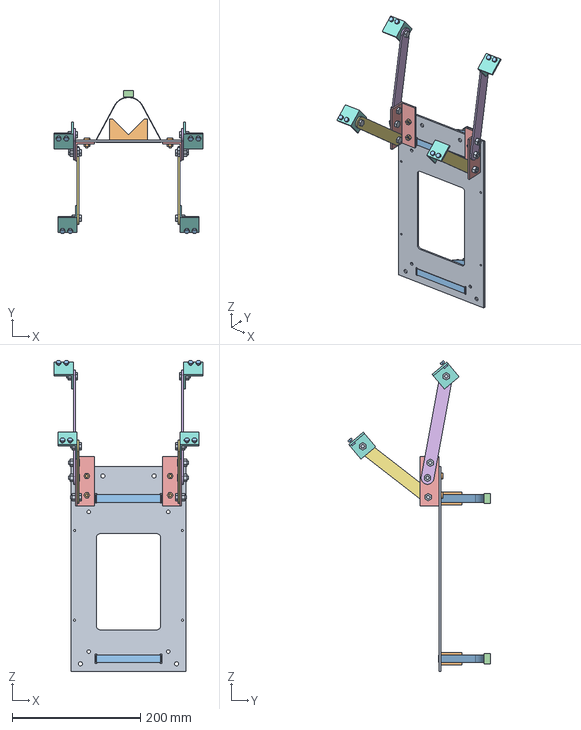
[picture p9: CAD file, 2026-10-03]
cad/step/fieldnode-mount.step
232.0 x 222.5 x 485.1 mm

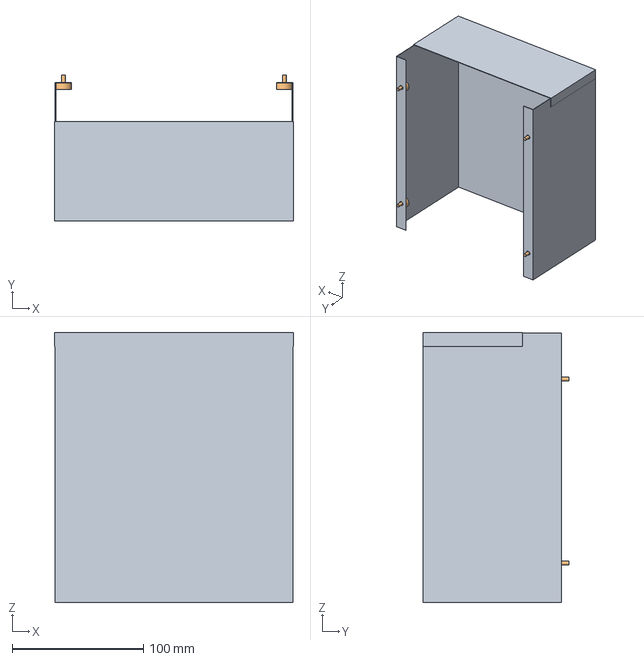
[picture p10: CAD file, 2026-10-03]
cad/step/fieldnode-shield.step
182.0 x 111.0 x 205.5 mm

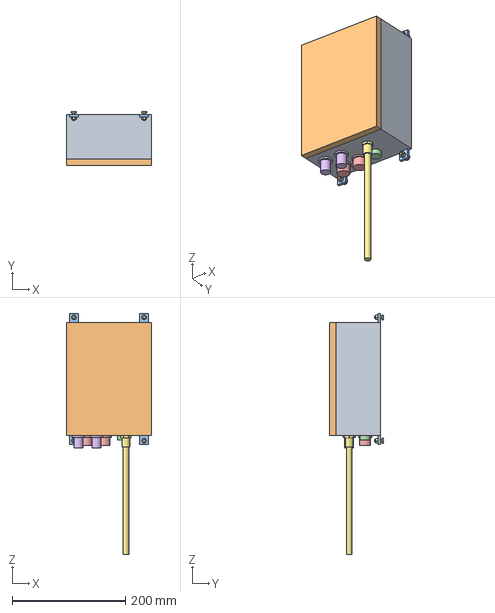
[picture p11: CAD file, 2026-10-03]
cad/step/fieldnode-core.step
150.0 x 95.8 x 426.0 mm

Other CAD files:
cad/stl/fieldnode-assembly.stl
cad/stl/fieldnode-core.stl
cad/stl/fieldnode-mount.stl
cad/stl/fieldnode-shield.stl

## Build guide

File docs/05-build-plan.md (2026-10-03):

---
doc_id: FND-BLD-001
title: FieldNode prototype build plan
project: FieldNode
doc_type: Build plan
version: "0.5"
status: Draft
date: '2026-10-02'
author: Amish Chadha
license: CERN-OHL-S-2.0
revisions:
  - version: "0.1"
    date: '2026-09-30'
    author: Amish Chadha
    change: First build plan at TRL 3, text only (withdrawn)
  - version: "0.2"
    date: '2026-09-30'
    author: Amish Chadha
    change: Rewritten from the template with pictures by component and step; design made constructable (FND-DDR-003)
  - version: "0.3"
    date: '2026-09-30'
    author: Amish Chadha
    change: Open decisions moved to the design decisions register
  - version: "0.4"
    date: '2026-10-02'
    author: Amish Chadha
    change: "Port pinout and antenna band as decided on 2026-10-02 (FND-DEC-001)"
  - version: "0.5"
    date: '2026-10-02'
    author: Amish Chadha
    change: "Approved follow-ups carried out: programming header on the power modules, pinout on the wiring picture, firmware load check, pictures regenerated"
---

# FieldNode prototype build plan

**Plan, not yet built.** How to build the first proof-of-concept prototype, component by component. Building and testing to it is TRL 4 work. Decisions still to be made are kept in the design decisions register ([docs/06-design-decisions.md](06-design-decisions.md)), not here.

## 1. What you are building

Figure 1. Every component, pulled apart and numbered in build order

*Figure 1. Every component pulled apart and numbered in build order; 15, the sun shield, is fitted only at hot sites.*

The prototype is one FieldNode on a short length of 48 mm pole: a grey plastic box holding a battery cell and small electronic modules, hung on an aluminium back plate that clamps to the pole, with a solar panel above it on a small bracket that also keeps rain off the box. Figure 1 shows the 15 components in the order you make or fit them. Nine are made in a small workshop: the back plate, two V-blocks, the bracket (two plate clips, two posts, two struts and four panel clips), the printed internal plate and the folded sun shield; the bought box is drilled. Everything else is bought and fitted: the box and lid, cable glands, sensor sockets, vent, antenna, panel, cell, electronic modules and band clamps. The work is sawing, drilling, filing and bending aluminium bar, angle and sheet, drilling a plastic box, one 3D print, and wiring bought modules together with screw terminals. The parts cost about $148.50 with the shield, from the bill of materials.

> **Safety:** The prototype holds a lithium iron phosphate cell of about 19 Wh and its charger. Keep the fuse out and the cell out of the holder until section 6 says otherwise, never charge it below 0 °C or above 45 °C, and never leave a first build charging unattended. Cut aluminium edges are sharp: deburr everything and wear gloves when handling bar and sheet. Printing ASA gives off fumes; print in a ventilated space.

## 2. What changed to make it buildable

The concept showed what the node does; some of its parts could not be made or fixed as drawn. Each change below keeps what the node does, and all of them are recorded in decision record FND-DDR-003, open for Amish's review.

*Table 1. Changes from the concept.*

| Component | The concept had | The buildable design has | Why |
| --- | --- | --- | --- |
| V-blocks | A block 50 wide, 22 deep and 30 tall with a round seat | A block 60 wide, 33 deep and 20 tall with a true 90° V (Figure 3) | The pole now rests on both faces of the V, not on its edges |
| Holes in the bottom of the box | Six holes in one line; two glands 2 mm apart; the vent overlapping the antenna | Two rows, 27 and 55 mm from the back face, every flange at least 8 mm from the next (Figure 7) | Room for a spanner and the inside nuts; nothing overlaps |
| Box to back plate | No fixing | Four bought lugs at the box's back corners, one M5 screw each (Figure 8) | The box back stays sealed |
| Internal plate | No fixing | Four M4 screws into the box's moulded bosses, 6 mm off the back wall (Figure 11) | Uses what a stock box already has |
| Panel bracket | Flat bars standing on their edges against the plate and panel, with no frame behind the panel end; the panel could swing | Angle clips on the plate and on the panel frame's back lip, with flat bars bolted flat to them; each post held by two bolts (Figures 14, 18 and 19) | Every joint is face to face and bolted, and the frame is a rigid triangle |
| Sun shield | No fixing; it blocked the lid | Folded flanges on the plate and four thumb screws; it slides off to open the lid (Figure 21) | A fixing you can undo by hand at the pole |
| Wiring | No fuses on the sensor supplies; no way to unplug the internal plate | A plug-in connector strip and a resettable fuse on each sensor supply (Figure 12) | A shorted sensor cable cannot drain the cell; the plate lifts out as one unit |
| Firmware updates | No way to load new firmware in the field | A six-pin serial programming header on the power modules, pins facing the lid (Figures 10 and 12) | Firmware is loaded by cable with the lid open, with no extra hole in the box (decided on 2026-10-02) |
| Back plate | Solid | A 100 x 150 mm window behind the box, and 20 mm (not 25 mm) bar for the bracket | Keeps the node under its 2.5 kg mass limit after the added clips and bolts |

## 3. Making the components

Make and check each component before the assembly step that needs it. Sizes are in millimetres. "Left" and "right" are as seen standing in front of the node, looking at the lid. Workshop tolerance is 0.5 mm unless a step says otherwise; drawings do not carry tolerances before TRL 4.

### 3.1 Back plate

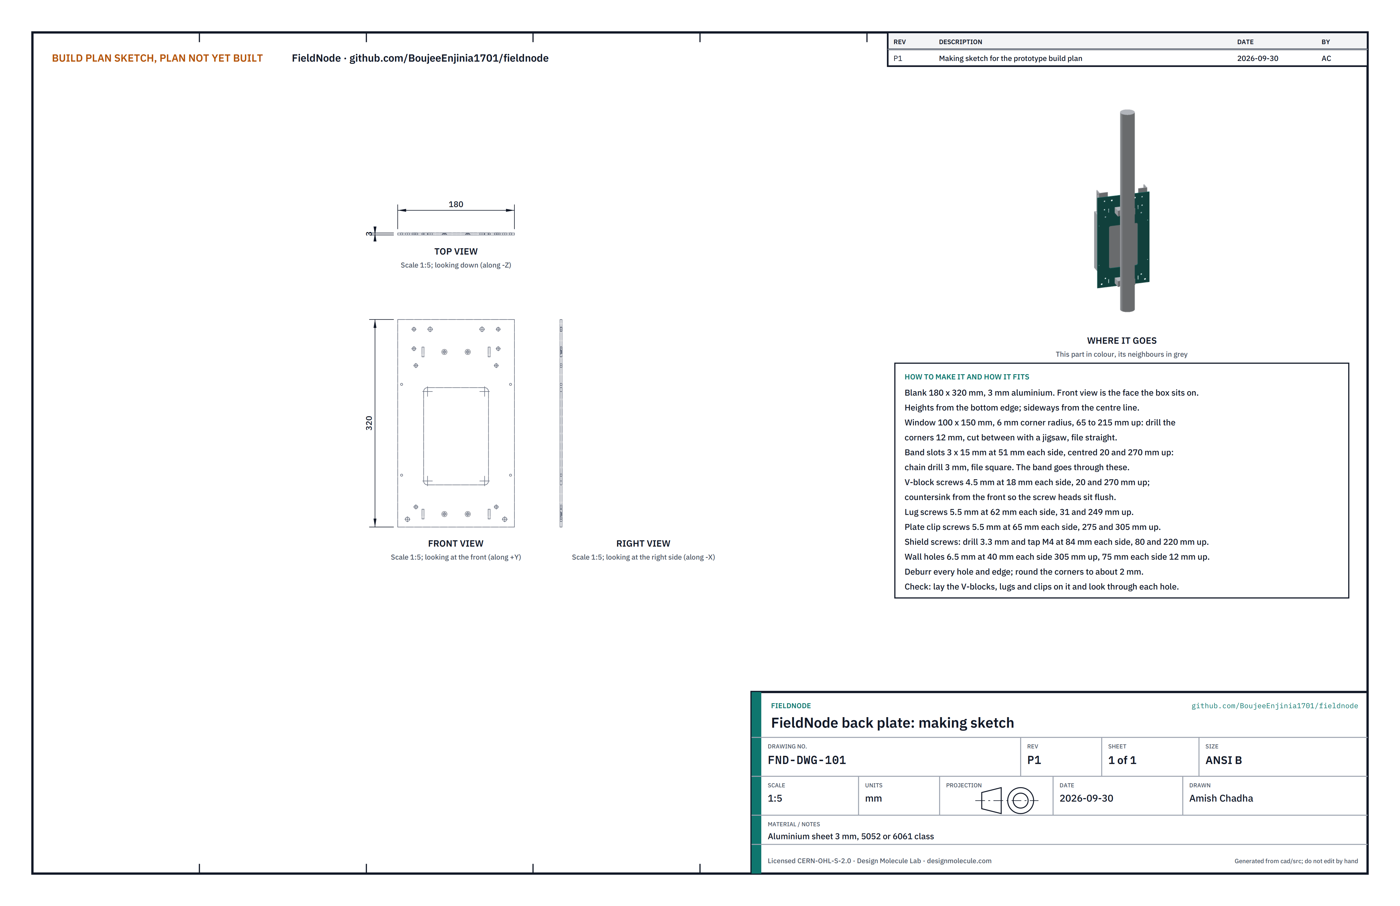
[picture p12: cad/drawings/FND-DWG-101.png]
Figure 2. Making sketch of the back plate


*Figure 2. Back plate making sketch (FND-DWG-101).*

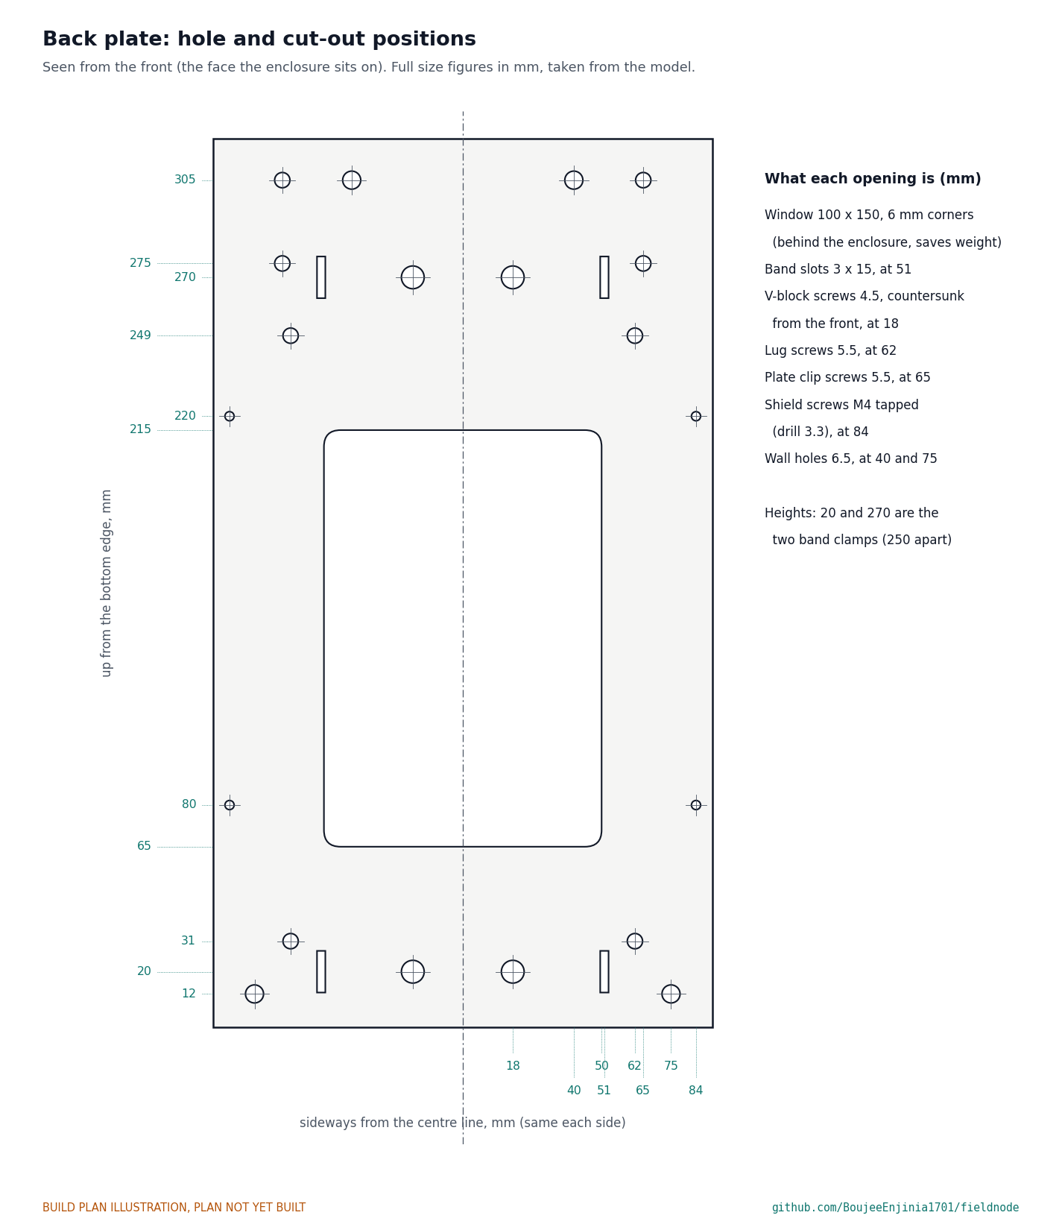
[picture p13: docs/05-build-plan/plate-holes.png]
Figure 2a. Hole and cut-out positions on the back plate


*Figure 2a. Every hole and cut-out, full size figures, measured up from the bottom edge and sideways from the centre line.*

**What it is and what it is made from.** The flat plate that everything hangs on: the box on its front, the V-blocks on its back, the bracket clips at its top. Aluminium sheet 3 mm thick, 5052 or 6061 class, cut to 180 x 320 mm.

**How to make it.**

1. Cut the blank to 180 x 320 mm, square. File the edges and round the corners to about 2 mm.
2. Scribe a centre line down the long side. Choose one face as the front (the box side) and mark it.
3. Mark every hole from Figure 2a: heights up from the bottom edge, sideways from the centre line. Most holes are in pairs, the same distance each side.
4. Band slots: four slots 3 wide and 15 tall, 51 each side of centre, centred 20 and 270 up. Chain drill with a 3 mm drill and file the slots square. The bands go through these.
5. V-block screw holes: four 4.5 mm holes, 18 each side of centre, 20 and 270 up. Countersink them from the front so M4 countersunk screws sit flush.
6. Lug holes: four 5.5 mm holes, 62 each side of centre, 31 and 249 up.
7. Plate clip holes: four 5.5 mm holes, 65 each side of centre, 275 and 305 up.
8. Shield screw holes: four holes 84 each side of centre, 80 and 220 up. Drill 3.3 mm and tap M4.
9. Wall holes: 6.5 mm, 40 each side of centre at 305 up, and 75 each side of centre at 12 up (for wall mounting later; drill them now).
10. Window: 100 wide x 150 tall, centred on the centre line, from 65 to 215 up. Drill a 12 mm hole in each corner (these make the 6 mm corner radius), cut between the holes with a jigsaw and a metal blade, and file the edges straight.
11. Deburr every hole on both faces.

**How it fits the parts next to it.** The box's back sits flat on the front face, between 40 and 240 up, held by four lugs (Figure 8). The V-blocks sit flat on the back face (Figure 3). The bracket's plate clips sit flat on the front face at the top, from 258 up to 15 above the top edge (Figure 14). The shield flanges sit flat on the front face either side of the box (Figure 21).

**Check before moving on.** Lay the V-blocks, lugs and plate clips on the plate and look through each hole: the holes must line up without forcing a screw.

### 3.2 V-blocks (make 2)

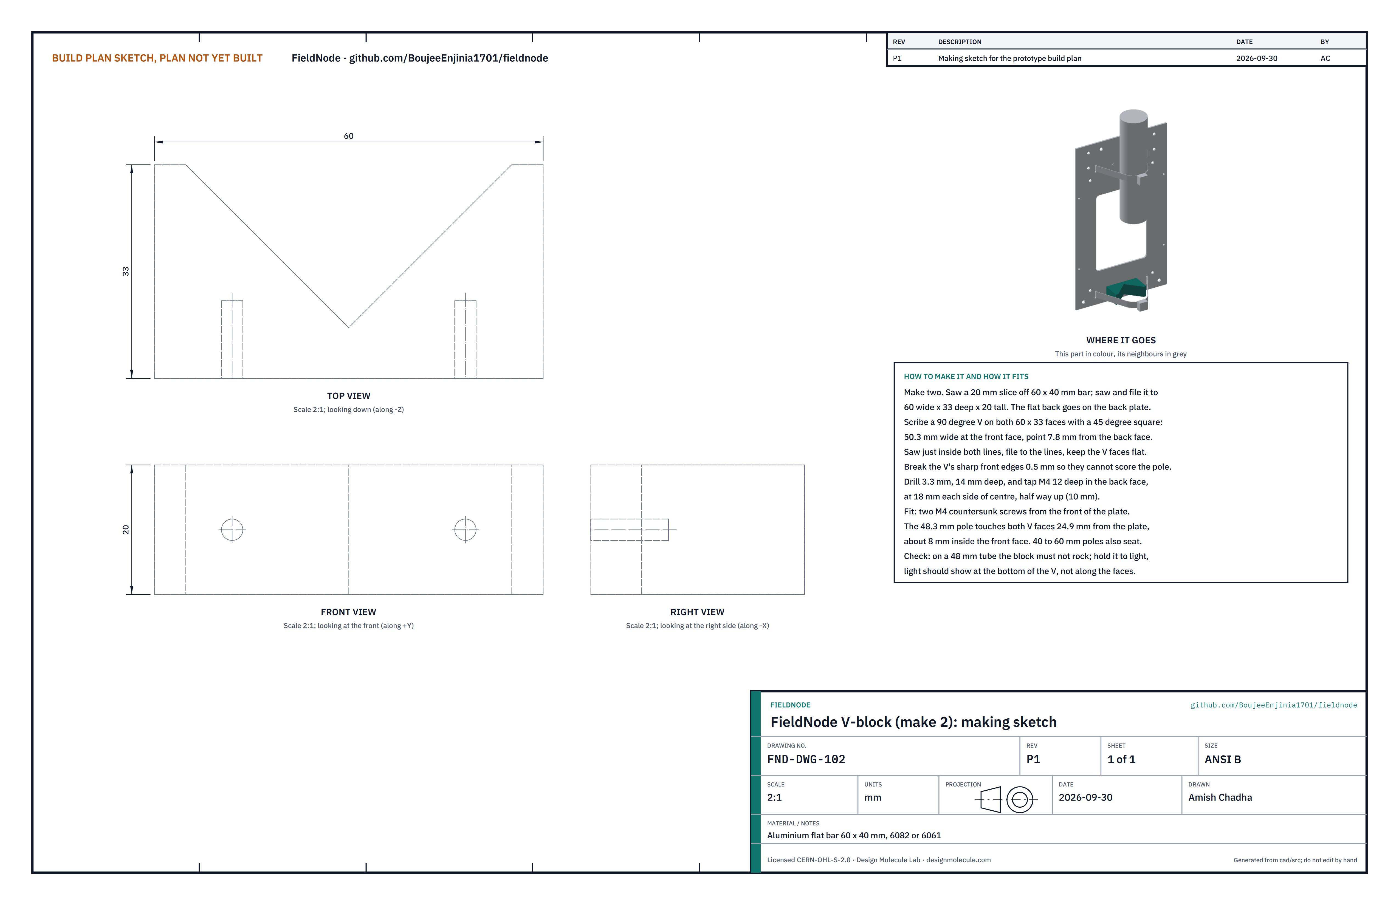
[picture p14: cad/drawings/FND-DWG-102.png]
Figure 3. Making sketch of the V-block


*Figure 3. V-block making sketch (FND-DWG-102).*

**What it is and what it is made from.** A block with a V cut in it that the pole sits in, one at each band clamp. Aluminium flat bar 60 x 40 mm, 6082 or 6061 class.

**How to make it.**

1. Saw two slices 20 mm thick off the bar. Saw and file each to 60 wide, 33 deep and 20 tall. The 60 x 20 face that will sit on the plate is the back face; file it flat.
2. On each 60 x 33 face, scribe the V with a 45° square: two lines from the front face, 50.3 apart where they start, meeting at a point 7.8 from the back face, centred on the width.
3. Saw just inside both lines, then file to the lines. Keep the two V faces flat and square to the block's faces.
4. Break the sharp front edges of the V by 0.5 mm so they cannot scratch a galvanised pole.
5. On the back face, 18 each side of centre and half way up (10 from an edge), drill 3.3 mm 14 deep and tap M4 12 deep.

**How it fits the parts next to it.**

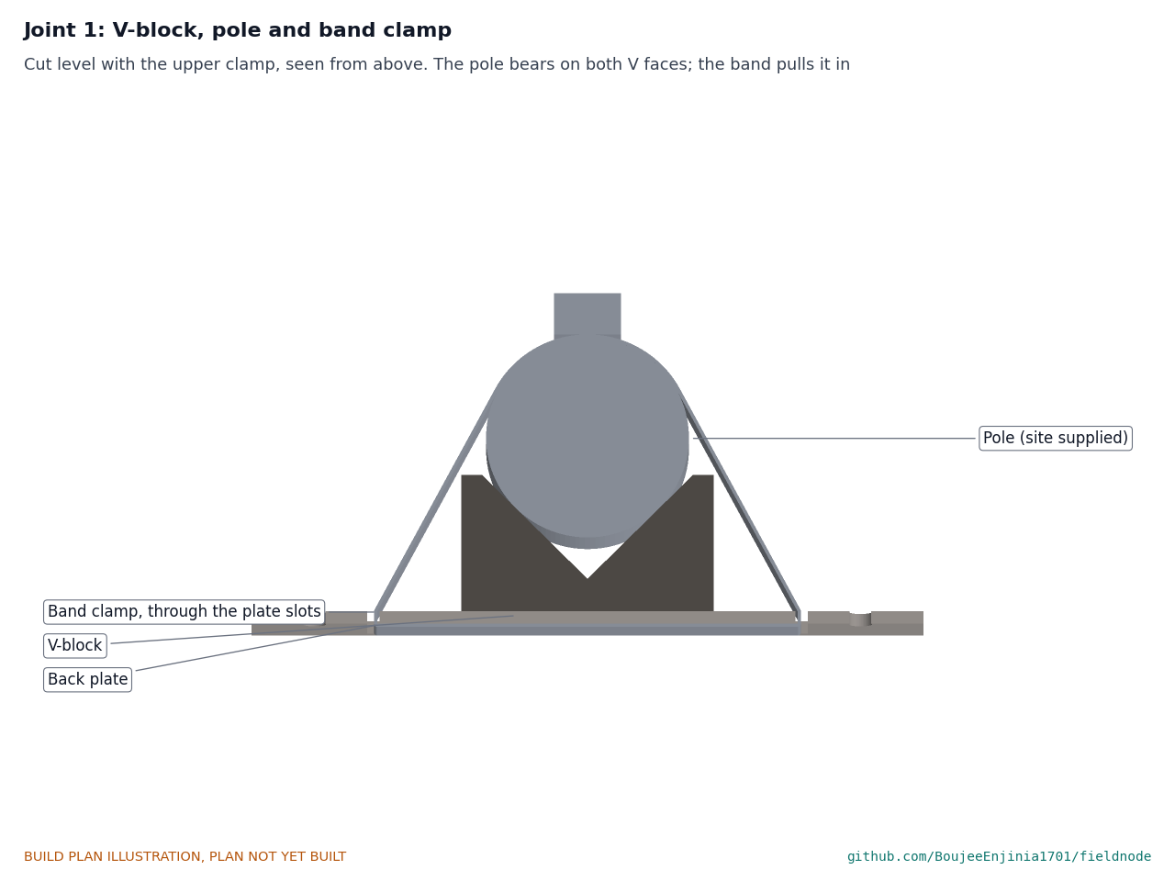
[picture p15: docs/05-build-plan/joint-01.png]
Figure 4. Joint 1: V-block, pole and band clamp, seen from above


*Figure 4. The pole sits in the V and touches both faces; the band clamp goes round the pole and pulls the pole into the V.*

The back face sits flat on the back of the back plate, held by two M4 countersunk screws put in from the front of the plate with a drop of medium threadlocker. The 48 mm pole touches both faces of the V about 8 mm in from the front face of the block; it never touches the bottom of the V. Poles from 40 to 60 mm also seat on both faces. The band passes 2 mm clear of the block's outer corners.

**Check before moving on.** Hold the block against a 48 mm tube: it must not rock, and you should see light at the bottom of the V but not along its faces.

### 3.3 Enclosure body, drilled, with its glands, ports, vent, antenna and lugs

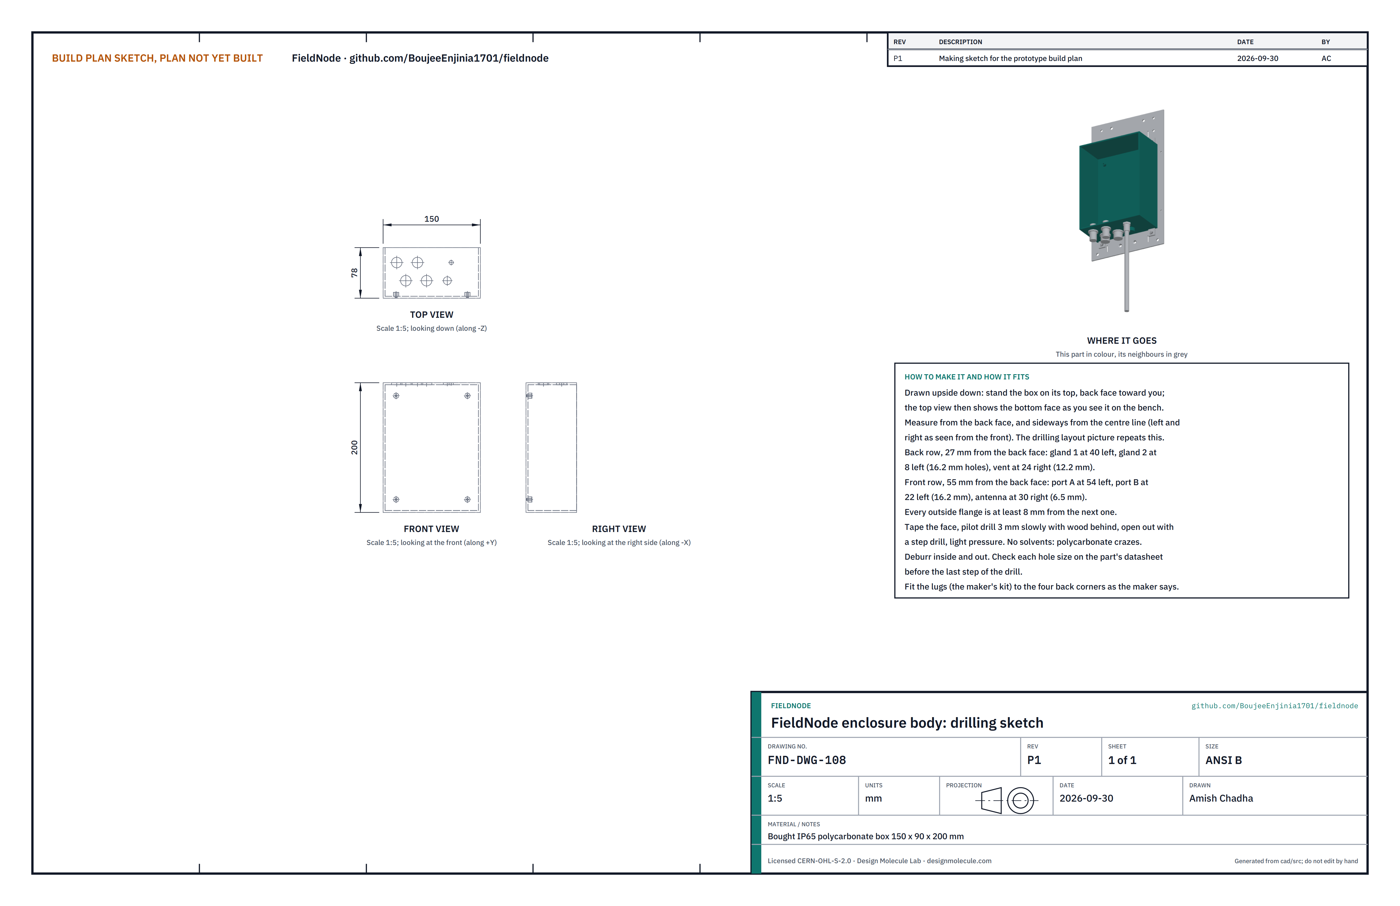
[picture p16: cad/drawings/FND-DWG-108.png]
Figure 5. Drilling sketch of the enclosure body


*Figure 5. Enclosure drilling sketch (FND-DWG-108), drawn upside down so the top view shows the bottom face.*

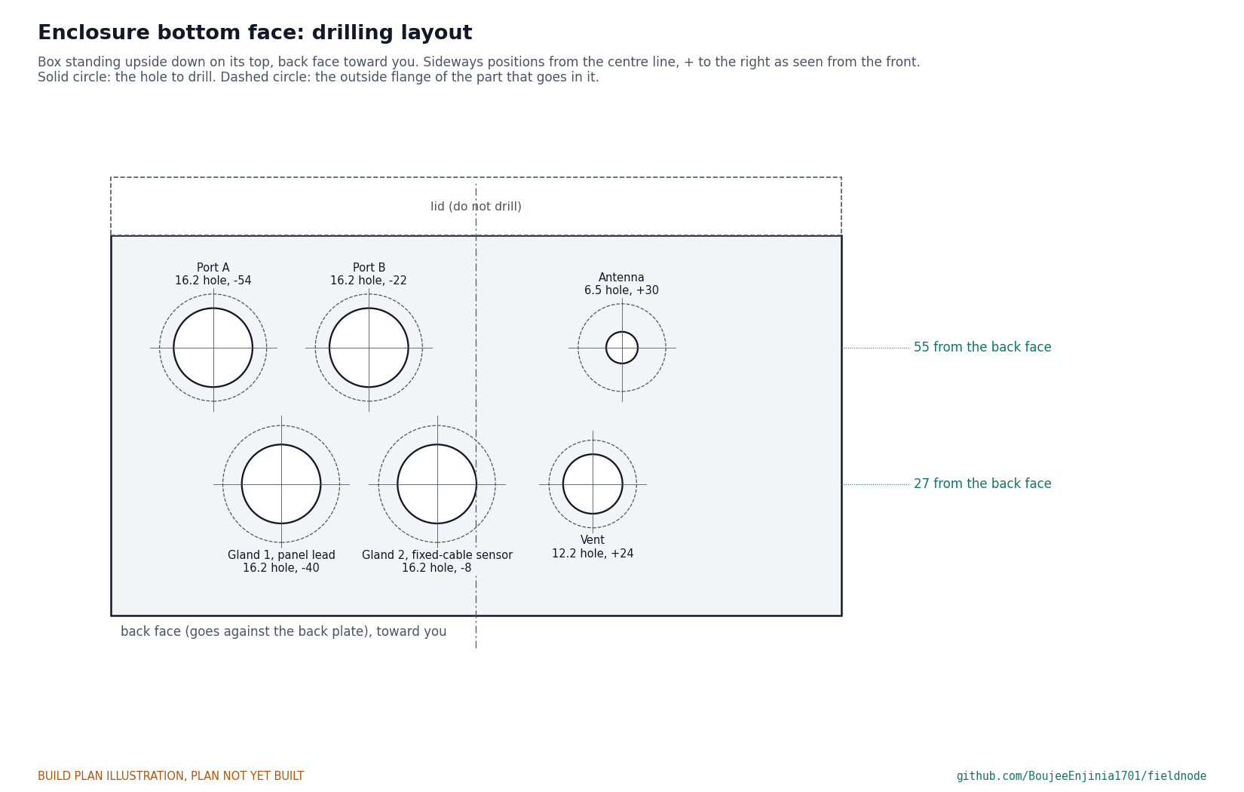
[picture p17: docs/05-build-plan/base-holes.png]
Figure 6. Bottom face drilling layout


*Figure 6. Drilling layout, with the box standing upside down on its top and its back face toward you.*

**What it is and what it is made from.** A bought grey polycarbonate box, 150 wide, 90 deep and 200 tall, rated IP65, with a gasketed lid on the front, four moulded bosses inside the back wall and the maker's kit of four external mounting lugs. Six holes are drilled in its bottom face.

**How to make it.**

1. Stand the box upside down on its top on a soft cloth, back face toward you. Cover the bottom face with masking tape.
2. Mark the holes from Figure 6. Back row, 27 from the back face: gland 1 (panel lead) 40 left of centre, gland 2 8 left, vent 24 right. Front row, 55 from the back face: port A 54 left, port B 22 left, antenna 30 right. Left and right are as seen from the front of the box.
3. Put a block of wood inside under the face. Pilot drill every hole 3 mm at low speed; do not centre punch hard, since polycarbonate cracks.
4. Open each hole with a step drill, light pressure, low speed: 16.2 for the two glands and two ports, 12.2 for the vent, 6.5 for the antenna. Before the last step, check the size against the part's datasheet.
5. Deburr inside and out, peel the tape, and clean with water and mild soap only; solvents craze polycarbonate.
6. Fit the four lugs to the box's back corners as the lug kit's maker describes.

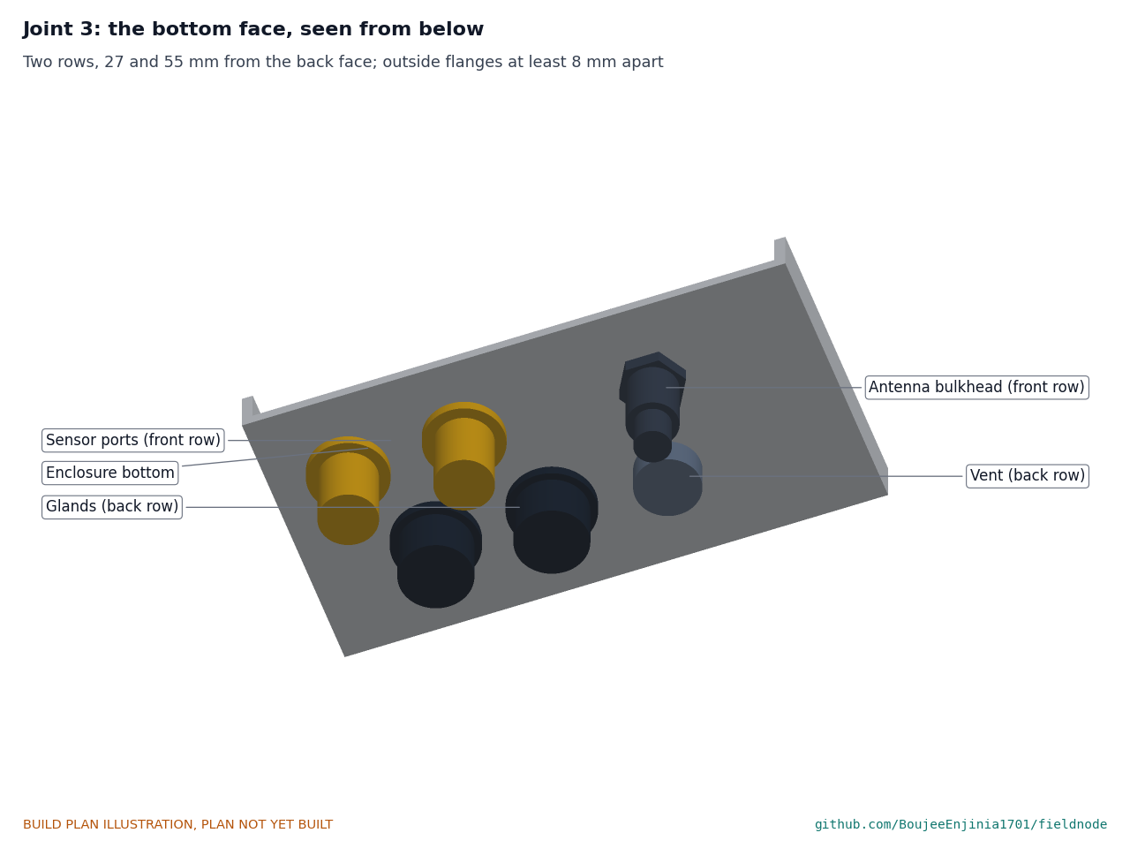
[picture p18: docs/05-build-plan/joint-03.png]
Figure 7. Joint 3: the bottom face, seen from below


*Figure 7. Glands and vent in the back row, sensor ports and antenna in the front row.*

**How it fits the parts next to it.** Each gland, port, vent and antenna bulkhead goes in from below with its sealing washer outside and its nut inside (step 2). The outside flanges are at least 8 mm apart and the inside nuts about 6 mm apart, so a spanner or deep socket fits. The box's back sits flat on the back plate, held by the lugs:

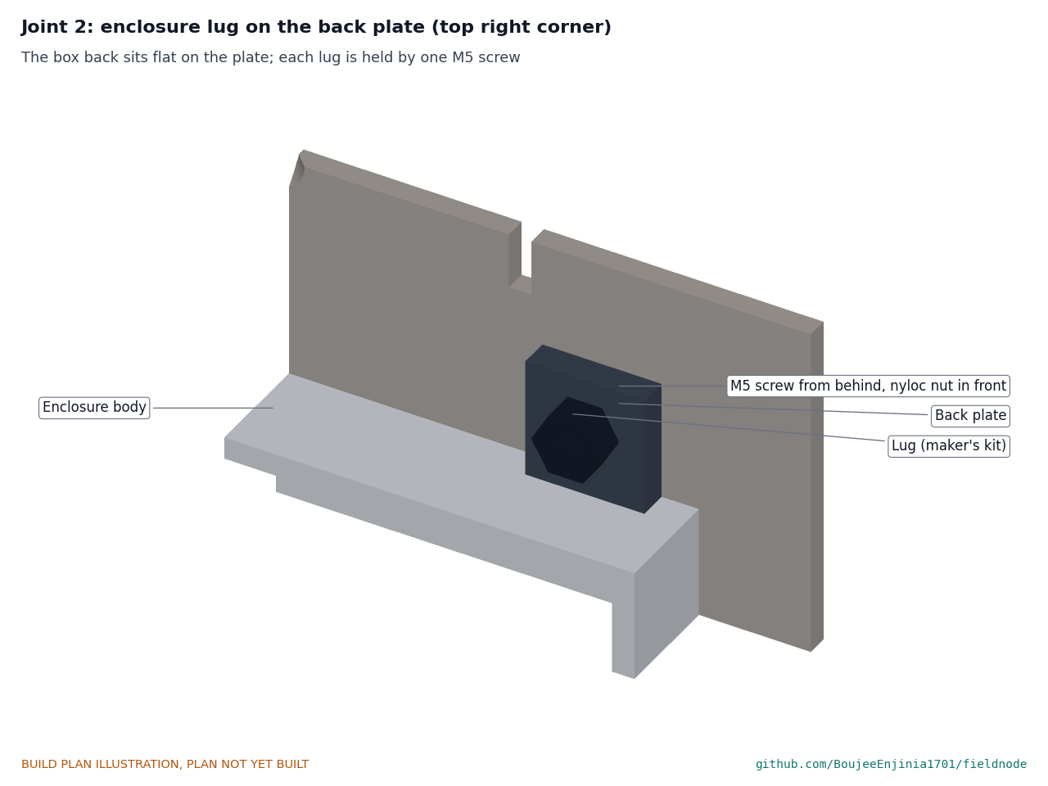
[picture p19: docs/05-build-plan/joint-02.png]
Figure 8. Joint 2: enclosure lug on the back plate


*Figure 8. Each lug lies flat on the plate beside the box and is held by one M5 button-head screw from behind the plate, nyloc nut in front.*

**Check before moving on.** Each part seats flat on its washer; no crack runs out from any hole under a bright lamp; the box sits flat on the back plate with all four lug holes lined up.

### 3.4 Internal plate and the electronics on it

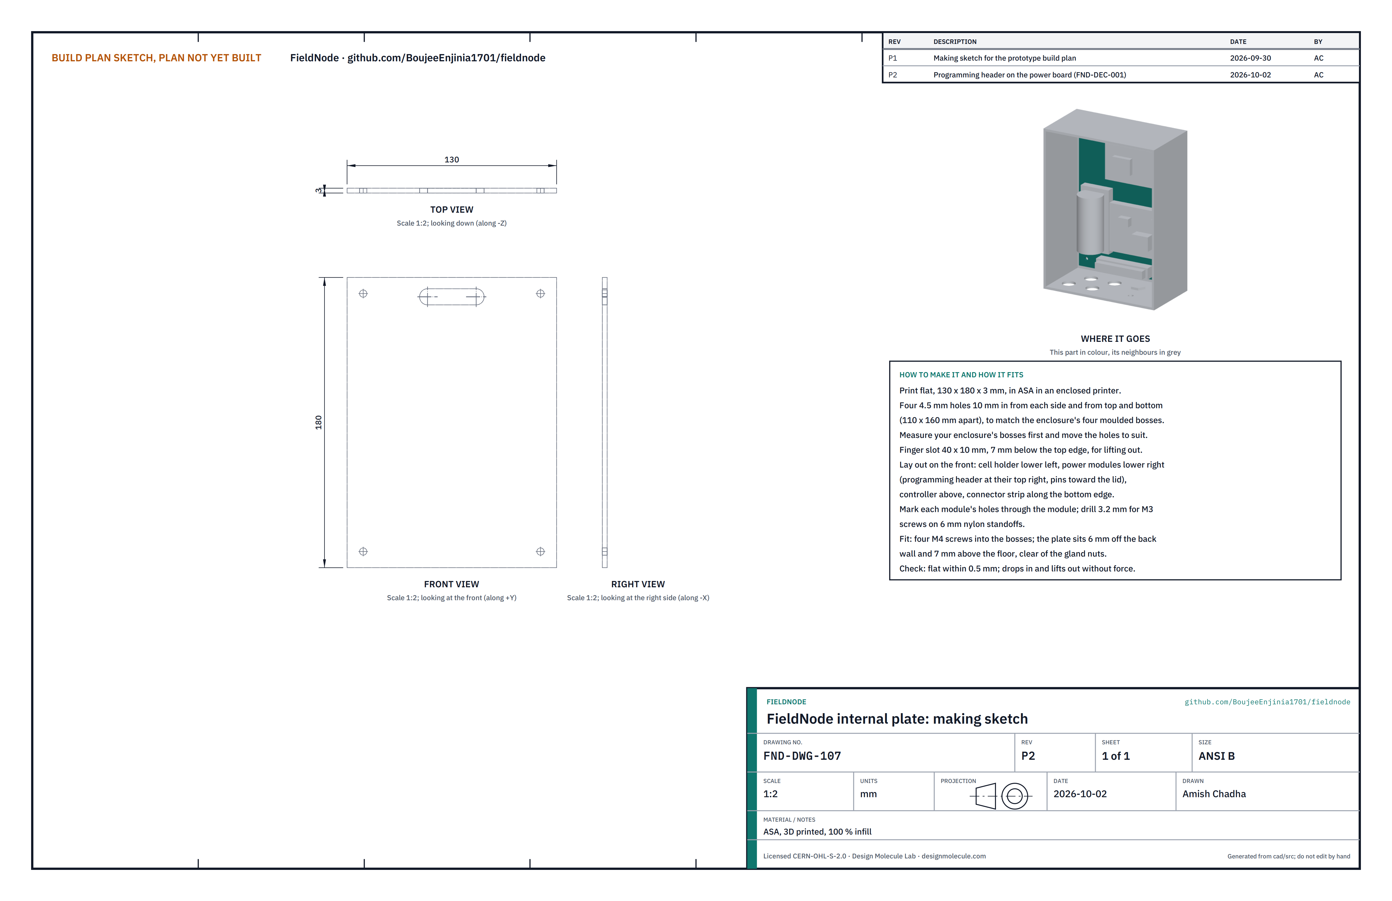
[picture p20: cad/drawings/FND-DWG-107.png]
Figure 9. Making sketch of the internal plate


*Figure 9. Internal plate making sketch (FND-DWG-107).*

**What it is and what it is made from.** A printed plate that carries the cell holder, the electronic modules and the connector strip, and lifts out of the box as one unit. ASA plastic, 130 x 180 x 3 mm, printed flat at 100 % infill in an enclosed printer.

**How to make it.**

1. Measure the four bosses inside your box. The model assumes they are 110 apart across and 160 apart up and down; move the plate's holes to match your box.
2. Print the plate with four 4.5 mm holes at the bosses and a 40 x 10 mm finger slot 7 below the top edge. Let it cool on the bed so it does not warp.
3. Lay out the parts on the front face as Figure 10 shows: cell holder lower left, power modules lower right, controller above them, connector strip along the bottom edge. The six-pin programming header goes at the top right of the power modules, about 92 mm above the floor of the box and 50 mm right of centre, with its pins pointing straight out toward the lid; the pin tips then sit about 47 mm in from the open front of the box, with nothing in front of them, so the programming cable plugs on with the lid open.
4. Mark each module's mounting holes through the module, drill 3.2 mm, and fit the modules on M3 screws with 6 mm nylon standoffs. Fit the cell holder with no cell in it and its fuse out.
5. Wire the modules as Figure 12 shows (section 3.4.1).

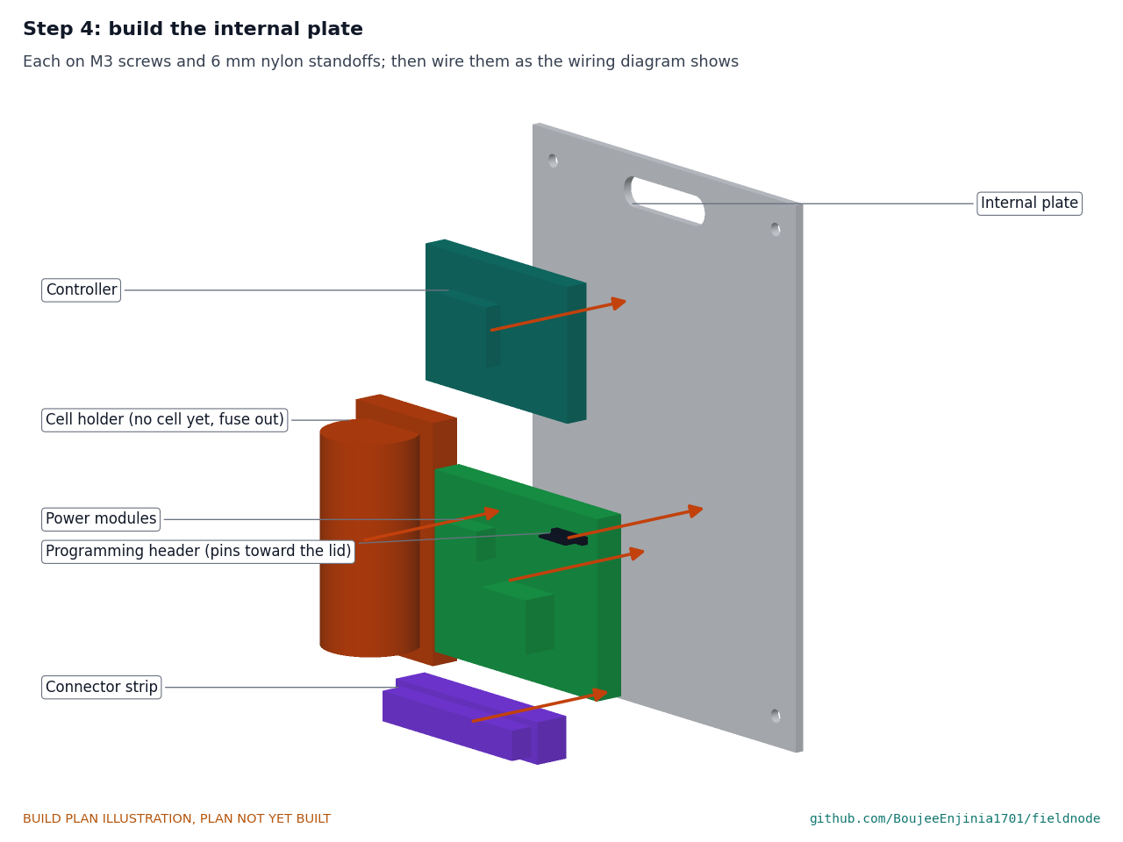
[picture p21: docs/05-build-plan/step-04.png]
Figure 10. Step 4 picture: parts on the internal plate


*Figure 10. Where each part goes on the internal plate.*

**How it fits the parts next to it.**

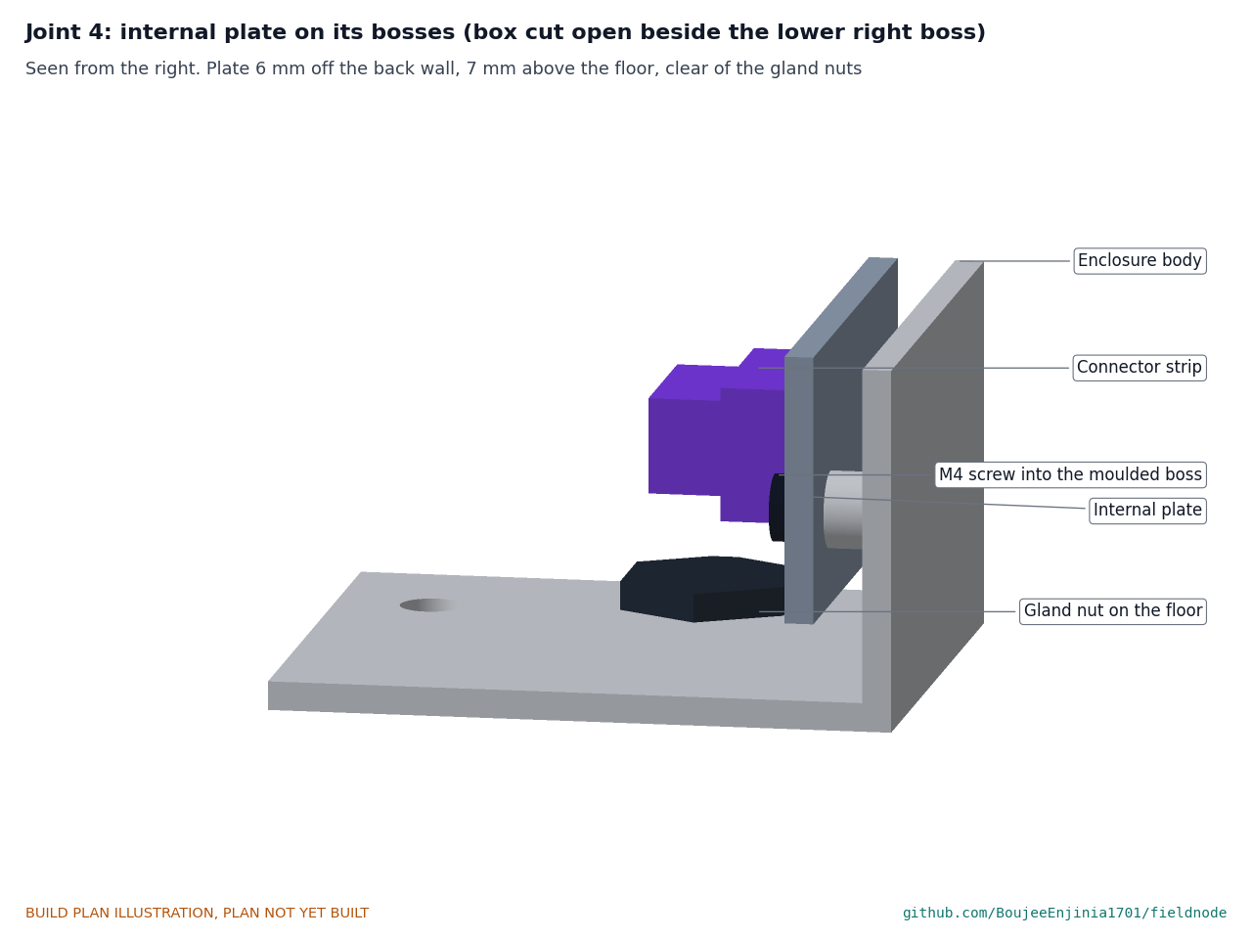
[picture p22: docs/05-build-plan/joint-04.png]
Figure 11. Joint 4: internal plate on its bosses


*Figure 11. The plate sits on the four moulded bosses, 6 mm off the back wall and 7 mm above the floor, clear of the gland nuts, held by four M4 screws.*

**Check before moving on.** The plate is flat within 0.5 mm and drops in and lifts out without force.

#### 3.4.1 Wiring

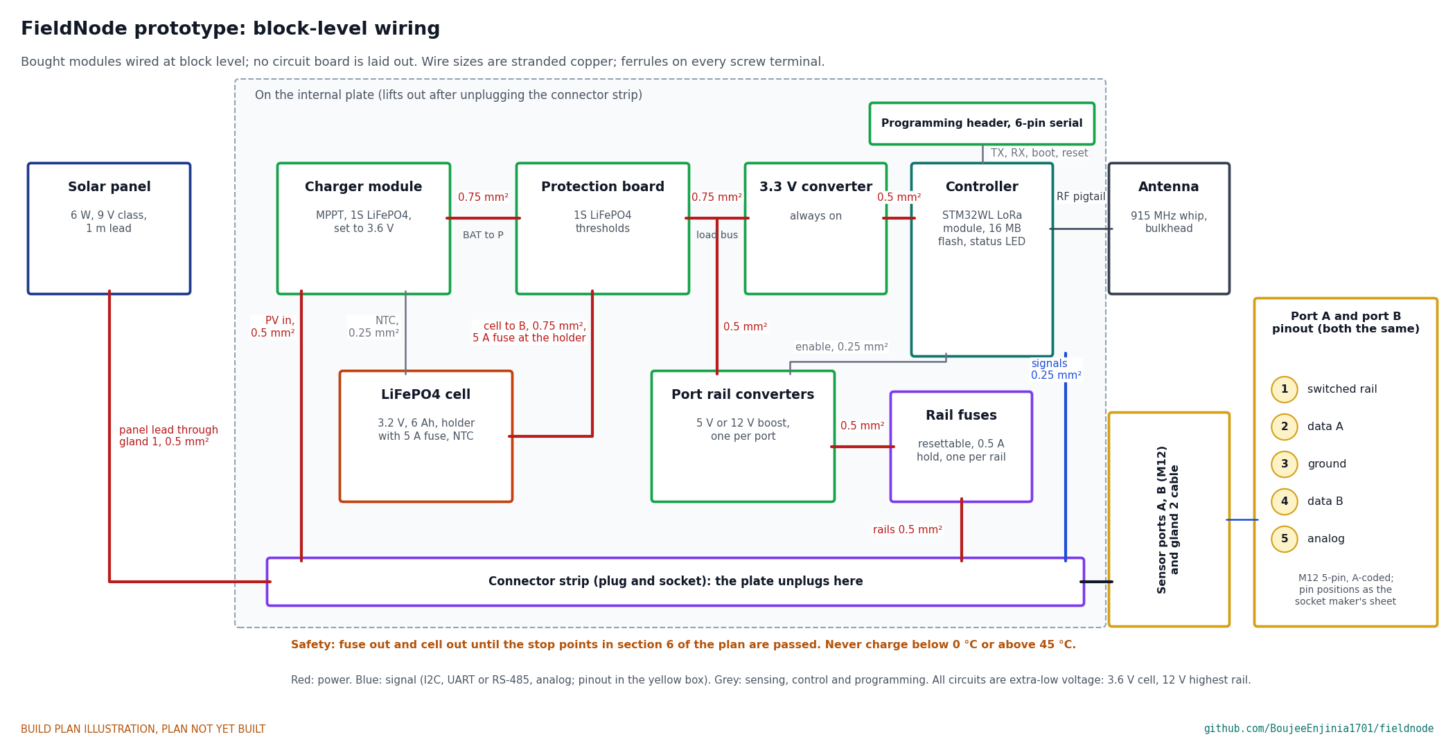
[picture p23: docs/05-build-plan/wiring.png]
Figure 12. Block-level wiring


*Figure 12. Block-level wiring with wire sizes, the pinout of both sensor ports and the programming header. No circuit board is laid out at this stage; bought modules stand in for the power board.*

The power board in the bill of materials is a custom board, which is TRL 4 work. For this prototype, buy modules that meet this specification:

*Table 2. Modules that stand in for the power board.*

| Module | What to buy |
| --- | --- |
| Charger | Single-cell lithium iron phosphate charger with maximum power point tracking (bq24650 or LT3652 class), charge voltage set to 3.6 V, input range covering the 9 V class panel from about 7.4 V when hot up to its open-circuit voltage when cold, and a temperature input that stops charging below 0 °C and above 45 °C |
| Protection board | Single-cell protection board with lithium iron phosphate limits (not lithium-ion limits), rated at 5 A or more |
| 3.3 V converter | Buck-boost converter, always on, feeding the controller |
| Port rail converters | 5 V or 12 V boost converters with an enable input, one per sensor port |
| Rail fuses | Two resettable fuses, about 0.5 A hold, one on each port supply |
| Controller | STM32WL-class LoRa module (RAK3172 or Wio-E5) on its maker's breakout, 16 MB flash breakout, status LED |
| Programming header | A single row of six straight pins at 2.54 mm pitch on a small board fixed to the power modules: ground, 3.3 V, serial transmit, serial receive, boot and reset. The module has no USB port, so it is loaded over its serial port |

Wire it like this, with stranded copper and a ferrule on every screw terminal:

1. Cell holder to the protection board's cell terminals, through the 5 A fuse in the holder lead: 0.75 mm² (18 AWG).
2. Charger battery output to the protection board's pack terminals: 0.75 mm².
3. Protection board pack terminals to the load bus (a small terminal block): 0.75 mm².
4. Load bus to the 3.3 V converter and on to the controller: 0.5 mm² (20 AWG).
5. Load bus to each port rail converter, through its resettable fuse, to the connector strip: 0.5 mm².
6. Controller signal pins to the connector strip: 0.25 mm² (24 AWG). Wire both ports the same, to the pinout in the yellow box of Figure 12: pin 1 switched supply, pin 2 data A, pin 3 ground, pin 4 data B, pin 5 analog. Find each pin's position on the socket from its maker's datasheet, and mark the pin numbers on the inside of the box beside each socket.
7. Controller output pin to each converter's enable input: 0.25 mm².
8. The cell holder's temperature sensor to the charger's temperature input: 0.25 mm², twisted, with the sensor taped to the cell.
9. The panel lead comes in through gland 1 and plugs into the connector strip; the strip then feeds the charger input: 0.5 mm².
10. The radio pigtail runs from the controller to the antenna bulkhead, away from the power wires.
11. Programming header to the controller: ground, 3.3 V, serial transmit and receive (crossed, so the header's transmit goes to the module's receive), boot and reset, 0.25 mm², kept short and away from the charger.

Check that the charger's temperature window really is 0 to 45 °C in its datasheet before buying: some chargers of this class fix a different window.

**Check before moving on.** Every wire continues end to end; with the cell out and the fuse out, the pack terminals and every rail read open to ground; every wire is labelled.

### 3.5 Plate clips (make 2: a left and a right)

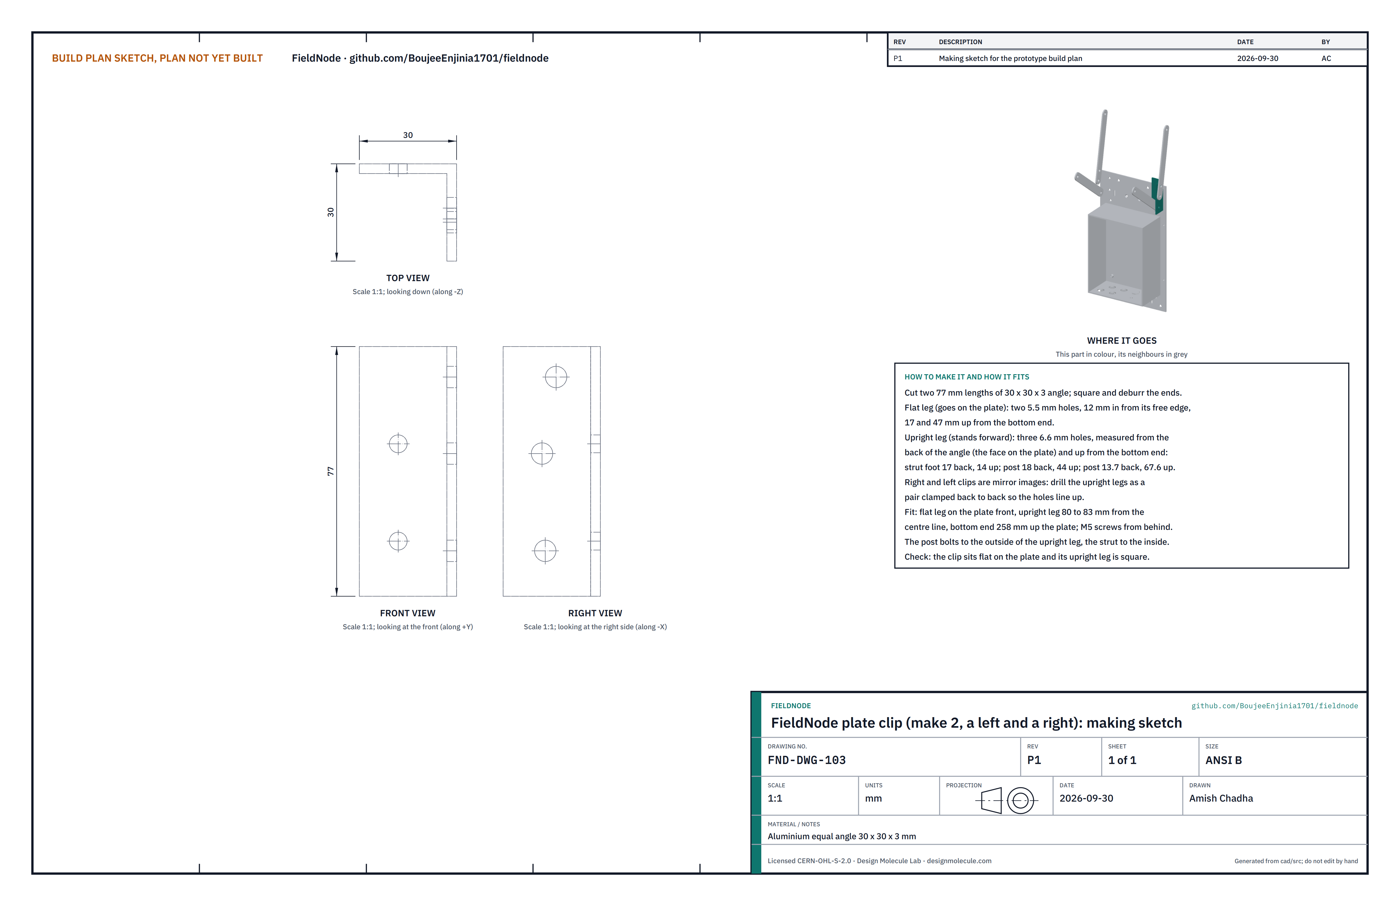
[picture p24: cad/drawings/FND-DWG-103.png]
Figure 13. Making sketch of the plate clip


*Figure 13. Plate clip making sketch (FND-DWG-103).*

**What it is and what it is made from.** A short angle bolted to the top of the back plate; its forward leg carries the foot of a post and the foot of a strut. Aluminium equal angle 30 x 30 x 3 mm.

**How to make it.**

1. Cut two 77 mm lengths; square and deburr the ends.
2. Flat leg (the one that goes on the plate): two 5.5 mm holes, 12 in from the leg's free edge, 17 and 47 up from the bottom end.
3. Upright leg (the one that stands forward): three 6.6 mm holes, each measured back from the face of the angle that sits on the plate and up from the bottom end: strut foot 17 back and 14 up; post lower 18 back and 44 up; post upper 13.7 back and 67.6 up.
4. The right and left clips are mirror images. Clamp the two upright legs back to back and drill them together so the holes match.

**How it fits the parts next to it.**

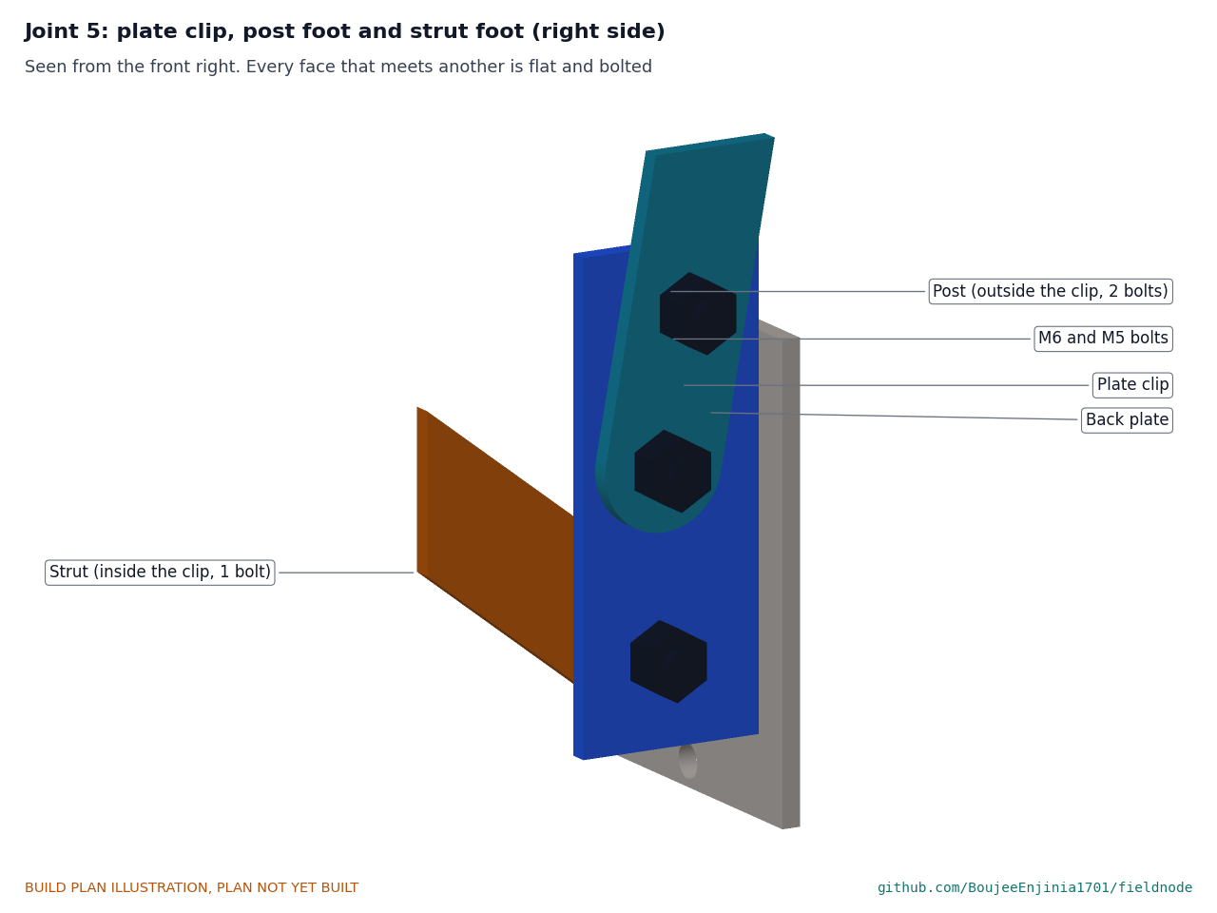
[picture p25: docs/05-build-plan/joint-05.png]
Figure 14. Joint 5: plate clip, post foot and strut foot


*Figure 14. The post bolts to the outside of the clip's upright leg with two bolts; the strut bolts to the inside with one.*

The flat leg sits flat on the front of the back plate with its bottom end 258 up the plate and its top end 15 above the plate's top edge; the upright leg stands forward 80 to 83 from the centre line. Two M5 button-head screws go through from behind the plate with nyloc nuts in front.

**Check before moving on.** The clip sits flat on the plate and its upright leg is square to it.

### 3.6 Posts (make 2)

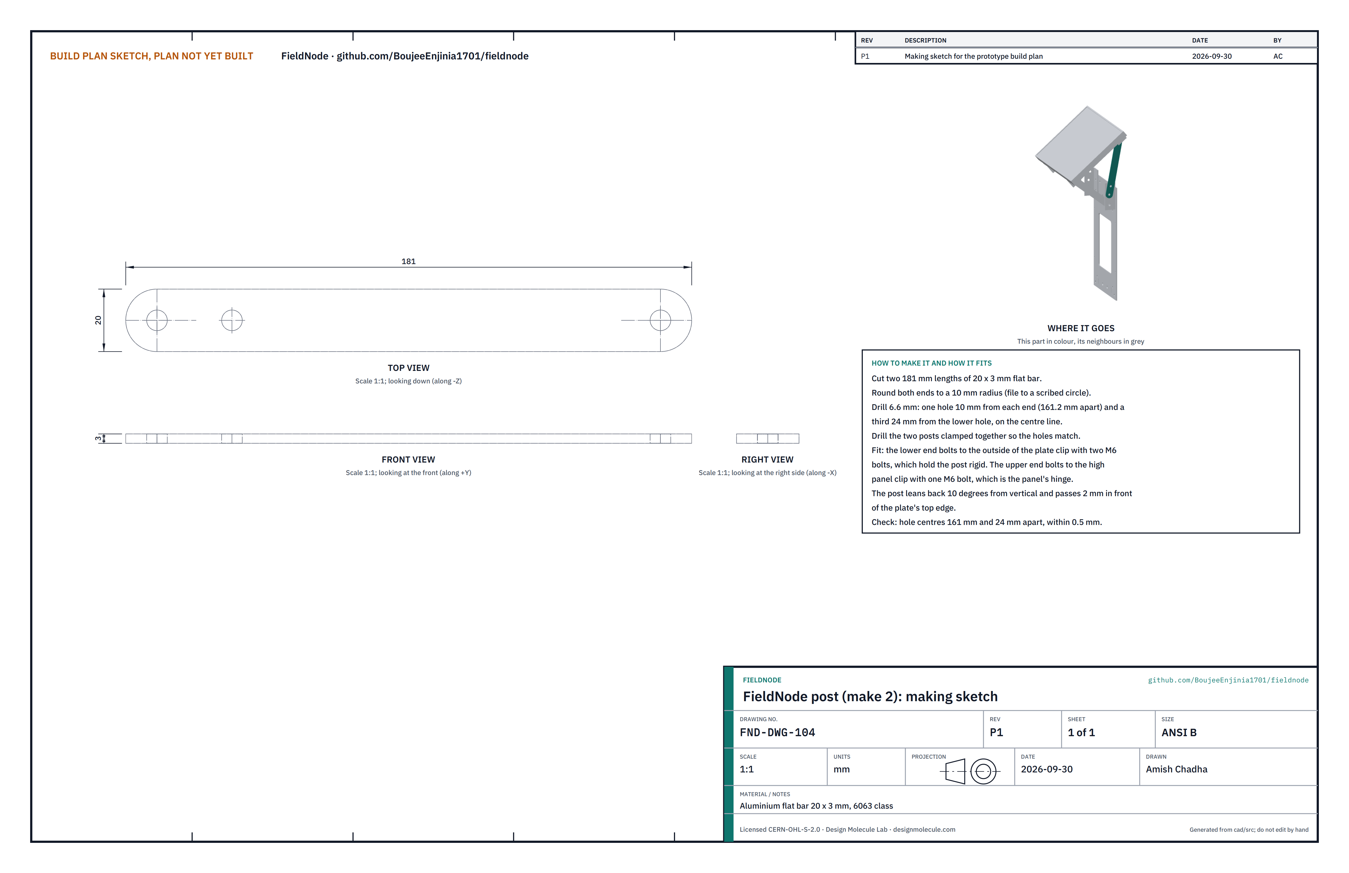
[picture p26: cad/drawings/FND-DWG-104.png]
Figure 15. Making sketch of the post


*Figure 15. Post making sketch (FND-DWG-104), drawn laid flat.*

**What it is and what it is made from.** The rear leg of each side of the bracket; the panel hinges on its top. Aluminium flat bar 20 x 3 mm, 6063 class.

**How to make it.**

1. Cut two 181 mm lengths.
2. Round both ends to a 10 mm radius: scribe a circle round each end hole centre and file to it.
3. On the centre line, drill three 6.6 mm holes: 10 from each end (161.2 apart), and one 24 from the lower hole.
4. Drill the two posts clamped together so the holes match.

**How it fits the parts next to it.** The lower end bolts to the outside of the plate clip with two M6 bolts, which hold the post rigid (Figure 14). The post leans back 10° from upright and passes 2 mm in front of the plate's top edge. The upper end bolts to the high panel clip with one M6 bolt, which is the panel's hinge (Figure 18).

**Check before moving on.** Hole centres 161.2 and 24 apart, within 0.5 mm.

### 3.7 Struts (make 2)

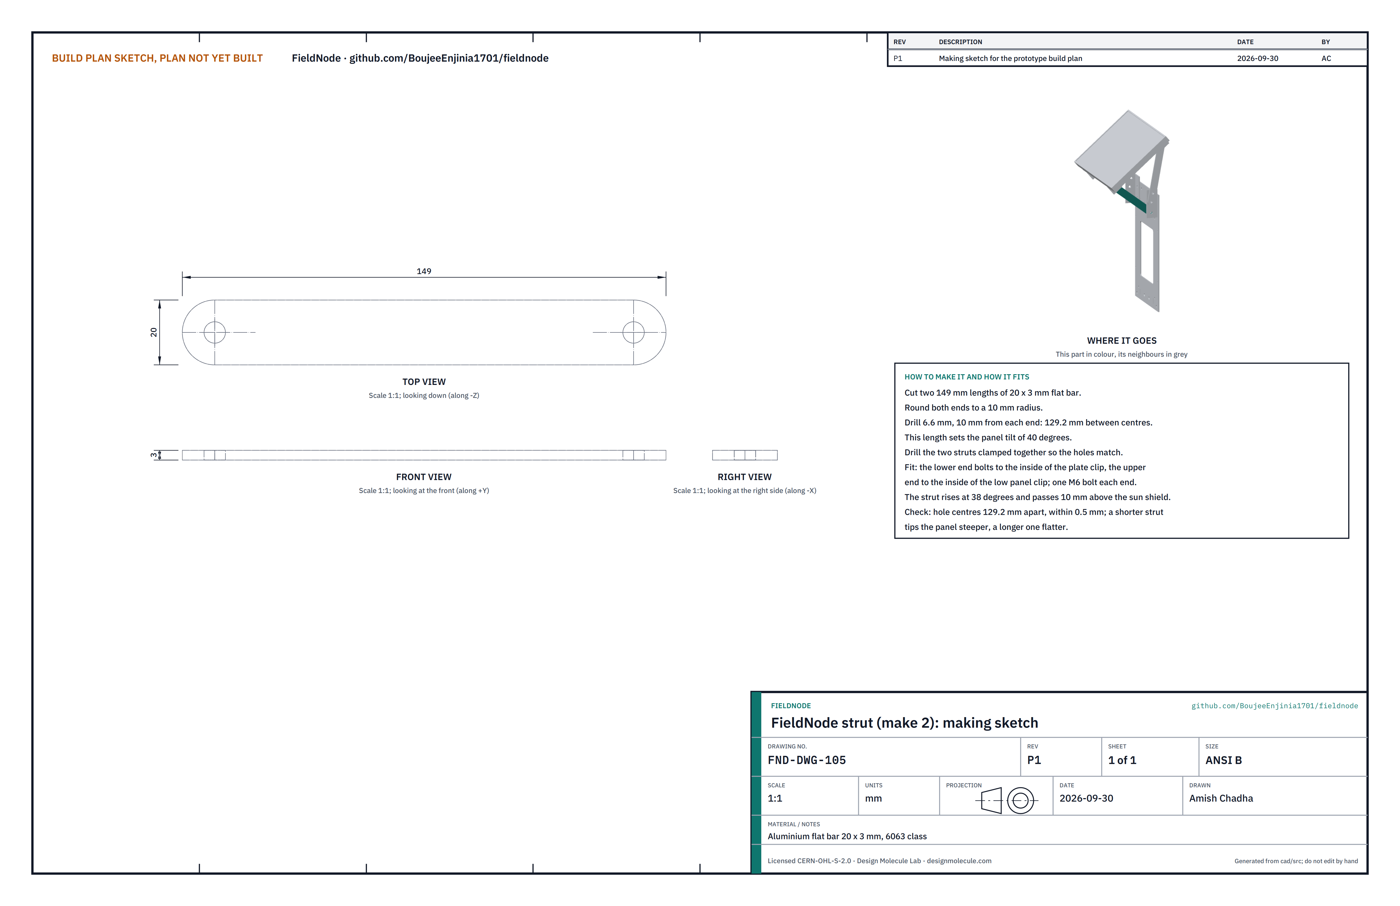
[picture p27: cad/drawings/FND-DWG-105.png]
Figure 16. Making sketch of the strut


*Figure 16. Strut making sketch (FND-DWG-105), drawn laid flat.*

**What it is and what it is made from.** The front leg of each side of the bracket; its length sets the panel's 40° tilt. Aluminium flat bar 20 x 3 mm, 6063 class.

**How to make it.**

1. Cut two 149 mm lengths and round both ends to a 10 mm radius.
2. Drill a 6.6 mm hole 10 from each end, 129.2 between centres, drilling the two struts clamped together.

**How it fits the parts next to it.** The lower end bolts to the inside of the plate clip (Figure 14) and the upper end to the inside of the low panel clip (Figure 19), one M6 bolt at each end. The strut rises at 38° and passes 10 mm above the sun shield. A shorter strut makes the panel steeper, a longer one flatter.

**Check before moving on.** Hole centres 129.2 apart, within 0.5 mm.

### 3.8 Panel clips (make 4)

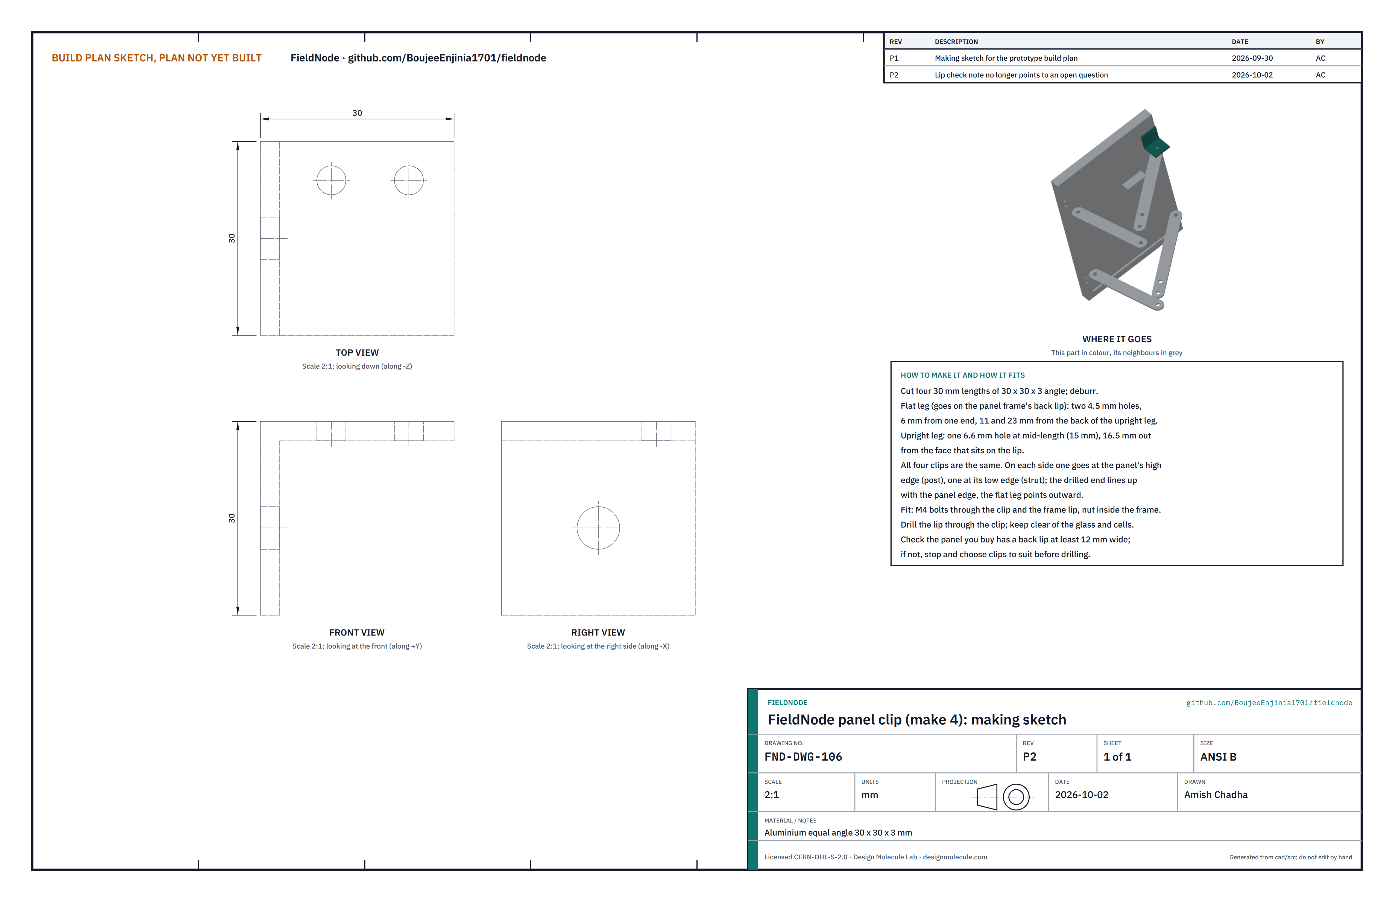
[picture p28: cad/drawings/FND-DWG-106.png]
Figure 17. Making sketch of the panel clip


*Figure 17. Panel clip making sketch (FND-DWG-106).*

**What it is and what it is made from.** A short angle bolted to the back of the panel's frame, which gives each post and strut a flat face to bolt to. Aluminium equal angle 30 x 30 x 3 mm.

**How to make it.**

1. Cut four 30 mm lengths and deburr them. All four are the same.
2. Flat leg: two 4.5 mm holes, 6 from one end (the end that will line up with the panel edge), 11 and 23 out from the back of the upright leg.
3. Upright leg: one 6.6 mm hole at mid-length (15 from the end), 16.5 out from the face that sits on the panel frame.

**How it fits the parts next to it.** On each side, one clip sits at the panel's high edge (for the post) and one at its low edge (for the strut), with the drilled end lined up with the panel edge and the flat leg pointing outward, away from the centre. The flat leg sits on the frame's back lip (the flat rim on the back of the panel frame). Measured from the panel's centre line, the inside face of the upright leg is 86 for the high clips and 80 for the low clips, so the post and the strut each sit against their clip's inside face. Drill the frame lip through the clip's holes, keeping well clear of the glass and cells, and fit two M4 bolts with the nuts inside the frame.

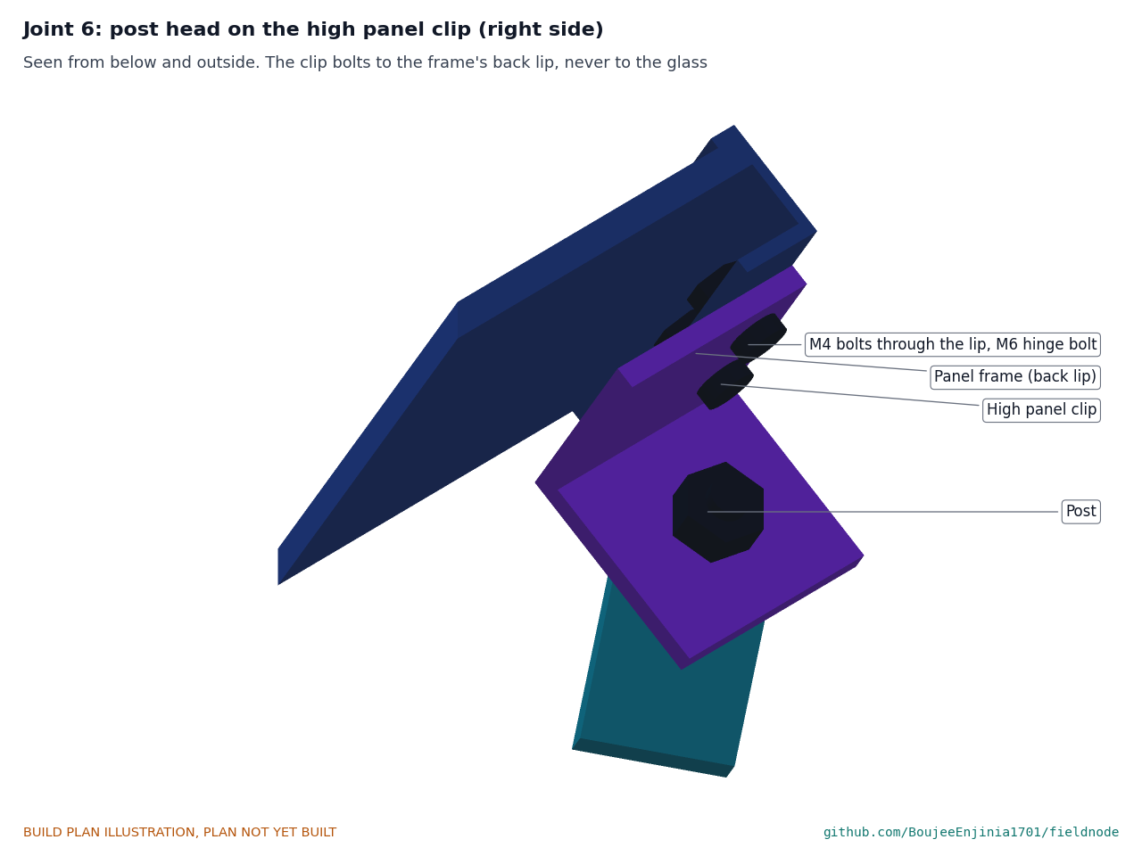
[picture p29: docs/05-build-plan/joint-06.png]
Figure 18. Joint 6: post head on the high panel clip


*Figure 18. The post head on the high panel clip, seen from below and outside.*

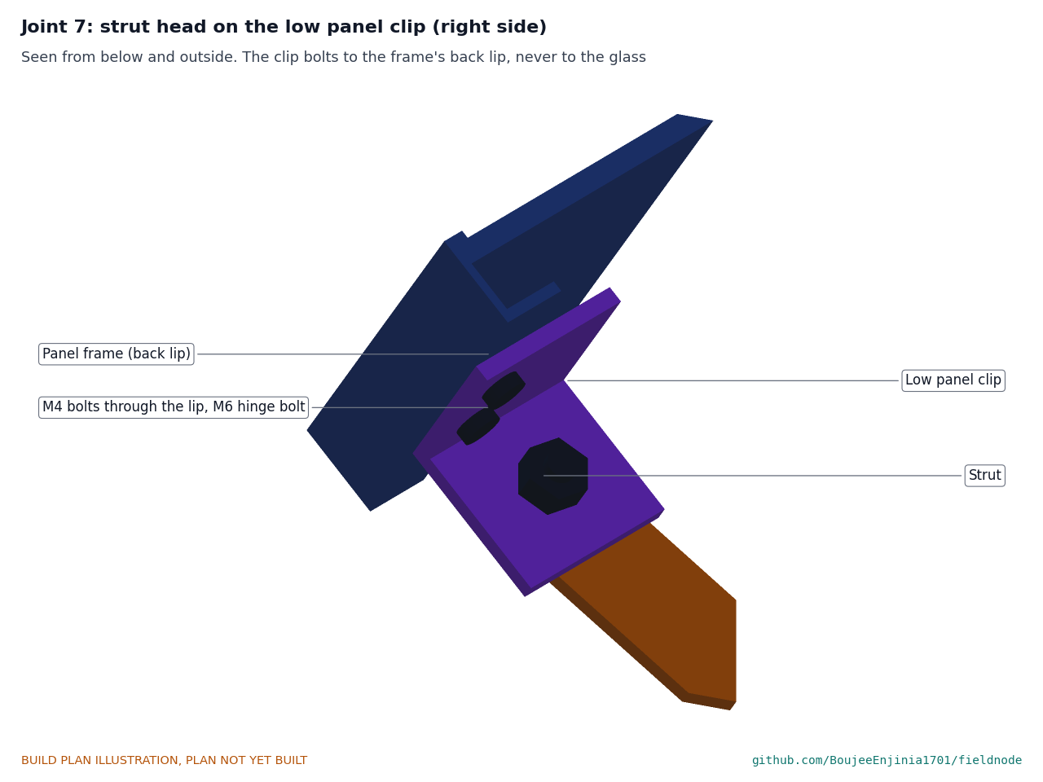
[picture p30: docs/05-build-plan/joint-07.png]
Figure 19. Joint 7: strut head on the low panel clip


*Figure 19. The strut head on the low panel clip.*

**Check before moving on.** The panel you buy must have a flat back lip at least 12 mm wide; if it does not, stop (section 8).

### 3.9 Sun shield (hot sites only)

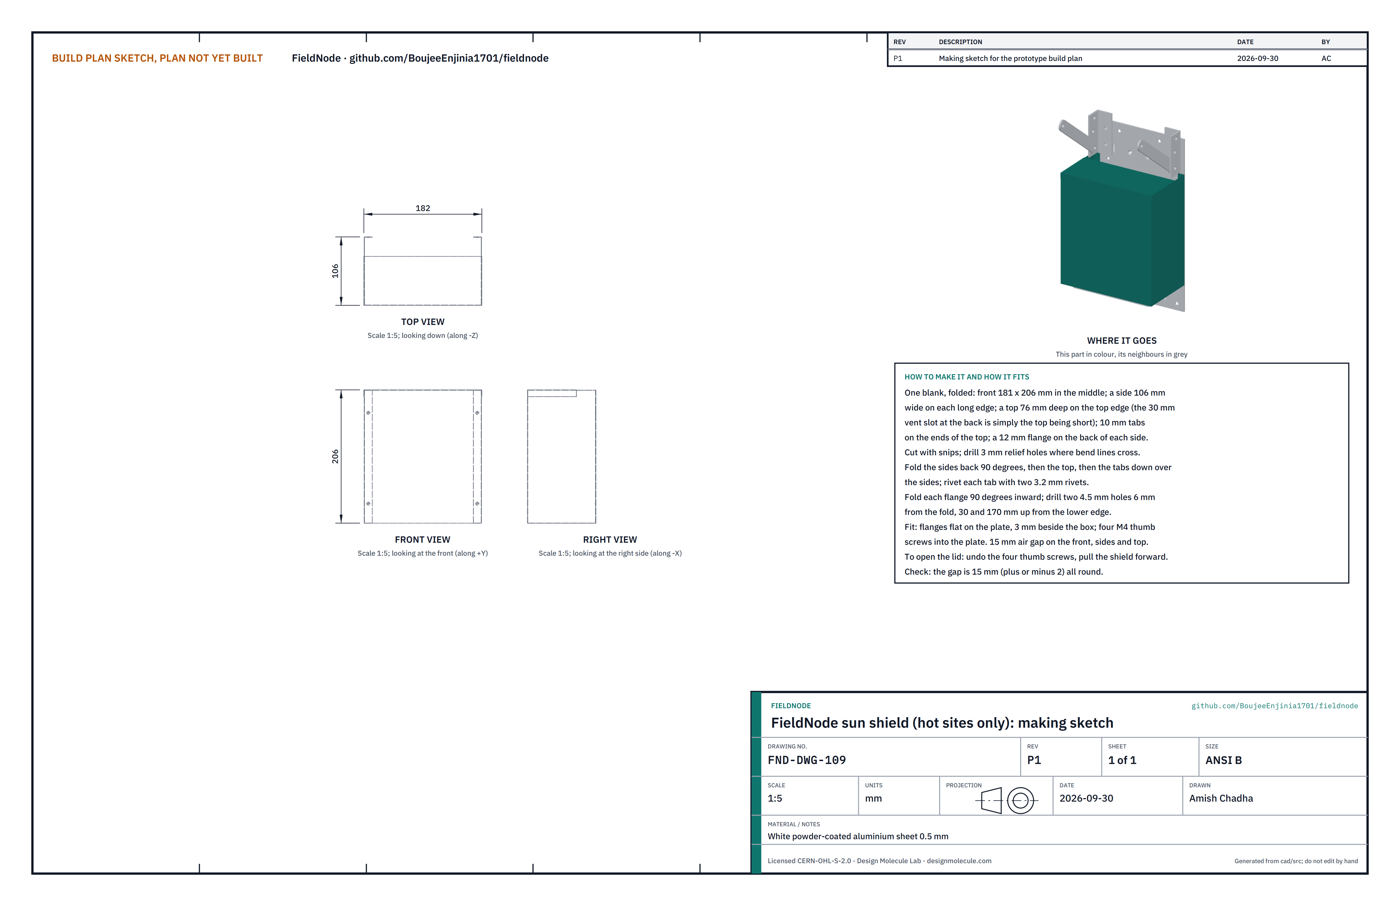
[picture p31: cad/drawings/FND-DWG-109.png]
Figure 20. Making sketch of the sun shield


*Figure 20. Sun shield making sketch (FND-DWG-109).*

**What it is and what it is made from.** A white folded sheet that shades the box on its front, sides and top with a 15 mm air gap, fitted only where the site's hottest days pass 30 °C. White powder-coated aluminium sheet 0.5 mm.

**How to make it.**

1. Mark one blank on the protective film: the front, 181 x 206, in the middle; a side 106 wide on each long edge; a top 76 deep on the top edge (the top is short at the back to leave a 30 mm vent slot); a 10 mm tab on each end of the top; and a 12 mm flange along the back edge of each side.
2. Cut with aviation snips. Drill a 3 mm relief hole wherever two fold lines cross, so the coating does not tear.
3. Fold the sides back 90°, then the top back 90°, then the tabs down over the sides. Rivet each tab to its side with two 3.2 mm rivets.
4. Fold each flange 90° inward. Drill two 4.5 mm holes in each flange, 6 from the fold, 30 and 170 up from the lower edge.
5. Peel the film.

**How it fits the parts next to it.**

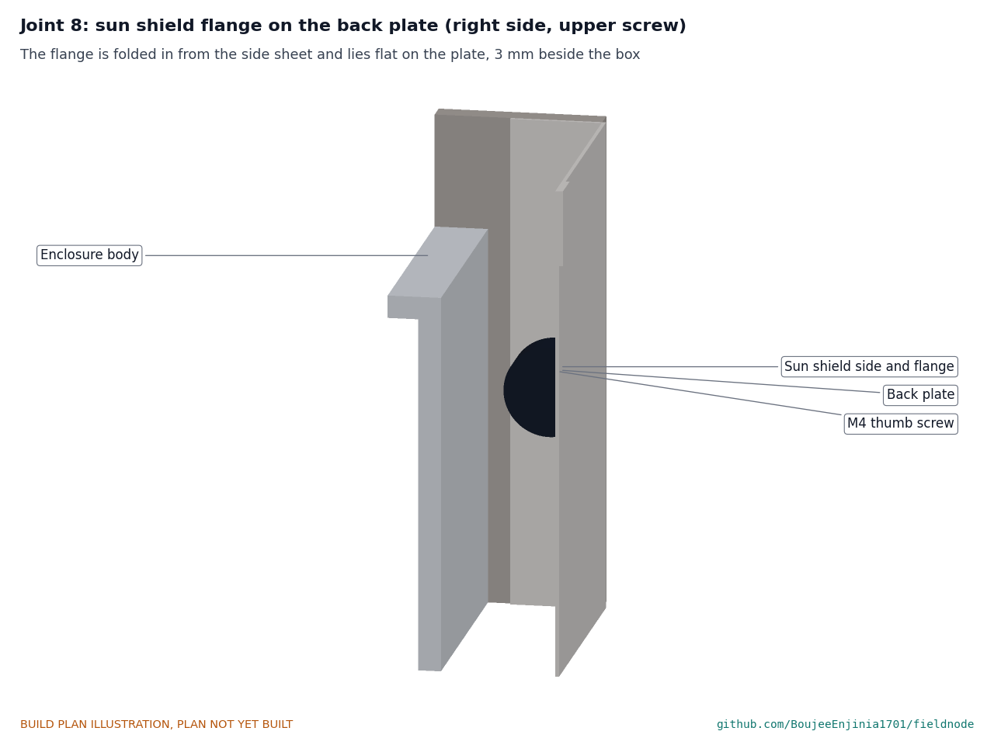
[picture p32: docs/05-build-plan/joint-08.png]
Figure 21. Joint 8: shield flange on the back plate


*Figure 21. The flange lies flat on the back plate 3 mm beside the box; an M4 thumb screw holds it.*

The flanges lie flat on the front of the back plate either side of the box, and four M4 knurled thumb screws go through them into the tapped holes in the plate. The shield stands 15 mm off the box's front, sides and top, its lower edge 10 mm above the box's bottom, open at the bottom. The struts pass over it, 10 mm clear. To open the lid, undo the four thumb screws and slide the shield forward; this adds about 2 minutes to a cell swap (about 9 minutes in all).

**Check before moving on.** On a trial fit over the box, the gap is 15 mm, give or take 2, all round.

### 3.10 Bought components

Buy to specification, not brand. Line numbers are those of the bill of materials.

- **Enclosure and lid (lines 1 and 2).** Polycarbonate, IP65 or better, UV stabilised, 150 x 90 x 200 mm outside, lid on the 150 x 200 face, four moulded bosses inside the back wall, and the maker's four-lug wall mounting kit. Drill as section 3.3.
- **Cable glands (line 3).** Two M16 x 1.5 nylon glands, IP68, for 4 to 8 mm cable, and one M16 blanking plug.
- **Solar panel (line 4).** 6 W monocrystalline, 9 V class, about 290 x 200 x 17 mm, aluminium frame with a flat back lip at least 12 mm wide, 1 m lead.
- **Cell and holder (line 6).** 32700 lithium iron phosphate cell, 3.2 V, 6 Ah, from a maker that publishes a datasheet; holder with an inline 5 A fuse, a 10 k temperature sensor and a plug-in lead.
- **Power modules with programming header (line 7) and controller (line 8).** As Table 2.
- **Antenna (line 9).** 915 MHz whip about 190 mm, about 2 dBi, with bulkhead and pigtail, for the US915 first variant; a whip for the band of the first adopting project's site replaces it only if that site is outside North America.
- **Sensor ports (line 10).** Two M12 5-pin A-coded panel sockets, IP67, with caps.
- **Band clamps (line 12).** Two 12 mm stainless worm-drive band clamps, band about 230 to 280 mm round the pole, block and plate.
- **Connector strip and fuses (line 15).** Pluggable terminal strip, 5.08 mm pitch, about 12 ways, plug and header; two resettable fuses of about 0.5 A hold.
- **Fixings (line 13).** Stainless: 10 x M6 x 16 hex bolts with nyloc nuts; 8 x M5 x 12 button-head screws with nyloc nuts; 8 x M4 x 12 pan-head screws with nuts; 4 x M4 x 12 countersunk screws; 4 x M4 x 10 screws; 4 x M4 knurled thumb screws (shield); M3 screws and 6 mm nylon standoffs; wire, ferrules, desiccant pack, cable ties.

## 4. Putting it together

In each picture the parts already fitted are grey and the part being fitted is in colour, with an arrow showing the way it goes in.

### Step 1: V-blocks onto the back plate

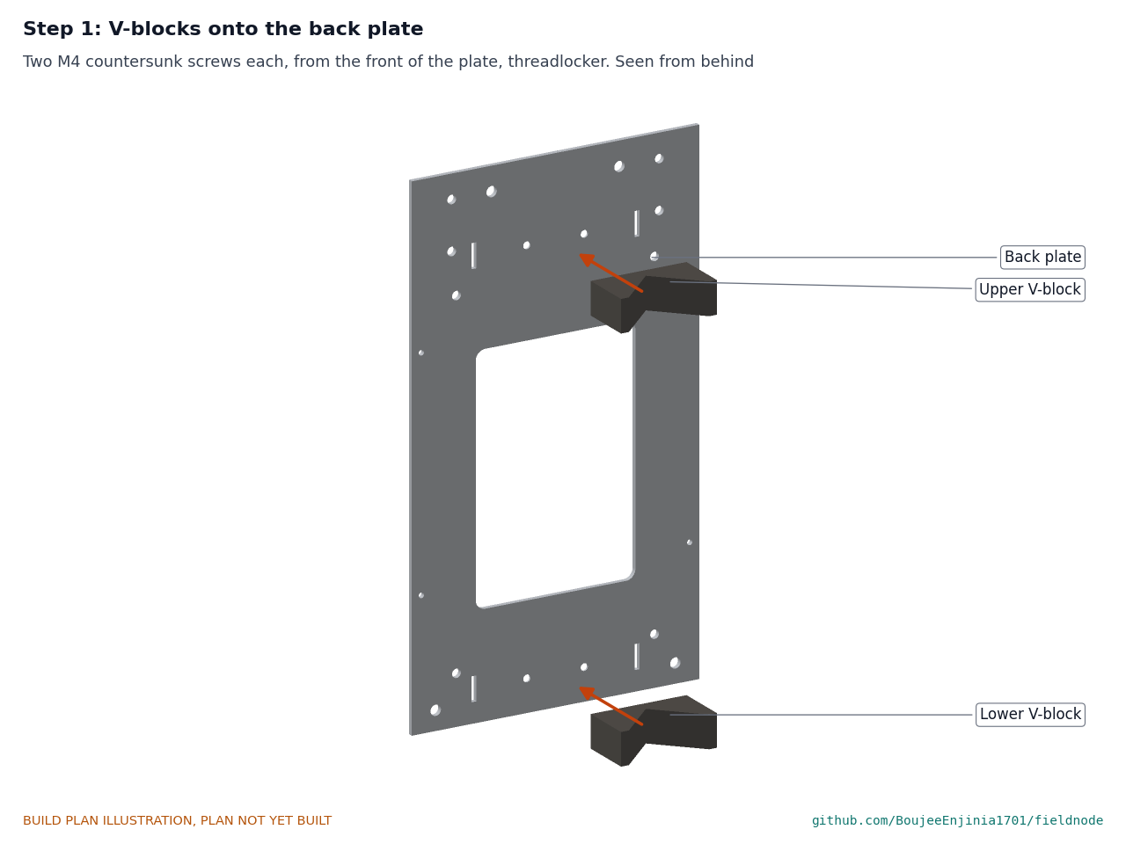
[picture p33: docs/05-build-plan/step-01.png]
Step 1


Two M4 countersunk screws per block, from the front of the plate, with medium threadlocker, snug. The V opens away from the plate.

### Step 2: glands, vent, ports and antenna into the box

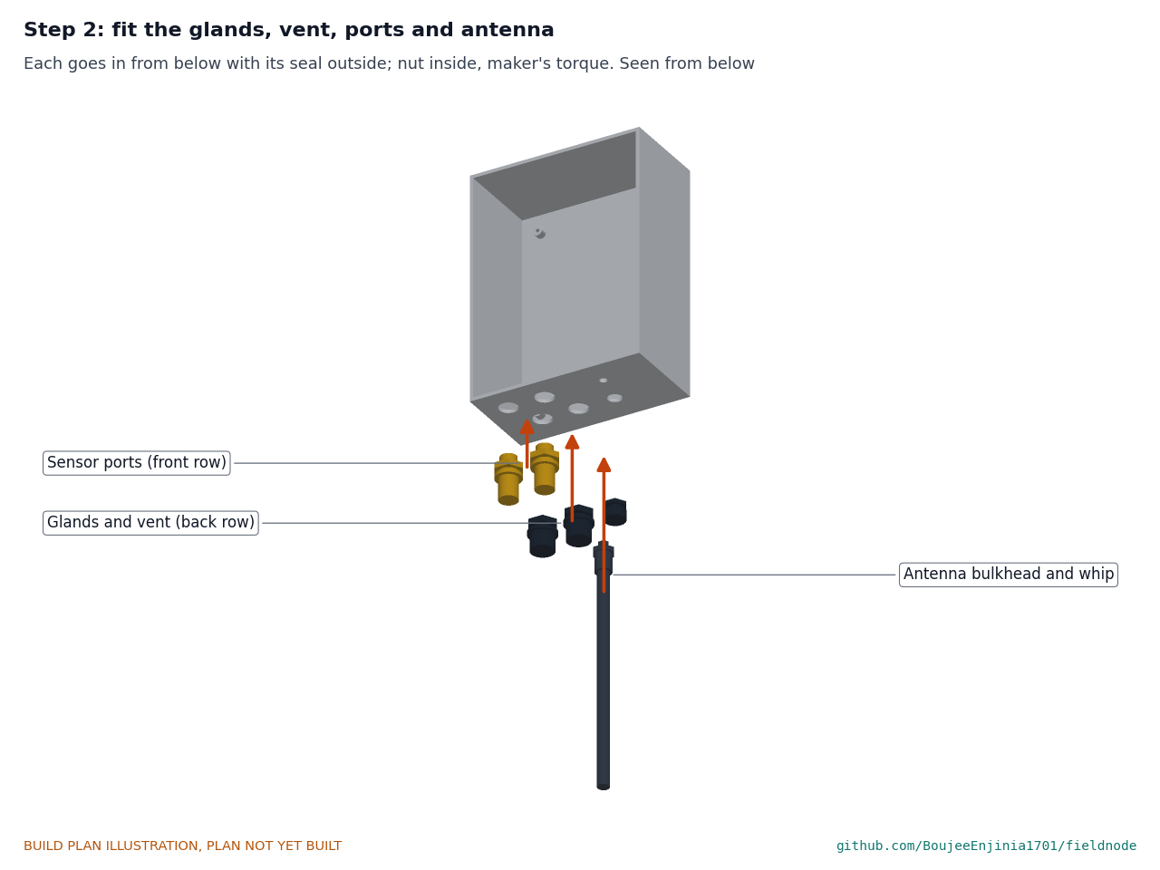
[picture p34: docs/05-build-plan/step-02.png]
Step 2


Each goes in from below with its sealing washer outside and its nut inside, tightened to the maker's torque. Put the blanking plug in gland 2 until a sensor cable is fitted.

### Step 3: box onto the back plate

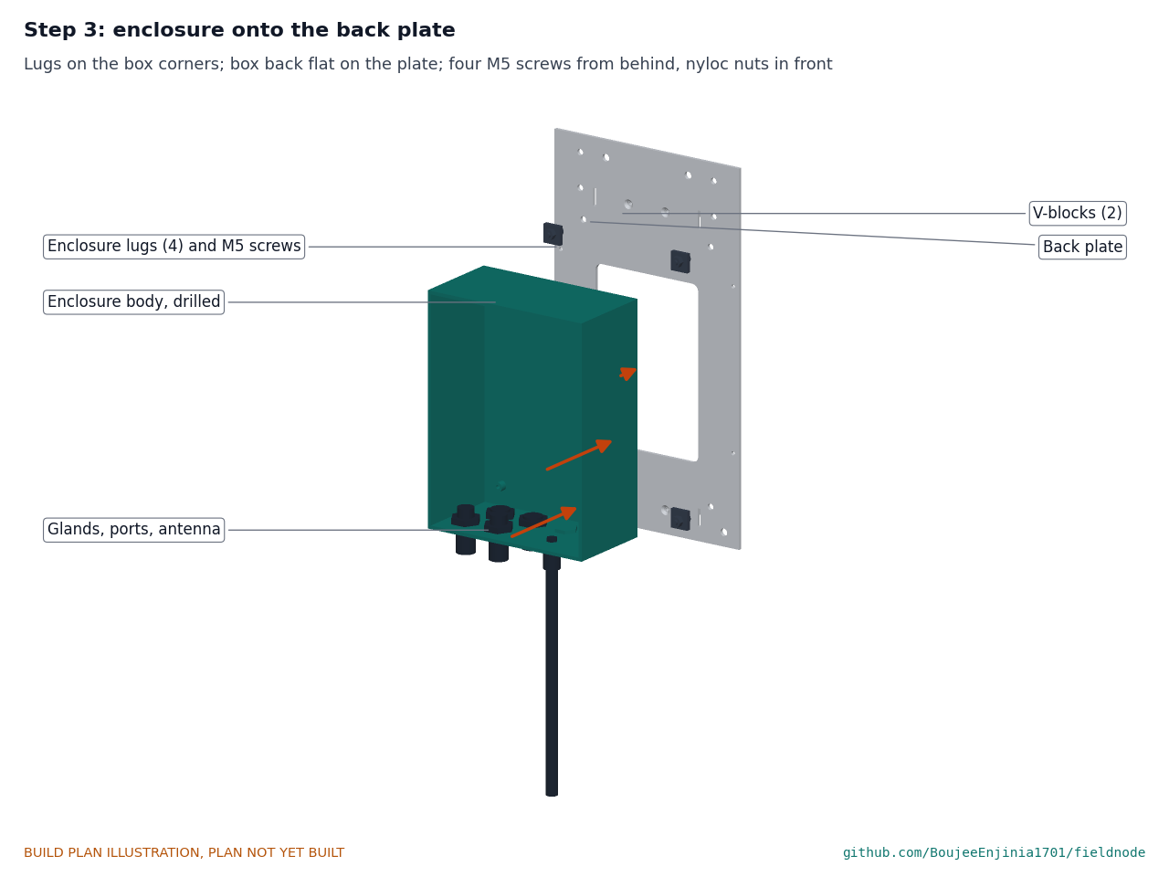
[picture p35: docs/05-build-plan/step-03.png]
Step 3


Hold the box flat on the front of the plate, centred, 40 above the plate's bottom edge. Four M5 button-head screws through the lugs from behind the plate, nyloc nuts in front, snug.

### Step 4: build the internal plate

Step 4

Fit the cell holder (no cell, fuse out), modules, programming header and connector strip on M3 screws and standoffs and wire them as Figure 12. **Hold point:** the wiring checks of section 3.4 pass before going on.

### Step 5: internal plate into the box

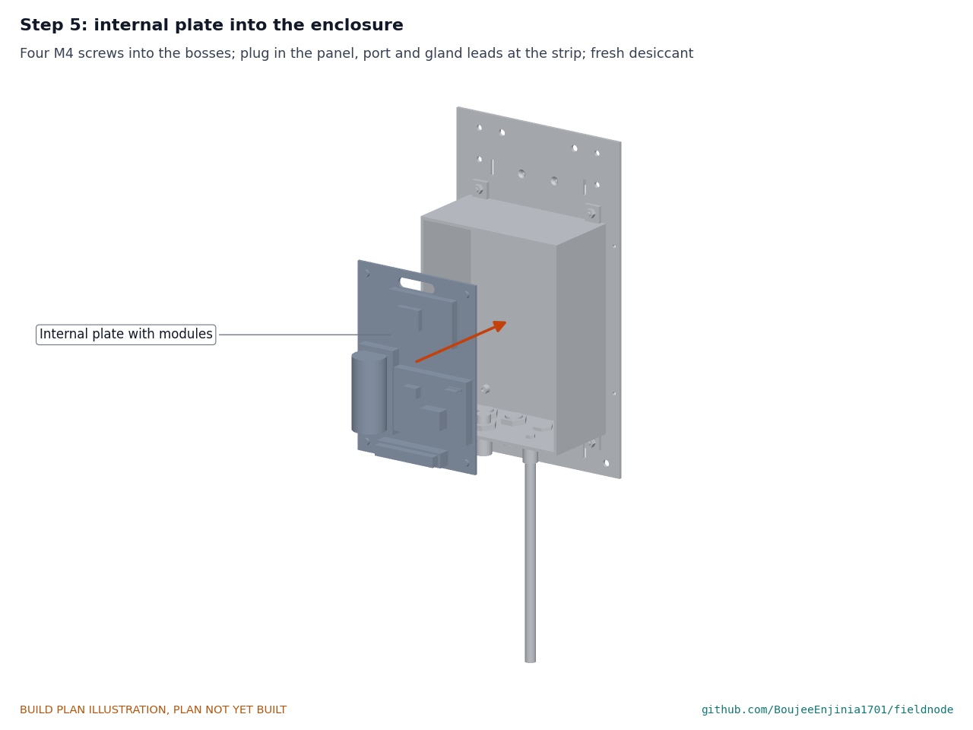
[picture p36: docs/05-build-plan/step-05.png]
Step 5


Four M4 screws into the bosses. Plug the panel lead, port leads and gland 2 lead into the connector strip and connect the radio pigtail. Add a fresh desiccant pack. **Hold point:** no wire pinched; the cell and fuse go in only at the stop points of section 6.

### Step 6: close the lid

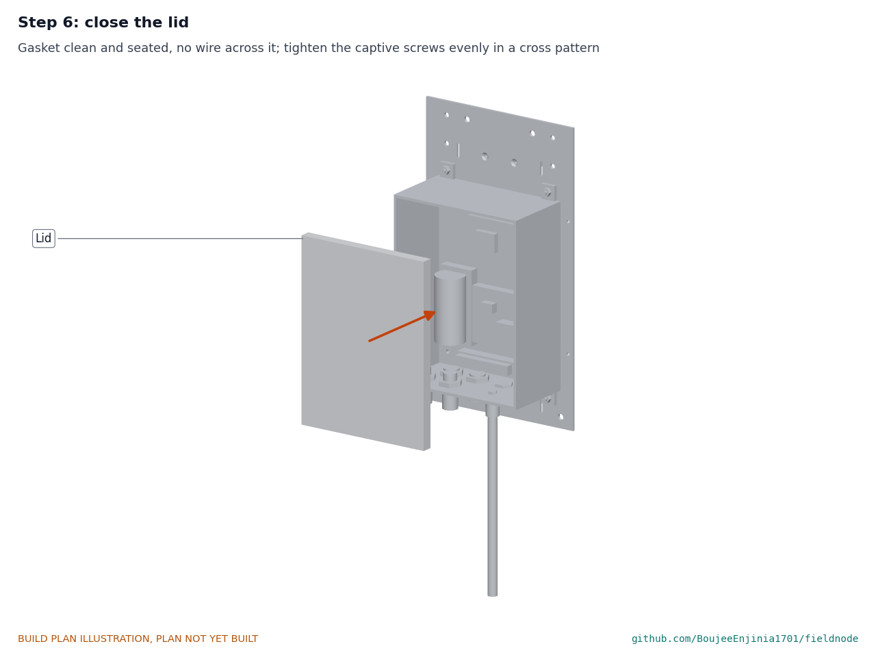
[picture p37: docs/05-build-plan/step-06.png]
Step 6


Check the gasket is clean and seated with no wire across it. Tighten the captive lid screws evenly in a cross pattern.

### Step 7: plate clips onto the back plate

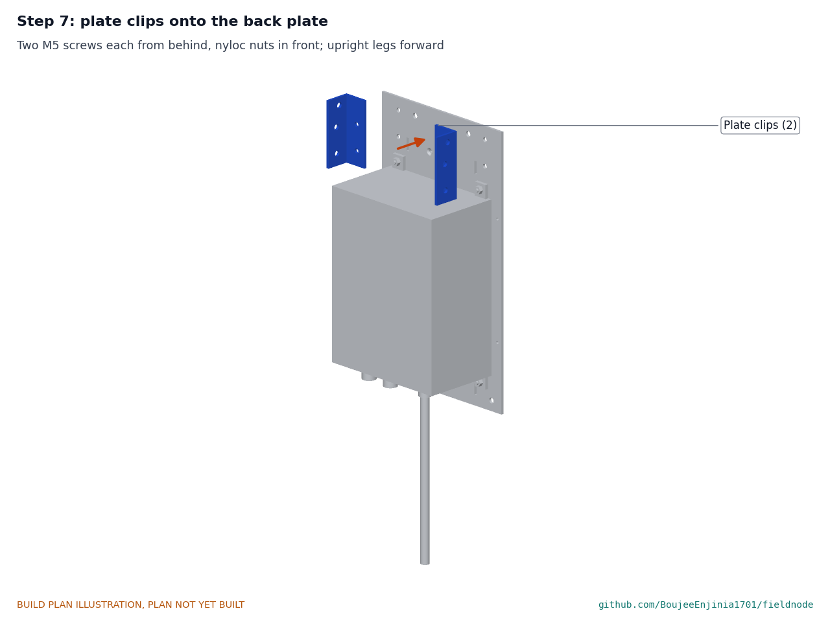
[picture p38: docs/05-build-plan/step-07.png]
Step 7


Two M5 button-head screws each from behind the plate, nyloc nuts in front, upright legs standing forward, square to the plate.

### Step 8: posts and struts onto the plate clips

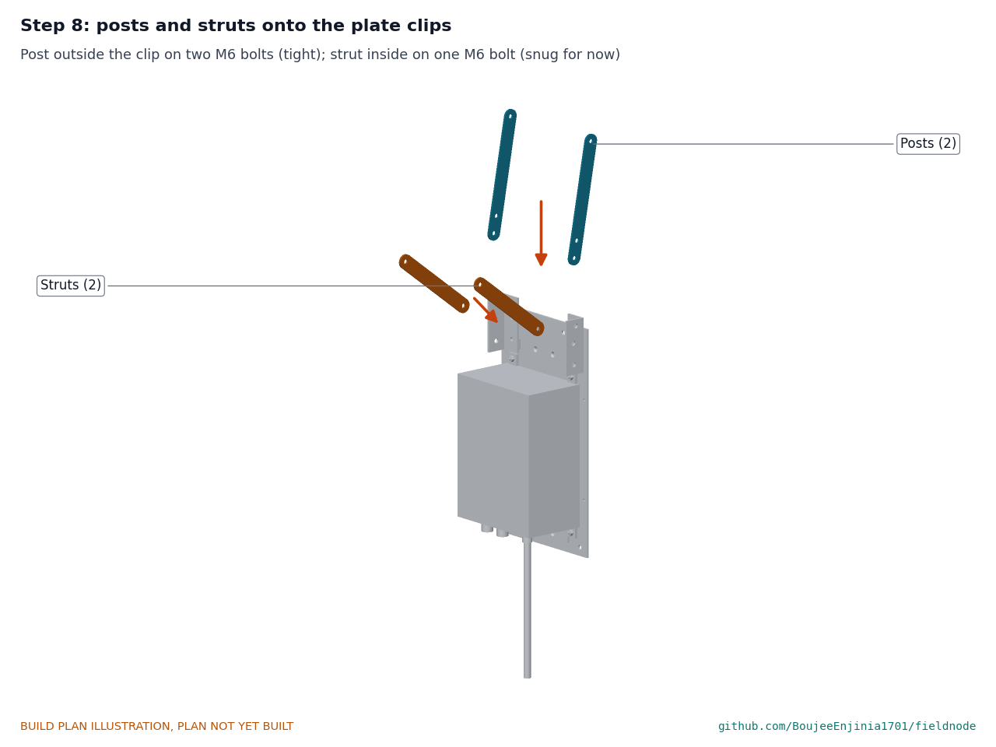
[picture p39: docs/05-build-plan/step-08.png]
Step 8


Each post against the outside of its clip on two M6 bolts, tight. Each strut against the inside of its clip on one M6 bolt, snug so it can still swing.

### Step 9: panel clips onto the panel

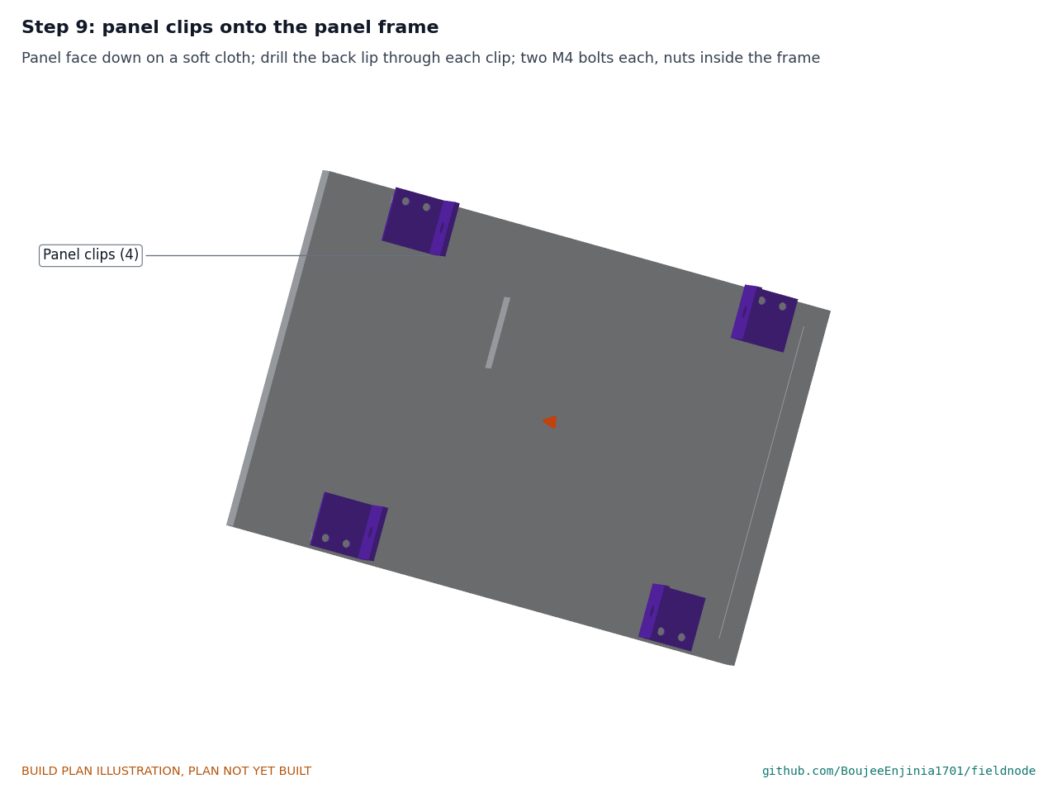
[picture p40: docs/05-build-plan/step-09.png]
Step 9


Lay the panel face down on a soft cloth. Place each clip as section 3.8, drill the frame lip through the clip, and fit two M4 bolts with the nuts inside the frame.

### Step 10: panel onto the posts and struts

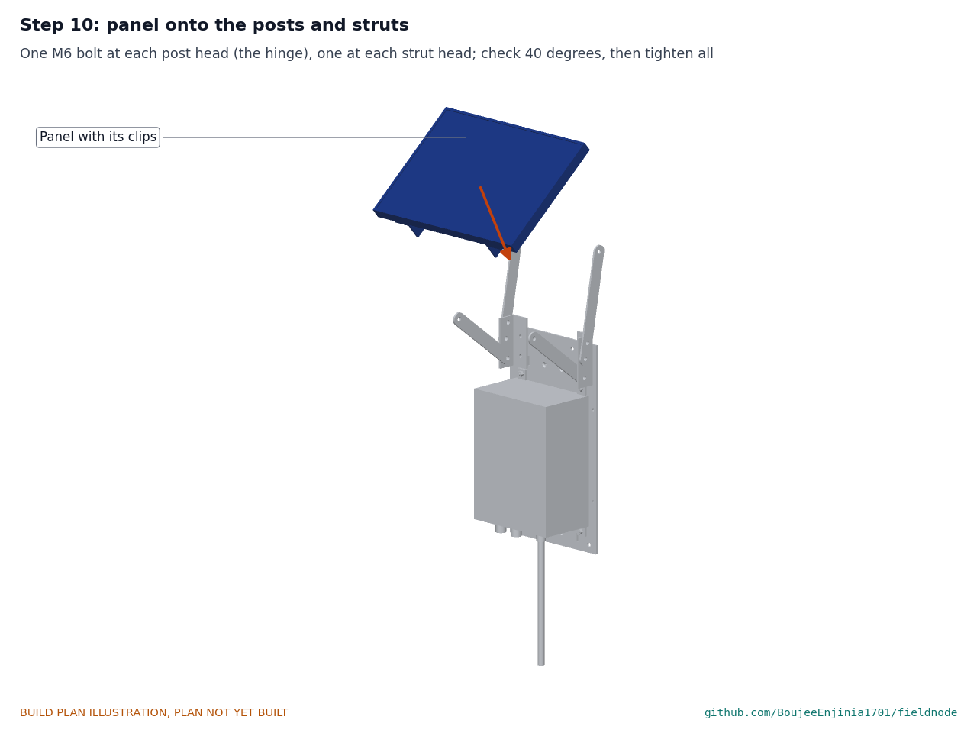
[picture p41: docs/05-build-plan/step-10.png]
Step 10


With a helper holding the panel, slide the high clips down over the outside of the post heads (they should go on with light hand pressure; if tight, dress the clip leg with a file) and fit one M6 bolt at each post head. Swing each strut up to its low clip and fit one M6 bolt. Check the tilt is 40° with an angle finder, then tighten every bracket bolt.

### Step 11: sun shield (hot sites only)

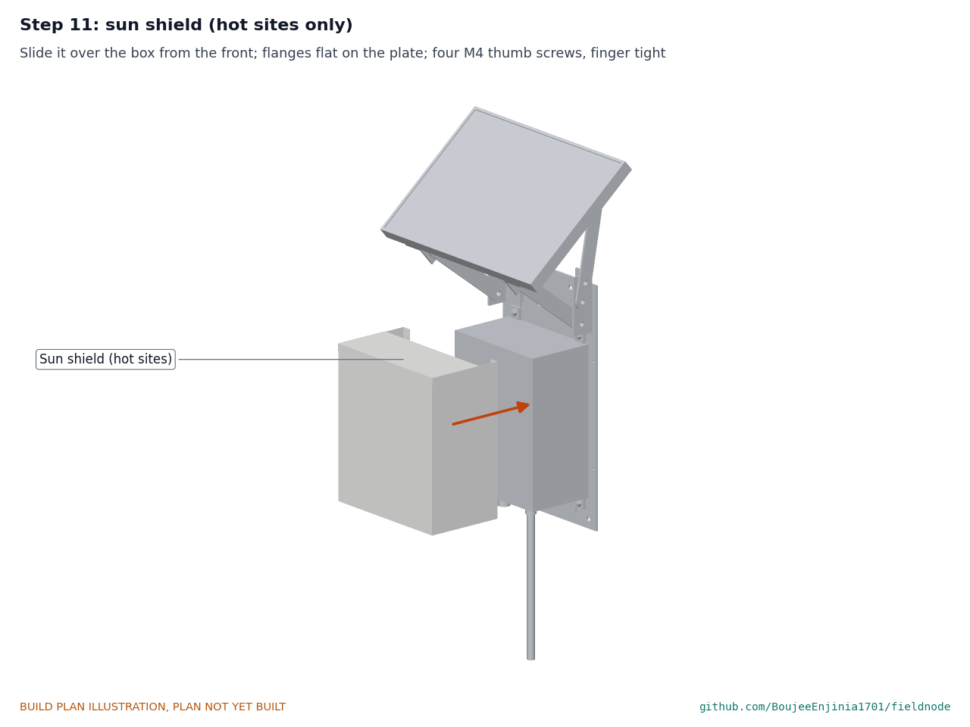
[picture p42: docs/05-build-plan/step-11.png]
Step 11


Slide the shield over the box from the front until its flanges lie on the plate, and fit the four thumb screws finger tight.

### Step 12: onto the pole

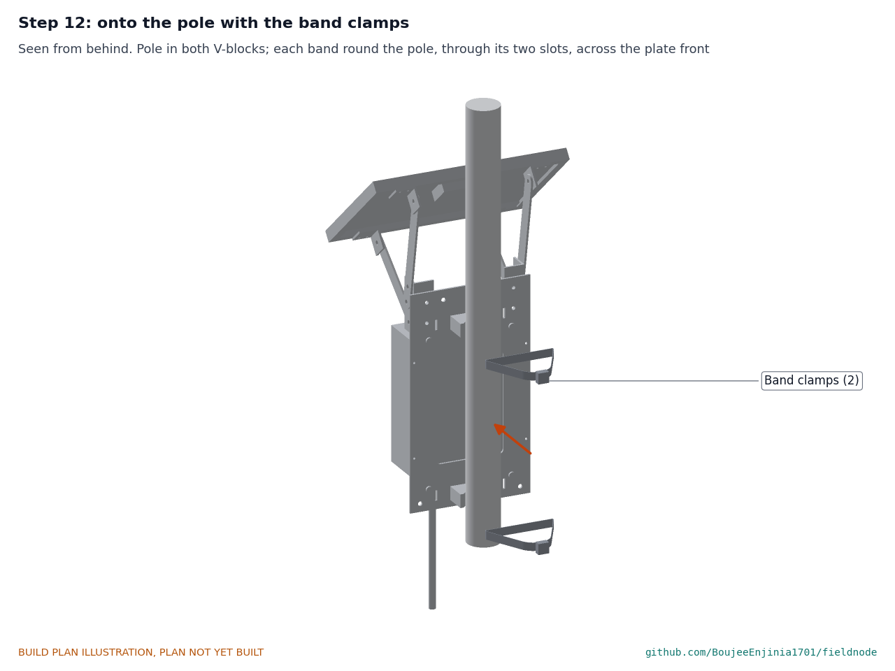
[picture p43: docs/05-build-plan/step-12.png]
Step 12


Seen from behind. Hold the node with the pole in both V-blocks. Pass each band round the pole, through its two slots in the plate and across the front of the plate (the lower band below the box, the upper band above it), with the worm-drive housing behind the pole. Tighten both bands to the band maker's torque and record it. **Hold point:** safety stop S7 in section 6.

## 5. First checks

These are the checks a TRL 4 test report would record; this plan only lists them. Requirement numbers are those of FND-REQ-001.

*Table 3. First checks.*

| Check | Requirement | How | Pass when |
| --- | --- | --- | --- |
| Penetrations seated and sealed | R1 | Look at each washer under a lamp; gland caps tight on a 4 to 8 mm test cable | Every washer evenly squeezed; no gaps (the spray test comes later) |
| Charge voltage | R4, R5 | Bench supply at 9 V in place of the panel, current limit 1 A; measure the charger output with the cell out, as its datasheet describes | 3.60 V, give or take 0.05 V |
| Cold and hot charge stop | R4 | Cell fitted; replace the temperature sensor with a resistor equal to its value at -1 °C, then at 46 °C | No charge current in either case (under 10 mA) |
| Normal charge | R4, R5 | Sensor reconnected, cell fitted, bench supply at 9 V, 1 A limit | Current flows; charging ends at 3.6 V |
| Over-discharge cut-off | R4 | Bench supply in place of the cell at 3.2 V, lowered slowly | The protection board cuts the output at its datasheet value |
| Sensor supplies | R7, R11 | Switch each port supply on and off from the controller; measure at the M12 pin | Within 5 % of 5 or 12 V when on; 0 V when off; a short on the pin trips the resettable fuse |
| Firmware load by cable | R15, R17 | Lid open, cell fitted, nothing unplugged: plug a 3.3 V serial cable onto the programming header and load the firmware with the region set to US915 | The firmware loads without lifting the plate out or soldering; the node then joins a US915 network |
| Internal plate lifts out | R15 | Unplug the connector strip and pigtail, undo four screws | The plate and everything on it comes out in one piece |
| Pole range | R12 | Seat the mount on 40, 48 and 60 mm tubes | Both V-blocks touch the tube on both faces; each band closes with adjustment to spare |
| Band torque | R13 | Torque screwdriver on each band | The maker's torque is reached without the band slipping; value recorded |
| Panel tilt and bracket | R5, R13 | Angle finder on the panel; push on the panel corners by hand | 40° give or take 1°; nothing moves at any joint |
| Mass | R14 | Weigh the node without and with the shield | 2.5 kg or less without the shield (2.45 kg estimated); about 2.61 kg with it |
| Cell swap | R15 | Time a swap with a screwdriver, with and without the shield | 10 minutes or less both ways |

## 6. Safety stops

Stop at each point. Carry on only when everything listed is true.

- **S1. Before the cell comes into the workshop.** Cell voltage about 2.8 to 3.4 V; no swelling, dents or leaks; a datasheet from its maker. Fuse out of the holder. A charging spot ready on a non-combustible surface (ceramic tile or steel tray) with a fire extinguisher for electrical fires within reach.
- **S2. Before the fuse goes in.** With the cell out, the pack terminals and every supply read open to ground. The holder's polarity matches the protection board, checked with a meter, not by wire colour.
- **S3. Before any charging source is connected.** The charge voltage is set and measured at 3.6 V; the panel input polarity is checked at the charger; the charger's maximum input is above the panel's open-circuit voltage at -20 °C.
- **S4. Before the cell is allowed to charge.** Both charge-stop checks of section 5 pass with the substitute resistors. Then the temperature sensor is reconnected and taped to the cell, and the bench supply limit is 1 A or less.
- **S5. First charge.** Attended the whole time, lid open, on the charging spot; cell temperature checked every 15 minutes. Stop if the cell passes 45 °C or 3.65 V. Never bypass the charge stop to gain energy.
- **S6. Before the radio transmits.** The antenna is connected and matches the region set in the firmware (915 MHz for the US915 first variant). Transmitting without an antenna can damage the radio.
- **S7. Before the node goes on the pole stub.** Every bracket bolt tight with nyloc nuts, panel glass whole, sharp edges deburred, both bands through their slots. The stub is clamped to a bench or stand that cannot tip under about 2.6 kg.
- **S8. Before any outdoor installation (outside this plan).** Work from a stable ladder with a second person; never on a pole that carries power lines unless the utility allows it; check the site pole can carry about 81 N of wind load about 2 m up.

## 7. Tools, skills and workspace

**Tools.** Hacksaw with a 24 teeth per inch blade (or a bandsaw); bench vice with soft jaws; bench drill or a drill in a stand; drills 2.5 to 12 mm; step drill to 20 mm; countersink; M4 tap and tap drill; jigsaw with a metal blade; flat and half-round files; deburring tool; scriber, engineer's square, 45° square, steel rule and calipers; digital angle finder; hand sheet folder (or two lengths of hardwood angle clamped in the vice) for 0.5 mm sheet 210 mm long; aviation snips; hand rivet tool; 3D printer with an enclosure and a bed of at least 130 x 180 mm that prints ASA; soldering iron; ferrule crimper and wire strippers; multimeter; 3.3 V USB-to-serial cable with a six-way 2.54 mm socket, for loading firmware; bench power supply with an adjustable current limit (0 to 15 V, 0 to 2 A); torque screwdriver covering about 1 to 6 N·m; scale to 5 kg; stopwatch.

**Skills.** No certified trade is needed. Basic metalwork (marking out, sawing, drilling, filing, tapping, folding thin sheet), through-hole soldering and crimping, safe use of a bench power supply and care with lithium cells. All circuits are extra-low voltage: 3.6 V at the cell, 12 V at most on a sensor supply, under about 15 V from the panel. The bench supply must be a certified, undamaged unit; no mains wiring is part of this build.

**Workspace.** A bench about 1.2 x 0.6 m; a metalwork corner kept apart from the electronics so chips stay off the modules; a ventilated place for the printer; the charging spot of S1.

**Personal protective equipment.** Safety glasses for cutting, drilling and soldering; cut-resistant gloves for bar, sheet and the panel; hearing protection when sawing; no gloves near a turning drill.

## 8. Where the numbers come from

- Model and constructability checks: `cad/src/model.py` (`python cad/src/model.py --check`); STEP and STL exports in `cad/step/` and `cad/stl/`.
- Pictures: `cad/src/build_plan_media.py`, using `.kit/build_views.py`; written to `docs/05-build-plan/` and `cad/drawings/FND-DWG-101` to `FND-DWG-109`.
- General arrangement: `cad/drawings/FND-DWG-001.pdf`, Rev P4.
- Calculations: `docs/04-calcs/01-sizing.md` (FND-CAL-001 v0.6) and `docs/04-calcs/sizing.py`; masses [F1], [F1b], cell swap [E2], [E2b], bracket [D5], V-blocks [D6], [D6b].
- Bill of materials: `bom/bom.csv`.
- Decisions: `docs/decisions/0003-design-for-construction.md` (FND-DDR-003), with FND-DDR-001 and FND-DDR-002.
- Requirements: `docs/03-requirements.md` (FND-REQ-001 v0.8).

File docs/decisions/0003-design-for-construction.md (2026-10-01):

---
doc_id: FND-DDR-003
title: FieldNode design for construction
project: FieldNode
doc_type: Design decision record
version: "0.3"
status: Draft
date: '2026-10-01'
author: Amish Chadha
license: CERN-OHL-S-2.0
revisions:
- version: "0.1"
  date: '2026-09-30'
  author: Amish Chadha
  change: Changes that make the concept physically buildable, with the reason for each; made under Amish's 2026-09-30 instruction and open for his review
- version: "0.2"
  date: '2026-09-30'
  author: Amish Chadha
  change: Accepted by Amish, including the recommendations for A1 to A4
- version: "0.3"
  date: '2026-10-01'
  author: Amish Chadha
  change: Budget treated as a value-engineering target
---

# 0003: Design for construction

- **Date:** 2026-09-30
- **Status:** accepted. Amish, 2026-09-30: "i accept your recommended changes on design that are currently being sent across for my approval". This covers every change below and the recommendations in Table 3 (A1 to A4), which are now decided as recommended.

## Context

On 2026-09-30 Amish asked for the build plan to show how each component is made and how it fits the next, with pictures, and wrote: "If you are realising that the design cannot be built as per concept, fix the design assumptions to match and be physically feasible as you draw the illustrations." The concept model of FND-DDR-002 showed what FieldNode does but had parts that could not be made or fixed as drawn. An earlier planning pass listed six of them (P1 to P6 below); checking the model with build123d found three more (P7 to P9).

The changes keep what the node does: the same enclosure, panel size, tilt, position and hood, the same cell, electronics, radio, ports, mounting height, pole range and sun shield. Nothing here changes the pitch or the safety case. Every change is in `cad/src/model.py`, which now also runs 97 constructability checks (`python cad/src/model.py --check`): parts that must touch do touch, and parts that must not touch are apart by at least the stated clearance. All 97 pass.

## Decision

*Table 1. Changes made to the model, the BOM and the calculations.*

| # | Problem in the concept | Change made | Why this way |
| --- | --- | --- | --- |
| P1 | V-blocks 50 x 21.85 x 30 mm with a round seat. A true 90° V at the 42 mm pole stand-off touches the 48.3 mm pole 24.9 mm from the plate, deeper than the block, so the pole would bear on the V's edges, not its faces. | V-blocks 60 wide x 33 deep x 20 tall, with a true 90° V 50.3 mm wide at the front face and its point 7.8 mm from the plate. The design pole touches both faces 24.9 mm from the plate, 8 mm inside the front face. Each block is held by two M4 countersunk screws from the front of the plate into tapped holes. | Keeps the pole where the concept put it (so the enclosure, panel and all loads are unchanged). 60 mm width leaves 4.9 mm lands beside the V; 20 mm height clears the 12 mm band and saves mass. Poles of 40 to 71 mm still seat on both faces. |
| P2 | The two M16 glands 26 mm apart with 24 mm flanges: 2 mm between them, no room for a spanner or the inside locknuts. | Penetrations in two rows on the bottom face, 27 and 55 mm from the back face. Back row: gland 1 (panel lead) at 40 mm left, gland 2 at 8 mm left, vent at 24 mm right. Front row: port A at 54 mm left, port B at 22 mm left, antenna at 30 mm right. | Every outside flange is at least 8 mm from the next and every inside nut about 6 mm, enough for a spanner or deep socket. The back row sits under the internal plate's connector strip with 4 mm to spare. |
| P3 | Vent overlapped the antenna bulkhead by about 5 mm. | Vent moved to the back row (24 mm right); antenna in the front row (30 mm right), 10.6 mm apart at the flanges. | Solved by the same two-row layout. |
| P4 | Bracket flat bars stood edge-on to the plate and the panel; their feet cut 11 mm into the plate; the panel fixing points at 80 mm each side of centre had no frame behind them. Also (found in checking) a post and a strut pinned one bolt at each end form a four-bar linkage, so the panel could swing. | Each side now has: a plate clip (30 x 30 x 3 mm angle, 77 mm long) with one leg bolted flat to the plate by two M5 screws and one leg standing forward; a post (20 x 3 mm flat bar) bolted flat to the outside of that leg by two M6 bolts, so it is rigid; a strut (20 x 3 mm flat bar) bolted flat to the inside of the leg by one M6 bolt; and two panel clips (30 x 30 x 3 mm angle, 30 mm long) bolted through the panel frame's back lip by two M4 bolts each, one at the high edge for the post (the hinge) and one at the low edge for the strut. | Every joint is face to face and bolted. The panel frame's back lip is the only part of a framed panel that can carry a bolt, so the clips go there. Two bolts at the post foot make the side frame a rigid triangle. One angle size and one bar size keep buying simple. The strut's hole spacing (129.2 mm) sets the 40° tilt, as BOM line 5 said. |
| P5 | Sun shield had no fixing, and its front covers the lid, so it had to come off to open the box. | A 12 mm flange folded inward at the back edge of each side sheet lies flat on the back plate, 3 mm beside the box; four M4 knurled thumb screws go through the flanges into tapped holes in the plate. The shield slides off forward after four screws. | No tools, nothing left loose on the node. The 15 mm air gap, open bottom and 30 mm top slot are unchanged, so the thermal result stands. The cell swap on a hot-climate node rises from about 7 to about 9 min [E2b]; R15 (10 min) is still met. |
| P6 | No fuses on the switched sensor rails, and no plug-in connectors, although the internal plate is meant to lift out as one unit. | New BOM line 15: a pluggable terminal strip (plug and socket) along the bottom edge of the internal plate for the panel lead, both ports and gland 2, and a 0.5 A resettable fuse on each port rail. The strip is in the model. | A shorted sensor cable can no longer draw from the cell through a boost converter up to the 5 A cell fuse, and the plate unplugs in one move. |
| P7 | The enclosure had no fixing to the back plate. | The enclosure maker's kit of four external mounting lugs, one at each back corner, above and below the box, each held by one M5 button-head screw from behind the plate with a nyloc nut in front. | The box back stays sealed (no screw through it) and sits flat on the plate; all four screws can be reached with the lid shut. |
| P8 | The internal plate floated against the back wall with no fixing. | It sits on the four moulded bosses found inside most stock enclosures, 6 mm off the back wall, held by four M4 screws. | Uses what the bought box already has; the 6 mm gap leaves room for wires behind the modules. |
| P9 | The band clamps were drawn as rings round the pole, with no path through the plate. | Each band passes round the back of the pole, through two 3 x 15 mm slots in the plate (51 mm each side of centre, clear of the V-blocks by 2 mm) and across the plate's front face, where the lower band runs below the box and the upper band above it. | This is how a band clamp holds a plate to a pole; the worm-drive housing sits behind the pole where a screwdriver reaches it. |

*Table 2. Knock-on changes.*

| Item | Change | Reason |
| --- | --- | --- |
| Mass | Back plate gets a 100 x 150 mm window behind the enclosure (6 mm corner radius); post and strut bar is 20 x 3 mm instead of 25 x 3 mm. Base node 2.45 kg (was 2.41 kg), 0.05 kg under R14's 2.5 kg [F1]; hot-climate node 2.61 kg [F1b]. | The clips, bolts, connector strip and fuses added about 0.2 kg. The window is hidden behind the box and away from every fixing; the narrower bar still has a buckling factor of 30 [D5]. |
| Cost | BOM lines 1, 5, 13 and 14 repriced and line 15 added: base node $139.00, hot-climate node $148.00, both within the unchanged $150 value-engineering target (`budget_usd`), $11.00 and $2.00 under [F2], [F3]. | Parts added for construction. |
| Drawing | FND-DWG-001 Rev P3; making sketches FND-DWG-101 to 109 added. | Follows the model. |
| Documents | FND-CAL-001 v0.3, FND-PRC-001 v0.5, FND-REQ-001 v0.5: mass, cost, bracket, pole range and cell swap figures updated. No requirement changed status. | Follows the model. |
| Thermal and wind | Unchanged: the enclosure, panel and shield keep their size and position, and the lugs are not counted as heat capacity. Clamp pull 59 N (63 N with the shield) against 2,000 N [D3]. | |

*Table 3. Proposed, awaiting Amish.*

| # | Question | Options | Recommendation |
| --- | --- | --- | --- |
| A1 | The shield now comes off by hand, which lowers tamper resistance at a node mounted at 1.75 m partly to deter tampering (FND-PRC-001, choice 8). | (a) knurled thumb screws, as modelled; (b) M4 pan-head screws needing a screwdriver, which R15 allows. | (a) for the prototype; decide for deployments after the first site visit. |
| A2 | Wall mounting. The plate's back now carries screw heads (2.8 mm) and the V-blocks (33 mm), so it cannot lie flat on a wall as the concept says. | (a) for a wall, unscrew the V-blocks and fit 5 mm spacers on the four wall screws; (b) a separate wall plate. | (a): no new part, and the spacers also let water drain. |
| A3 | The R14 mass margin is now 0.05 kg on catalogue masses. | (a) accept, weigh the prototype at TRL 4; (b) look for more mass now (for example a 2.5 mm back plate). | (a). |
| A4 | Whether the first prototype includes the sun shield (carried over from the earlier planning pass; the hot-climate node is now $148.00, within the value-engineering target). | (a) build it with the shield; (b) base node first. | (a), since the shield factor is the assumption most in need of a test. |

## Consequences

- `design_state: constructable` in `project.yaml`. The build plan FND-BLD-001 shows every component and step in pictures generated from the model (`cad/src/build_plan_media.py`).
- Requirement status is unchanged: none not met, 2 at risk (R2, R6), 10 met on paper, 5 met by design, 1 not verifiable at TRL 3 (FND-CAL-001 v0.3).
- The photoreal renders (`media/render-*.png`) and the appearance model `cad/src/product_model.py` still show the concept bracket, V-blocks and penetrations; they need updating on Amish's Mac, where Blender is.
- The enclosure part is chosen at TRL 4; its boss spacing and lug kit must be checked then, and the internal plate's four holes moved to suit.

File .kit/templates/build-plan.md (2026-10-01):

---
doc_id: PRJ-BLD-001
title: Project prototype build plan
project: Project name
doc_type: Build plan
version: "0.1"
status: Draft
date: YYYY-MM-DD
author: Amish Chadha
license: CERN-OHL-S-2.0
revisions:
  - version: "0.1"
    date: YYYY-MM-DD
    author: Amish Chadha
    change: First build plan; design made constructable
---

# Project prototype build plan

**Plan, not yet built.** How to build the first proof-of-concept prototype, component by component. Building and testing to it is TRL 4 work. Decisions still to be made are kept in the design decisions register (`docs/06-design-decisions.md`), not here.

## 1. What you are building

Every component, pulled apart and numbered in build order

One short paragraph: what the prototype is, how many components, which are made and which are bought, and the main ways they are made.

## 2. What changed to make it buildable

| Component | The concept had | The buildable design has | Why |
| --- | --- | --- | --- |

## 3. Making the components

### 3.1 Component name

Making sketch

**What it is and what it is made from.**

**How to make it.**

1. Mark out ...
2. Cut ...

**How it fits the parts next to it.**

Close-up of the joint

**Check before moving on.**

## 4. Putting it together

### Step 1: ...

Step 1

## 5. First checks

| Check | Requirement | How | Pass when |
| --- | --- | --- | --- |

## 6. Safety stops

## 7. Tools, skills and workspace

## 8. Where the numbers come from

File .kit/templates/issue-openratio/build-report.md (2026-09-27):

---
name: Build report
about: Tell us what happened when you built, printed or tested part of this design
title: "Build report: "
labels: build-report
---

This is a research and educational prototype, not a medical device. It is a TRL 3 concept and is not released for fabrication. If you build any part of it, you do so at your own risk. Reports help everyone.

**What you built** (part, sub-assembly or test)

**Materials, tools and settings**

**What worked**

**What did not work, with photos or measurements if you have them**

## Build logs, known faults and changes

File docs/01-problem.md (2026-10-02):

---
doc_id: FND-PRB-001
title: FieldNode problem statement
project: FieldNode
doc_type: Problem statement
version: "0.5"
status: Draft
date: '2026-10-02'
author: Amish Chadha
license: CERN-OHL-S-2.0
revisions:
- version: "0.1"
  date: '2026-09-25'
  author: Amish Chadha
  change: Initial scaffold
- version: "0.2"
  date: '2026-09-25'
  author: Amish Chadha
  change: Populate to TRL 2 (problem, users, context, constraints, prior work, open questions)
- version: "0.3"
  date: '2026-09-25'
  author: Amish Chadha
  change: TRL 3 update; open questions aligned with FND-DDR-001 and the thermal findings of FND-CAL-001
- version: "0.4"
  date: '2026-09-25'
  author: Amish Chadha
  change: Recommendations accepted by Amish (DDR-002)
- version: "0.5"
  date: '2026-10-02'
  author: Amish Chadha
  change: "Pilot band and pinout decisions of 2026-10-02 (FND-DEC-001)"
---

# FieldNode problem statement

Outdoor sensing projects rarely fail because of the sensor. They fail because the box leaks, the battery goes flat in a cloudy week, the charger cooks in the sun or refuses to charge in the cold, or the radio link drops. Every project in the Design Molecule lab that measures something outdoors has been about to solve these same problems again, on its own, with a new enclosure and a new charger.

## The problem

Monitoring networks for weather, water, air and ground movement are thin exactly where hazards are highest. The World Meteorological Organization notes that Germany has more stations meeting the Global Basic Observing Network standard than the whole of Africa ([WMO](https://wmo.int/media/news/closing-gaps-observing-network)). UNEP found that 37 % of countries do not legally require air quality monitoring ([UNEP, 2021](https://www.unep.org/news-and-stories/press-release/one-three-countries-world-lack-any-legally-mandated-standards)). Low-cost sensor nodes are one way to fill such gaps, but only if they keep working for months without a visit.

The field record shows where they stop working. The SensorScope team at EPFL reported water ingress and corrosion, battery charging failures below freezing, crystal drift in the cold, radio interference and miscalibrated sensors across their deployments ([Barrenetxea et al., SenSys 2008](https://gsfr.github.io/pdf/sensys2008.pdf)). None of these are sensor problems; all of them are platform problems. A lab that solves them once, in the open, can reuse the answer across many projects.

Open loggers exist. The EnviroDIY Mayfly is an Arduino-compatible logger released under the CERN Open Hardware License with solar charging support ([EnviroDIY](https://www.envirodiy.org/mayfly/); [GitHub](https://github.com/EnviroDIY/EnviroDIY_Mayfly_Logger)). The Things Network provides an open community LoRaWAN network ([TTN](https://www.thethingsnetwork.org/docs/lorawan/duty-cycle/)). What is missing for this lab is a complete, documented node: enclosure, solar and battery sizing, mounting, a standard sensor port and a LoRa radio, specified together as one reference design that each sensing project plugs into.

## Users and context

| User | Need | Context |
| --- | --- | --- |
| Lab project teams (WaterWatch, FloodGauge, SlopeWatch, WellSense, AirStreet, NoiseMap, HeatMap Node, CurbCount, BridgePulse, LoadZone and others) | A tested base so they design only the sensor and its firmware | Prototypes and pilots at outdoor sites |
| Community groups, schools and NGOs | A node they can build, mount and repair with hand tools | Villages, farms, catchments, school grounds |
| Municipal and utility technicians | A node that mounts on a pole or wall in minutes and reports for a season without a visit | Streets, drains, pump houses, bridges |
| Researchers | An inspectable, calibratable platform whose power and data paths are documented | Field studies; calibration against CalRig before and after deployment |
| Network operators | Nodes that stay inside regional radio rules and fair-use limits | TwinKit gateways, The Things Network or a private LoRaWAN server |

## Operating environment

- Outdoors, pole or wall mounted at about 1.8 to 2.5 m above ground, in full sun or partial shade.
- Ambient -20 to +45 °C (-4 to +113 °F), rain, dust, insects and UV; coastal salt air at some sites.
- Worst-month solar resource as low as about 2 peak sun hours per day (monsoon or high-latitude winter). This is the design assumption in FND-CAL-001; site data are still to be checked for each pilot.
- Hot, sunny seasons matter as much as dark ones: FND-CAL-001 shows that at 45 °C ambient the cell sits above its 45 °C charge limit for most of a clear day unless the enclosure is shaded, which is why hot-climate sites get a sun shield.
- No mains power and no on-site Wi-Fi; a LoRaWAN gateway within a few kilometers, or none (store and forward).

## Constraints

- Garage-buildable prototype, $150 USD or less in parts for the FieldNode core (enclosure, power, radio, panel and mounting; sensors and gateway excluded), using off-the-shelf modules, a stock enclosure and hand tools.
- Open design: hardware under CERN-OHL-S-2.0, firmware under MIT; no dependency on a closed cloud service.
- Must comply with regional radio rules (for example the 1 % duty cycle sub-bands of EU868) and should fit The Things Network fair-use policy of 30 s uplink airtime per node per day ([TTN](https://www.thethingsnetwork.org/docs/lorawan/duty-cycle/)).
- Lithium chemistry must be safe when unattended outdoors for months.
- Where a project states a privacy rule (counts or levels only, no images or audio leaving the device), the node must not weaken it.

## Out of scope

- The sensors themselves; each project owns its sensor and calibration.
- The gateway and data platform (see TwinKit).
- Cellular or satellite backhaul in the first version (kept as an open question).
- Mains-powered or high-power payloads such as cameras or pumps.

## Co-design and deployment partner

- [ ] Identify the first two lab projects to adopt FieldNode and their pilot sites.
- [ ] Get sign-off from HeatMap Node and the next adopting project on the proposed standard pinout (FND-DEC-001, decided 2026-10-02).
- [ ] Find a site host (school, utility or municipality) for a first season outdoors.

## Open questions

- Which lab projects adopt the node first, and in which region? The radio band is decided (Amish, 2026-10-02, FND-DEC-001): US915 is the default first variant, switching to the band of the first adopting project's site if it is outside North America.
- Is a single common node realistic for both low-power sensors (water level, tilt) and higher-power ones (particulate fans, microphones)? FND-CAL-001 finds that every sibling load quoted so far fits a 100 mW allowance except CurbCount (about 300 mW), which would need more storage and the 10 W panel variant kept as a later option (FND-DDR-001, D4).
- A cellular (LTE-M or NB-IoT) variant for sites with no gateway is kept as a later variant (FND-DDR-001, D1), decided by Amish on 2026-09-25.
- Hot-climate sun shield: decided by Amish on 2026-09-25 (FND-DDR-002). The shield is fitted only where the site's design maximum exceeds 30 °C; the threshold rests on an assumed shield factor that a test must confirm.

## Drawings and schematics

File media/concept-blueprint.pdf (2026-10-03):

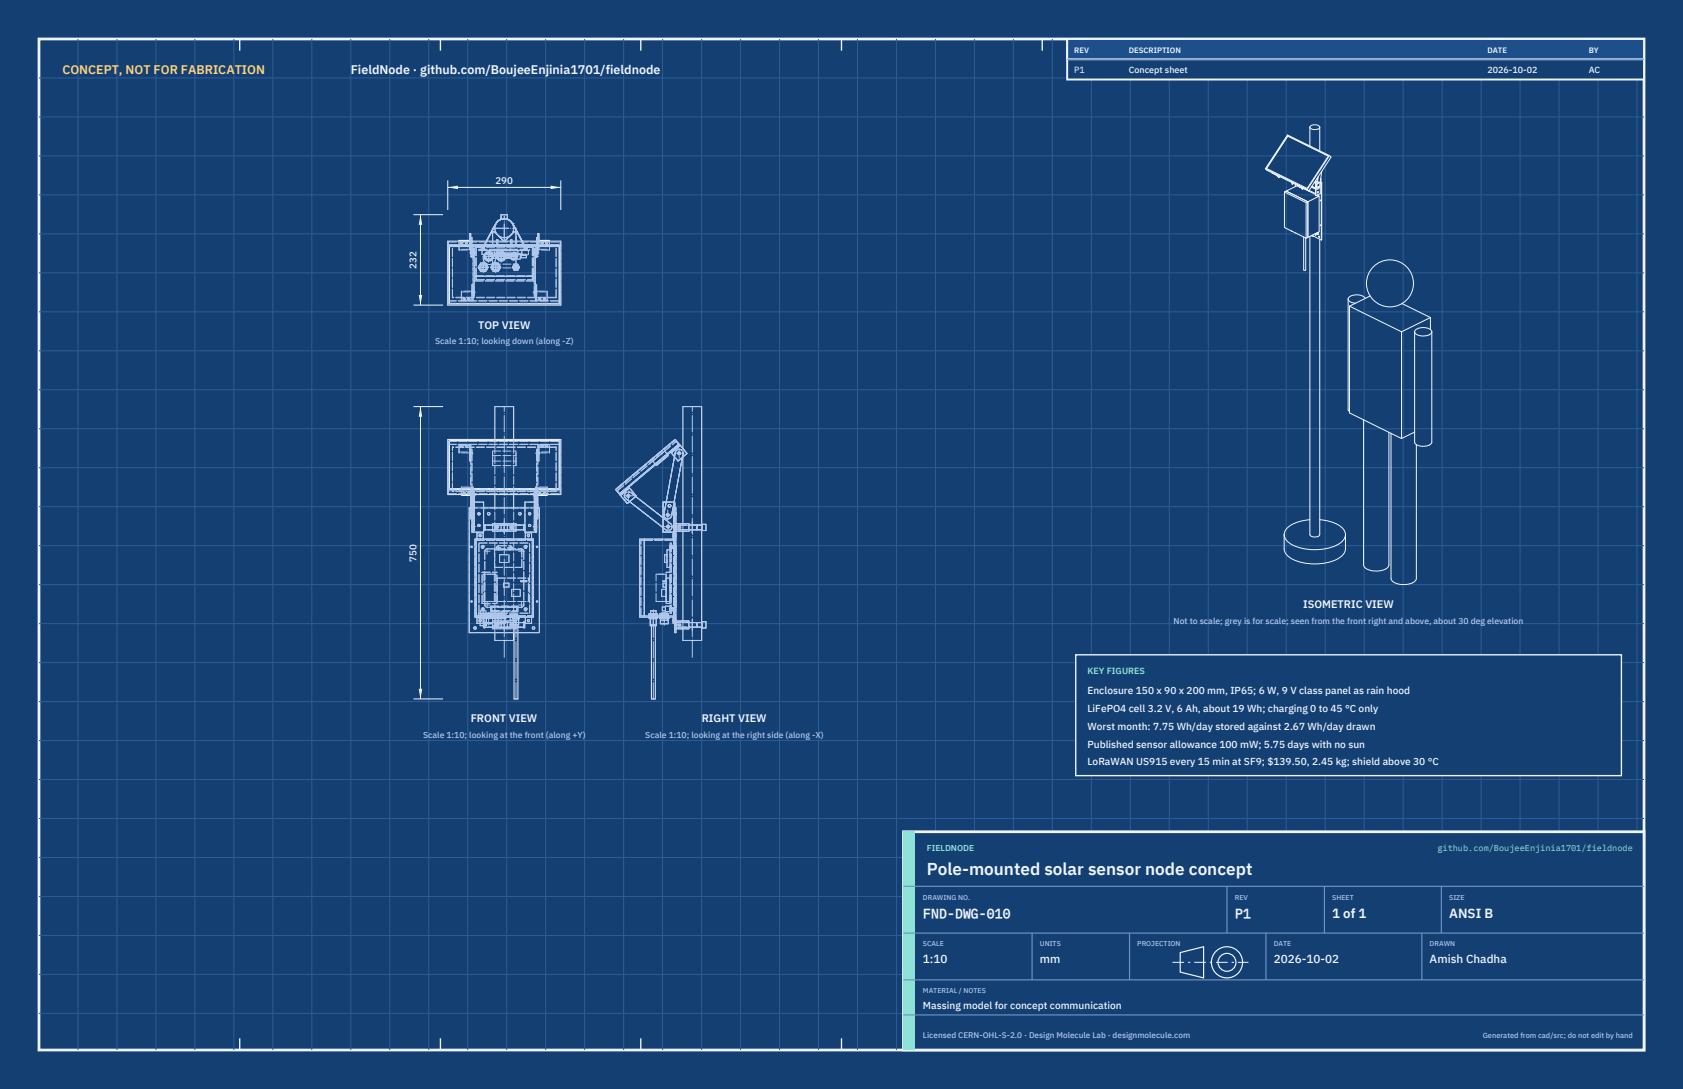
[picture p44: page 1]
CONCEPT, NOT FOR FABRICATION; FieldNode · github.com/BoujeeEnjinia1701/fieldnode; FRONT VIEW; TOP VIEW; RIGHT VIEW; ISOMETRIC VIEW; REV; DESCRIPTION; DATE; Concept sheet; FIELDNODE; github.com/BoujeeEnjinia1701/fieldnode; DRAWING NO. FND-DWG-010; REV P1; SHEET 1 of 1; SIZE ANSI B; SCALE 1:10; UNITS mm; PROJECTION; DRAWN Amish Chadha; Licensed CERN-OHL-S-2.0 · Design Molecule Lab · designmolecule.com; Generated from cad/src; do not edit by hand

Scale 1:10; looking down (along -Z)

Not to scale; grey is for scale; seen from the front right and above, about 30 deg elevation

KEY FIGURES
Enclosure 150 x 90 x 200 mm, IP65; 6 W, 9 V class panel as rain hood
LiFePO4 cell 3.2 V, 6 Ah, about 19 Wh; charging 0 to 45 °C only
Worst month: 7.75 Wh/day stored against 2.67 Wh/day drawn
Published sensor allowance 100 mW; 5.75 days with no sun
LoRaWAN US915 every 15 min at SF9; $139.50, 2.45 kg; shield above 30 °C

Scale 1:10; looking at the front (along +Y)

Scale 1:10; looking at the right side (along -X)

Pole-mounted solar sensor node concept

MATERIAL / NOTES
Massing model for concept communication

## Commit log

2026-09-25 Initial scaffold: standard open hardware layout, CERN-OHL-S v2 + MIT licenses
    Claude-Session: https://claude.ai/code/session_01XuhhSU4W6fYhgCfURbrkut
    [bom.csv]
2026-09-25 Populate to TRL 2: problem, requirements, precis, concept media, BOM and README use cases
    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
    [bom.csv]
2026-09-26 Advance to TRL 3: DDR-001, CAL-001 sizing, parametric model with STEP/STL, GA drawing, priced BOM; TRL 4 on hold
    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
    [bom.csv, fieldnode-assembly.step, fieldnode-assembly.stl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]
2026-09-26 Accept all recommendations (DDR-002), switch footer to designmolecule.com, add README write-up with new inspiration point
    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
    [bom.csv, fieldnode-assembly.step, fieldnode-core.step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]
2026-09-27 Product appearance model and photoreal renders
    Adds cad/src/product_model.py (appearance model for renders only, all main
    dimensions from model.py) and Blender renders in media/render-*.png,
    captioned with the project, repository and viewing direction. README leads
    with the product render; trl stays 3.
    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
2026-10-01 Kit 1.7.0: constructable design, illustrated build plan and design decisions register
    The design is now constructable (decision record Design for construction, accepted by Amish on 2026-09-30). docs/05-build-plan.md shows how to make and fit every component, with making sketches, join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
    [bom.csv, fieldnode-assembly.step, fieldnode-assembly.stl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]
2026-10-01 Budget treated as a value-engineering target
    Amish, 2026-10-01: the budget is a hypothetical control target that keeps the design on a value-engineering lens, not a spending limit. Documents now state the value-engineering target and the estima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
2026-10-02 Record Amish's approval of the open-decision recommendations
    Amish approved the recommendation on every open decision in the design decisions register ("i approve your recommendations for all 555 open decisions.", 2026-10-02). Each decision is moved to Decisio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
2026-10-03 Carry approved follow-ups into the design and redo photoreal renders
    Amish approved the follow-up actions from the open-decision sign-off ("APPROVED CHANGES, COMPLETE THESE", 2026-10-02), the design-for-construction change tables in ten repos, the last wave's open dec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
    [bom.csv, fieldnode-assembly.step, fieldnode-assembly.stl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]

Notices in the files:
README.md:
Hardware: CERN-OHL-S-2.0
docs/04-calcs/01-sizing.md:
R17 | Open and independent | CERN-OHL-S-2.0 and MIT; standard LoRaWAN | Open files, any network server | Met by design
